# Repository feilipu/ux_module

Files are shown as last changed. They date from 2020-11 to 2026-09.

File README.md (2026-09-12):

# User Experience Module

User Experience Module is designed to use with the RC2014.

It provides a VGA output, and PS/2 keyboard input. It also provides a FTDI Basic serial connector, which normally operates in parallel to the VGA/keyboard.

It is designed to operate as an MC68B50 ACIA device (the standard RC2014 Serial Module), so that it can be used without modifying the standard ROMs in circulation.



## Pictures

<div>
<table style="border: 2px solid #cccccc;">
<tbody>
<tr>
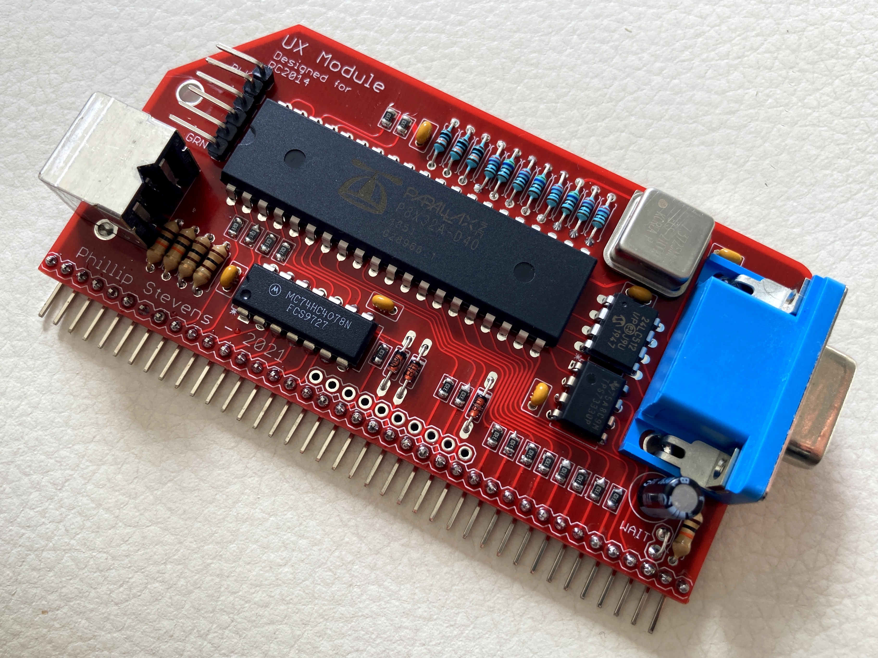
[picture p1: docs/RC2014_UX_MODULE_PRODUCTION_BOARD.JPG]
<td style="border: 1px solid #cccccc; padding: 6px;"></td>
</tr>
<tr>
<th style="border: 1px solid #cccccc; padding: 6px;"><centre>User Experience Module for RC2014 - Production</center></th>
</tr>
</tbody>
<tbody>
<tbody>
<tr>
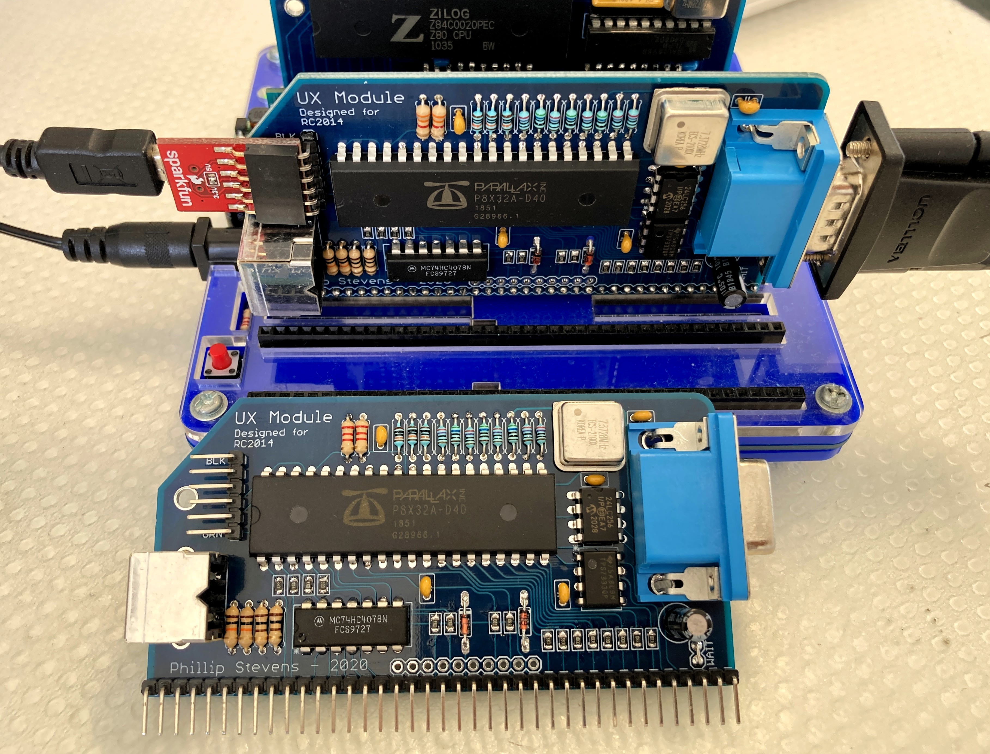
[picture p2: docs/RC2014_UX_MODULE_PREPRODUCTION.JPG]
<td style="border: 1px solid #cccccc; padding: 6px;"></td>
</tr>
<tr>
<th style="border: 1px solid #cccccc; padding: 6px;"><centre>User Experience Module for RC2014 - Pre-Production</center></th>
</tr>
</tbody>
<tbody>
<tr>
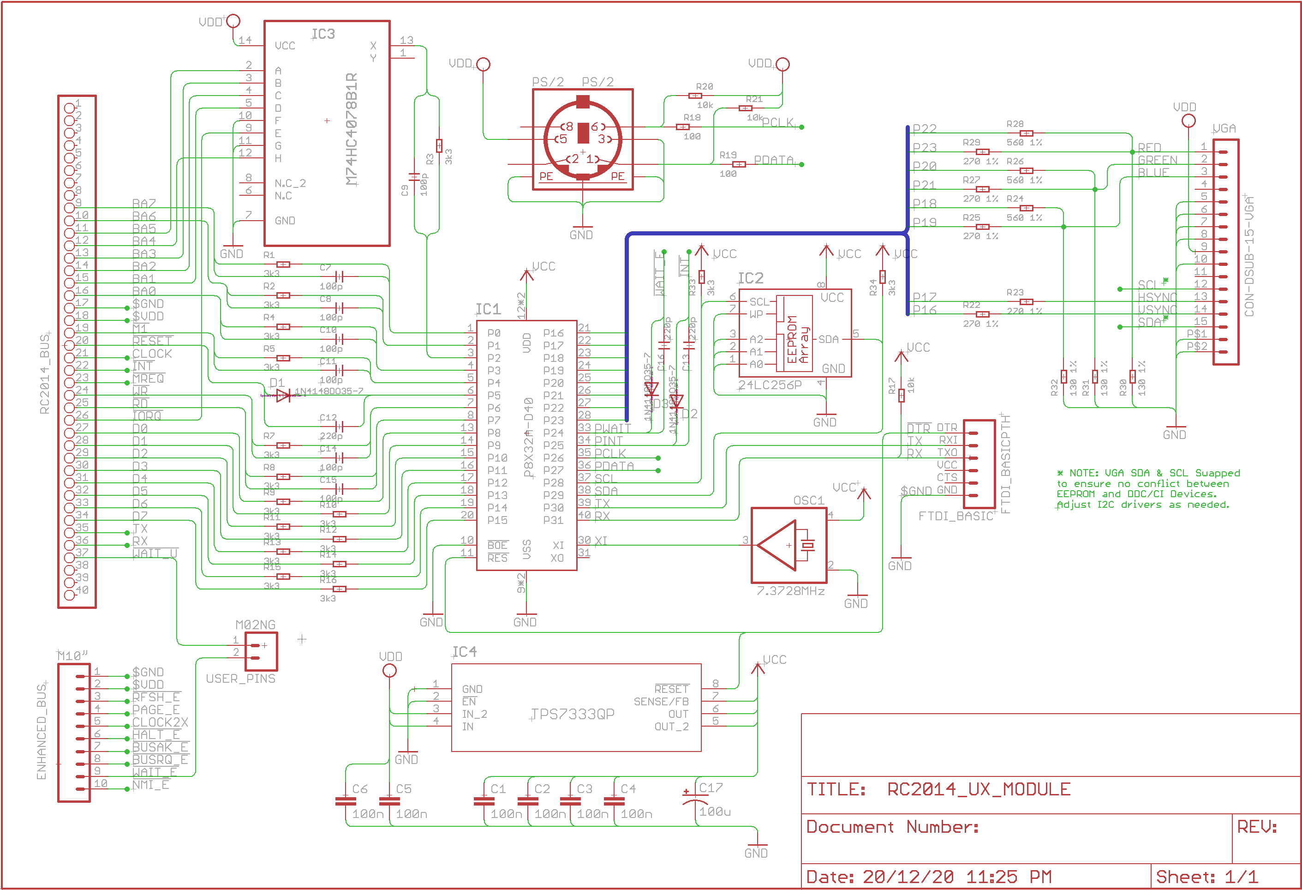
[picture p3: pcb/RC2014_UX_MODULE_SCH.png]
<td style="border: 1px solid #cccccc; padding: 6px;"></td>
</tr>
<tr>
<th style="border: 1px solid #cccccc; padding: 6px;"><centre>User Experience Module for RC2014 - Production Schematic</center></th>
</tr>
</tbody>
</tbody>
<tbody>
<tr>
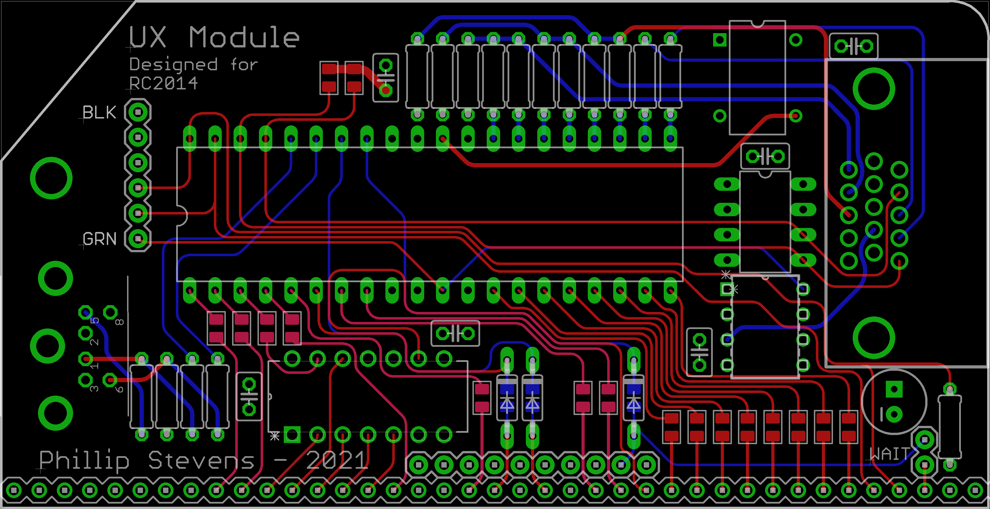
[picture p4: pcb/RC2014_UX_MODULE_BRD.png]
<td style="border: 1px solid #cccccc; padding: 6px;"></td>
</tr>
<tr>
<th style="border: 1px solid #cccccc; padding: 6px;"><centre>User Experience Module for RC2014 - Production Board Layout</center></th>
</tr>
</tbody>
</table>
</div>

## Supported System ROMs

### RC2014 Standard

The UX Module emulates an ACIA interface on base port `0x80`, as per the standard RC2014 usage. Ports `0x80` and `0x81` are required for the implementation.

This supports the use of [standard RC2014 ROMs](https://github.com/RC2014Z80/RC2014/blob/master/ROMs/Factory/README.md) for MS Basic and CP/M as distributed. These ROMs include:

 - R - Microsoft BASIC, for 32k RAM, 68B50 ACIA, with origin 0x0000
 - K - Microsoft BASIC, for 56k RAM, 68B50 ACIA, with origin 0x0000
 - 1 - CP/M Monitor, for pageable ROM, 64k RAM, 68B50 ACIA, CF Module at 0x10, with origin at 0x0000
 - 88 - Small Computer Monitor for pageable ROM, 64k RAM, SIO/2 or 68B50 ACIA, with Microsoft BASIC and CP/M boot options
 - 9 - Small Computer Monitor for any ROM, any RAM, any UART

### CP/M-IDE

The [CP/M-IDE for ACIA](https://github.com/RC2014Z80/RC2014/tree/master/ROMs/CPM-IDE) can be used where an [IDE Interface Module](https://www.tindie.com/products/semachthemonkey/rc2014-ide-hard-drive-module/) is available.

### RomWBW

[RomWBW](https://github.com/wwarthen/RomWBW) is supported, and the UX Module appears as an ACIA port. The UX Module was not compatible with the ACIA device detection mechanism in the 3.0.1 Release, due to the UX Module's tight addressing. However, the device detection mechanism has been improved in the 3.1.1 development branch and it works with the UX Module.

An optimal configuration of RomWBW is to have the UX Module mapped to `0x40`, and a SIO Module providing `TTY` ports. The minimal boot message for this looks like this...

```sh

RomWBW HBIOS v3.1.1-pre.43, 2021-02-11

RC2014 Z80 @ 7.372MHz
0 MEM W/S, 1 I/O W/S, INT MODE 1, Z2 MMU
512KB ROM, 512KB RAM

ACIA0: IO=0x40 ACIA MODE=115200,8,N,1
SIO0: IO=0x80 SIO MODE=115200,8,N,1
SIO1: IO=0x82 SIO MODE=115200,8,N,1
MD: UNITS=2 ROMDISK=384KB RAMDISK=256KB
PPIDE: IO=0x20 PPI NOT PRESENT

Unit        Device      Type              Capacity/Mode
----------  ----------  ----------------  --------------------
Char 0      ACIA0:      RS-232            115200,8,N,1
Char 1      SIO0:       RS-232            115200,8,N,1
Char 2      SIO1:       RS-232            115200,8,N,1
Disk 0      MD1:        RAM Disk          256KB,LBA
Disk 1      MD0:        ROM Disk          384KB,LBA

RC2014 Boot Loader

Boot [H=Help]:
```

To ensure that the UX Module appears as the console port, the console port must be manually set to prefer the UX Module (ACIA) using the `BOOTCON` configuration. The key elements of the configuration file are noted below.

```sh
UARTENABLE  .SET    FALSE       ; UART: DISABLE 8250/16550-LIKE SERIAL DRIVER (UART.ASM)
;
ACIAENABLE  .SET    TRUE        ; ACIA: ENABLE MOTOROLA 6850 ACIA DRIVER (ACIA.ASM)
ACIA0BASE   .SET    $40         ; ACIA 0: REGISTERS BASE ADDR TO AVOID SIO/2 BASE ADDRESS
;
SIOENABLE   .SET    TRUE        ; SIO: ENABLE ZILOG SIO SERIAL DRIVER (SIO.ASM)
SIOCNT      .SET    1           ; SIO: NUMBER OF CHIPS TO DETECT (1-2), 2 CHANNELS PER CHIP
;
TMSENABLE   .SET    FALSE       ; TMS: DISABLE TMS9918 VIDEO/KBD DRIVER (TMS.ASM)
;
BOOTCON     .SET    2           ; SET ACIA AS CONSOLE, ASSUMING 1 SIO/2 MODULE CONFIGURED WITH 2 CHANNELS
```

## Construction

Building the UX Module is fairly straightforward. Some notes are included below describing options and potential issues that may arise.

### BOM

The BOM for the UX Module can be found in the Production PCB section of this repository, both listing [by parts](https://github.com/feilipu/ux_module/blob/main/pcb/RC2014_UX_MODULE_ListByParts.csv), and listing [by values](https://github.com/feilipu/ux_module/blob/main/pcb/RC2014_UX_MODULE_ListByValues.csv).

Also, a complete ordering [Cart is available at Digikey AU](https://www.digikey.com.au/short/47vbdp).

Note that the 74HC4078 NOR device is not included in the Digikey BOM. This device is obsolete, but can be obtained from UT Source or other ebay sources (or as an option on Tindie).

Note that sockets are not included in the BOM, but can be used if desired. See the notes on Overclocking below.

### SMD

Soldering the SMD devices is fairly straightforward. The resistors go on the front of the board. They are not polarised, but if you are concerned with neatness they can all be aligned so they face the same way. The capacitors go on the back of the board. The 3x 220pF capacitors are mounted behind the diodes, and this can be noted because of the through-hole on either side of the mounting location.

There are many techniques for soldering SMD. For a simple tutorial using a standard fine tipped soldering iron and a pair of tweezers, [please refer to this video](https://youtu.be/t7WQLCaeAjM).

### EEPROM I2C

The Parallax Propeller MCU stores its firmware in an external I2C EEPROM. The minimum requirement is for 256kb size (32kB), but the bootloader also supports 512kb size (64kB) devices. Either device is suitable for the UX Module. If you are interested to do additional coding it might be sensible to equip the 512kb device.

There is no need to put the EEPROM in a socket, as it can be programmed in-situ about a million times (literally) and you're never going to need to exchange it.

The bootloader uses P28 as SCL and P29 as SDA. VGA DDC on this board is swapped (P29 SCL, P28 SDA). That match is VGA pin 15 and pin 12. A monitor EDID chip then does not ACK during boot. After boot, `i2c.startCog` in `ddc_i2c.spin` uses that swapped pair to read the display. Do not use that cog to talk to the 24LC256.

### Overclocking

The Parallax Propeller is specified to run at 80MHz. The typical mechanism to achieve this is to provide a 5MHz crystal or oscillator and use the Propeller internal 16x PLL capability to generate the 80MHz system clock.

Of course this specification can be stretched and the maximum system clock seems to be about 120MHz, noting that this is right on the edge of the capabilities.

The UX Module is expecting a 7.3728MHz oscillator, the same standard clock as the RC2014 Z80, which produces a 118MHz Propeller system clock.

It is possible to use a slower oscillator at 5MHz, or 6.25MHz, or other if desired, or in the unlikely event your selected Propeller device doesn't work at 118MHz. In this case the clock rate specification [`_xinfreq`](https://github.com/feilipu/ux_module/blob/main/src/ux_module.spin#L12) will have to be adjusted in the firmware to suit, and the VGA video timing will need to be adjusted to suit. If you are concerned about this it would be sensible to mount the oscillator in a socket to enable it to be simply swapped as needed.

## Firmware Development

The UX Module firmware is developed in Propeller SPIN, and in Propeller Assembly (PASM). The individual functions are mainly built in PASM, with connecting higher level logic running in SPIN.

### Development Environment (humans)

There are a number of alternative programming environments for the Parallax Propeller. The PropellerIDE was defined as the default option, and was developed to be cross-platform capable. However, other solutions supporting SPIN, PASM, and C or C++ are also available.

The UX Module is developed using the PropellerIDE, and therefore support will only provided for issues with that platform.

The [PropellerIDE](https://developer.parallax.com/propelleride/) is available for Windows, OS X, Linux, and packaged for debian.

### Command-line build (humans, agents, and scripts)

Use the CLI toolchain. PropellerIDE remains valid for interactive work. Both paths target **Propeller 1 (P8X32A)** only. Do not use Propeller 2 loaders (`loadp2`) or PASM2.

| Tool | Role | Source |
|---|---|---|
| [OpenSpin](https://github.com/parallaxinc/OpenSpin) (`openspin`) | Compile Spin and PASM to a `.binary` or `.eeprom` image | Build from source (for example `~/Projects/OpenSpin`) |
| [PropLoader](https://github.com/parallaxinc/PropLoader) (`proploader`) | Load the image over FTDI FT232 (DTR reset) | Build from source (for example `~/Projects/PropLoader`) |
| `tools/ux-load.sh` | EEPROM load + run on `/dev/cu.usbserial-*` | This repository |
| `tools/ux-screen.sh` | 115200 FTDI console. Holds DTR off | This repository |
| `rc-screen` (`tools/rc-screen.sh`) | 115200 ACIA console on USB CDC. Direct GNU `screen` | `$HOME/bin` |

Copy this block. Quit GNU `screen` first (`C-a k`). The serial port must be free.

```sh
mkdir -p build
openspin -L src -b -o build/ux_module.binary src/ux_module.spin
tools/ux-load.sh
tools/ux-screen.sh
```

Top object is `src/ux_module.spin`. Product search path is `-L src` only. Add `-L src/lib_vjet` only for a VECTORJET demo top.

`tools/ux-load.sh` writes EEPROM then runs. It uses DTR reset (SparkFun FTDI Basic pin 6). It refuses USB CDC (`/dev/cu.usbmodem*`). CDC is console only.

Same load without the helper. Adjust the device from `proploader -P`. Prefer `/dev/cu.*` over `/dev/tty.*` on macOS.

```sh
proploader -p /dev/cu.usbserial-XXXX -e -r build/ux_module.binary
```

Full helper notes, VECTORJET compile, and screen keys: [`tools/README.md`](tools/README.md). Agent rules: `AGENTS.md`, `.agents/skills/tool-propeller/`, and `.agents/skills/tool-rc-screen/`.

### Programming Interface

The UX Module provides a standard FTDI Serial interface for programming. This can optimally be at 3V3, but also works at 5V. References to "Prop Plug" in the PropellerIDE should be taken to mean the FTDI Serial device that you're using. The same FTDI FT232 path is what `proploader` uses from the command line.

When programming the UX Module firmware with PropellerIDE, it is important that the [upper level code](https://github.com/feilipu/ux_module/blob/main/src/ux_module.spin) be the active window when clicking "compile and upload". The PropellerIDE will compile and upload a sub-module file if it thinks this is what you wanted (because you left it in the foreground). Of course this will lead to things not working as expected. You'll just need to do it again with the upper most code in the foreground.

### Source Code Hierarchy

Propeller SPIN works with modules which help to mask details from driver code from upper level code.

To implement the functions required for the UX Module several SPIN/PASM modules previously written for Propeller by Parallax have been used. This means that the pretested modules from the Parallax "Object Exchange" are used, and that we can focus on how these modules are integrated.

The only (at this stage) special PASM functions written for the UX Module are in the implementation of the ACIA MC6850 Serial Interface. These are in the [ACIA module](https://github.com/feilipu/ux_module/blob/main/src/acia_rc2014.spin).

`ddc_i2c.spin` also runs a Spin cog after boot. It talks to the monitor on the VGA DDC pins (swapped vs the boot EEPROM). It reads EDID at `0x50` and, if the display answers, DDC/CI at `0x37`. It does not change VGA timing.

VECTORJET (`src/lib_vjet`) is not linked from the product top. Boot is text VGA only. Compile VECTORJET demos with their own tops.

```
ux_module
|
|---> terminal_ftdi 
|---> keyboard_ps2
|---> acia_rc2014
|---> ddc_i2c
|---> wmf_terminal_vga
      |
      |---> hires_text_vga
```

## Usage Notes

When the UX Module has been programmed successfully, it should boot with `UX Module Initialised` appearing on both VGA interface (screen) and on the FTDI Serial interface.

To reboot the UX Module the `DTR` on the FTDI interface needs to be toggled. This can be done with the PropellerIDE, or with any serial terminal that can trigger `DTR` toggle. This functionality is used by the Arduino family, so the function is quite common within serial terminals.

To reboot the UX module if operating stand-alone, the DTR (`GRN`) pin can be touched to the ground (`BLK`) pin on the serial interface, or alternatively touched to the grounded case of the PS/2 keyboard connector.

Once the UX Module is running the ACIA emulation is enabled, so the RC2014 Z80 can now be rebooted. This can be done by pressing the RESET button on the RC2014 or, if a PS/2 keyboard is attached, by pressing `CTRL+ALT+DEL`. This will now initiate a normal RC2014 boot sequence.

This video below shows the expected output of a session.

UX Module for RC2014 Operation (https://www.youtube.com/watch?v=dZT0yxjd9zs)
<BR>
CLICK IMAGE TO VIEW!

### Ports

The UX Module emulates an ACIA interface on base port `0x80`, as per the standard RC2014 usage. Ports `0x80` and `0x81` are required for the implementation.

The UX Module can be alternately located on ports `0x40`, `0x41` or on `0xC0`, `0xC1`.

It will (enhancement plan) be possible to implement a graphics interface (VJET library). It is likely that the graphics interface will use the `0xC0` and `0xC1` ports, and may be configured by settings on other ports.

`PORT_VJET` in `ux_module.spin` is that reserved `0xC0` base. There is no Z80 command protocol in the tree yet. Boot remains the ACIA text console.

### Video VGA

If you do not have a VGA monitor, it is possible to attach a VGA->HDMI adaptor. The VGA connector on the UX Module supplies 5V to the adaptor so no additional power connection (via USB) is required. The recommended VGA->HDMI adaptor is from [Vention and is available here](https://www.aliexpress.com/item/32844619223.html).

The VGA timings (front porch and back porch) have been developed using the Vention HDMI adaptor. If an alternative HDMI adaptor or actual VGA monitor is used, the timings may need to be adjusted to ensure that all characters are visible.

The active text table in `hires_text_vga.spin` is 640×480 at about 70 Hz (80×40 characters). Other Chip Gracey tables (1024×768, 800×600, 640×480 at 85 Hz) are in the same file, commented out. Timing is compile-time. EDID reports the preferred mode. DDC/CI cannot set resolution or aspect. Many HDMI adaptors answer EDID and do not answer DDC/CI (`0x37`).

### Keyboard PS/2

The keyboard is presumed to be a [USA standard](https://github.com/feilipu/ux_module/blob/main/src/keyboard_ps2.spin) keyboard. Alternate key maps are possible, and can be added to your own build of the firmware.

### RC2014 Bus Tx/Rx Line Conflict

When multiple serial Modules are used on one RC2014 Backplane, there is a potential for conflict on the Tx/Rx lines, Pin 35 and 36. Conflict on the the Bus Tx/Rx lines will prevent the RC2014 from booting correctly.

The UX Module is connected to the RC2014 Bus serial Tx and Rx lines. When using the UX Module with other serial Modules (such as the SIO/2 Module), it is necessary to disconnect one or other of the serial Modules. In practice the easiest way to do this is to straighten either the UX Module or SIO/2 Module Tx and Rx pins sufficiently so that they do not insert into the Bus connector.

## Errata Propeller /RESET Pin

The Propeller MCU `/RESET` pin is driven by the serial interface `DTR` pin, which is normally held high when the port is ready. However sometimes both Linux (MacOS) and Windows toggle `DTR` when opening a new serial interface. This impacts our ability to use the serial interface to upload code to the RC2014.

There are several options proposed on the internet to avoid this issue (mainly driven by Arduino users wanting to have "long running" code). The solutions are written into [`tools/serial_tool.py`](tools/serial_tool.py), which is included to simplify uploading BASIC programs to the RC2014.

For some machines, none of the software options work so the final solution is to bend the `DTR` pin out from the FTDI connector. Then an optional connection can be provided to enable Propeller reprogramming. Photos demonstrating one method to do this are provided in the [`docs`](https://github.com/feilipu/ux_module/tree/main/docs) directory.

## Code of conduct

See the [Code of Conduct](https://github.com/feilipu/ux_module/blob/main/CODE_OF_CONDUCT.md).

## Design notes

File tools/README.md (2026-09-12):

# Compile, load, and console

Copy these commands from a clone of this repository. Product firmware is Propeller 1 only (`P8X32A`).

Put `openspin` and `proploader` on `PATH`. Build notes: `.agents/skills/tool-propeller/SKILL.md`.

Quit GNU `screen` before a load (`C-a k`). `tools/ux-load.sh` then stops the FTDI relay so the port is free.

Two consoles: `ux-screen` is SparkFun FTDI (DTR is `/RES`, relay). `rc-screen` is RC2014 ACIA on USB CDC (direct attach). Both live in `$HOME/bin`.

## Product firmware

Top object: `src/ux_module.spin`. Search path: `-L src` only.

```sh
cd /path/to/ux_module
mkdir -p build
openspin -L src -b -o build/ux_module.binary src/ux_module.spin
tools/ux-load.sh
tools/ux-screen.sh
```

`tools/ux-load.sh` writes EEPROM and then runs. It uses DTR reset on `/dev/cu.usbserial-*` (SparkFun FTDI Basic pin 6). It refuses `/dev/cu.usbmodem*` (USB CDC). That path is console only.

```sh
tools/ux-load.sh /dev/cu.usbserial-XXXX
tools/ux-load.sh -m                       # hand pulse /RES
tools/ux-screen.sh /dev/cu.usbserial-XXXX
tools/serial_probe.py $'ABC123\r'         # headless TX/RX log, DTR held off
```

Same load without the helper:

```sh
proploader -P
proploader -p /dev/cu.usbserial-XXXX -e -r build/ux_module.binary
```

## VECTORJET demo (not the product top)

```sh
openspin -L src -L src/lib_vjet -b -o build/vjet_test.binary src/lib_vjet/vjet_test.spin
```

## Console keys (`tools/ux-screen.sh`)

| Key | Action |
|-----|---|
| `C-a k` | Quit screen (do this before `ux-load.sh`) |
| `C-a d` | Detach |
| `C-a s` | XMODEM send (`lsx -b -q -X`). Type the file path. |
| `C-a r` | XMODEM receive (`lrx -b -q -X`) |

If `lsx`/`lrx` exits and the window no longer takes keys, quit (`C-a k`) and run `tools/ux-screen.sh` again. Apple `/usr/bin/screen` used to wrap `exec` in `login`. `tools/screenrc-ux` now sets `deflogin off`.

Do not pass baud flags to GNU `screen` on the PTY. Apple `screen` then treats that node as a modem and can raise DTR or send a break. `tools/ux-screen.sh` runs `stty -ixon` on the PTY. An XOFF byte from the 8085 then does not block host keys.

`tools/ux-ftdi-relay.py` holds DTR off. macOS asserts DTR on open of `cu.usbserial-*`. That pin is Propeller `/RES`. The relay stays up after you quit `screen`. A later `ux-screen` does not reopen the FTDI. The GNU `screen` session name is `uxmod`. A second `ux-screen` reattaches that session. The first start after a USB plug or `ux-screen.sh --stop` still pulses `/RES`. `tools/ux-load.sh` stops the relay, then uses DTR for the download.

Older pyserial helpers (Linux `/dev/ttyUSB0` in the source): `tools/serial_dtr.py` pulses DTR. `tools/serial_tool.py` writes stdin to the port and comments HUPCL options. Prefer `tools/ux-load.sh` and `tools/ux-screen.sh` on macOS.

## RC2014 ACIA console (`rc-screen`)

GNU `screen` opens the USB CDC node (`/dev/cu.usbmodem*`) directly. There is no FTDI relay and no `serial_probe`. The session name is `rc2014`.

General command: `$HOME/bin/rc-screen`. Config: `$HOME/.screenrc-rc`. In-tree copies: `tools/rc-screen.sh` and `tools/screenrc-rc`.

This is the CP/M console on the 8086 Consultancy USB-C stick. Do not use this script on `/dev/cu.usbserial-*`. That FTDI pin 6 is Propeller `/RES`. Use `ux-screen` for the SparkFun port.

```sh
rc-screen
rc-screen /dev/cu.usbmodem01031
rc-screen --list
rc-screen --quit
```

Sockets are in `$HOME/.screen-rc2014`. A bare `screen -S rc2014` looks in `$TMPDIR/.screen` and misses the session. Use `rc-screen --quit` to stop it.

A terminal attaches. With no TTY the script starts a detached session. One session only.

Same keys as `ux-screen`: `C-a s` send, `C-a r` receive. The screenrc sets `deflogin off` and unbinds XON.

Host send after CP/M `xmodem NAME /r /q`:

```sh
rc-screen --send /path/to/file.com
rc-screen --send --1k /path/to/file.com
```

`--send` waits one second so CP/M is in receive first. The script starts `screen` with `115200,cs8,-ixon,-ixoff`. A missing baud flag makes Apple `screen` reset the node to 9600.

If `ux-ftdi-relay` holds the same CDC node, quit session `uxmod` and run `ux-screen --stop` first. Do not run both scripts on one node.

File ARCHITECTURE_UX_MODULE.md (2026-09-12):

# Architecture — UX Module firmware

This note describes the production firmware under `src/` (not `src/lib_vjet`).  
MCU: **Parallax Propeller 1 (P8X32A) only** — not Propeller 2.  
Agent edit rules: `.agents/skills/module-ux`, `hw-ux-pcb`, `lang-spin`, `lang-pasm`, `tool-propeller`.  
Prose style: `.agents/skills/style-ste-writing`.

## Purpose

The UX Module is an RC2014 board that presents:

- VGA text console
- PS/2 keyboard
- FTDI serial (programming + parallel console)
- An MC6850-compatible ACIA on the Z80 I/O bus

Host software can use stock RC2014 ROMs that expect a 68B50 ACIA. The Propeller P8X32A runs the firmware. Primary product documentation is `README.md`. Board files are under `pcb/`. Chip and language manuals are under `docs/`.

## Clock

The board uses a 7.3728 MHz oscillator. Firmware sets `XTAL1 + PLL16X`, so the system clock is about 118 MHz. VGA pixel-rate constants in `hires_text_vga.spin` assume that clock. A different oscillator needs a new `_xinfreq` and new video timing.

## Object hierarchy

```
ux_module.spin
├── terminal_ftdi.spin      Full-duplex UART on P31/P30 (Prop Plug pins)
├── keyboard_ps2.spin       PS/2 decode on P27 data / P26 clock
├── acia_rc2014.spin        6850 register and bus timing emulator
├── ddc_i2c.spin            DDC EDID / DDC/CI Spin cog (P29 SCL / P28 SDA, swapped)
└── wmf_terminal_vga.spin   Screen buffer, colours, terminal print helpers
    └── hires_text_vga.spin Dual-cog VGA text engine (Parallax / Chip Gracey)
```

Compile and upload with `ux_module.spin` as the top object. Use `-L src` only. VECTORJET lives under `src/lib_vjet` with its own demo tops. The product top does not link it.

## Pin roles (summary)

| Function | Pins |
|---|---|
| ACIA address and control | P0–P7 (A7, A6, NOR decode, A0, /M1, /RESET, /WR, /RD) |
| ACIA data | P8–P15 |
| VGA | P16–P23 |
| /WAIT, /INT | P24, P25 (open-collector via diodes) |
| PS/2 | P26 clock, P27 data |
| I2C EEPROM (bootloader) | P28 SDA, P29 SCL |
| VGA DDC (after boot) | P29 SCL, P28 SDA (`ddc_i2c.spin`). Swapped so EDID does not ACK the bootloader. |
| FTDI | P30 TX, P31 RX |

The 74HC4078 NOR combines `/IORQ` with A5–A1 so one Propeller pin can detect the ACIA I/O page. Detail: skill `hw-ux-pcb` and comments in `acia_rc2014.spin`.

## Cog map

Typical production start order in `ux_module.main`:

1. FTDI terminal cog (`terminal_ftdi.start`)
2. ACIA cog (`acia.start`)
3. Two VGA text cogs (`wmf.init` → `hires_text_vga.start`)
4. DDC I2C cog (`i2c.startCog` in `ddc_i2c.spin`) after VGA so the monitor is alive
5. PS/2 cog (`kbd.start`)
6. 1 ms Z80 `/RESET` pulse. Discard FTDI RX and restart the ACIA cog while held. A backplane `/RESET` button is sampled on P5 (1 ms debounce) and uses the same wipe. It does not reset the Propeller.
7. Cog 0 remains in the main Spin loop (`kbdToZ80`, `termToZ80`, `readZ80`)

Text mode uses seven of eight cogs. I2C is a Spin cog, not PASM. It reads EDID and DDC/CI. It does not change VGA timing. The spare cog is unused. Only the main cog calls `acia.tx`. Main skips `kbdToZ80` during a Z80→host XMODEM session (`z80XmSess`, including the ACK gap) and a host→Z80 packet session (`hostXm <> OFF`). Trailer bytes are counted, not sniffed. DDC still runs while the 8085 is live. Do not hold `/RESET` across DDC.

## Data paths

```
Keyboard  →  kbdToZ80  ─┐
                        ├─ acia.tx → ACIA transmit FIFO → Z80 IN data
FTDI RX   →  termToZ80 ─┘
Z80 OUT data  →  ACIA receive FIFO  →  readZ80  →  VGA + FTDI TX
```

`readZ80` is a non-blocking parser. It pumps bytes already in the FIFO. LF still drains when FTDI TX is full. Other bytes wait for FTDI room. If the next byte will not fit, `readZ80` holds ACIA `TDRE`. There is no XON/XOFF on FTDI. The FTDI RX cog drops inbound bytes when its FIFO is full. The 6-pin header does not wire CTS or RTS to the Propeller, so the host cannot be paused in hardware.

Naming trap: from the Z80, “receive data register” is filled by the Propeller **transmit** FIFO (`tx_*`). “Transmit data register” writes enter the Propeller **receive** FIFO (`rx_*`).

## ACIA emulation

`acia_rc2014.spin` runs a PASM cog that:

1. Waits for the decoded address match (including `/M1` high for I/O)
2. Pulls `/WAIT` so the Z80 stretches the cycle
3. Services status/control at base+0 or data at base+1
4. Releases `/WAIT` and returns to wait

A real MC68B50 places data in 150 ns or less. This cog is slower, so P24 stretches the Z80 I/O cycle. Address detect uses `WAITPNE` then `waitpeq outa, port_active_mask wr`. The `wr` effect adds the mask into `OUTA`. Bit 24 was already 1, so the add drives `/WAIT` low in that instruction.

Carry hits bit 25 (`/INT`). The next instruction clears that bit. Do not drop `wr`. Loop rules live in `.agents/skills/lang-pasm/references/acia-wait.md`.

Status and control bits follow the Motorola 6850 model (`docs/MC6850.pdf`) at a practical level. FIFOs stand in for the UART. Clock divide, word select, and Break are not driven. PE, FE, CTS, and DCD stay 0. Default base is `0x80`. RomWBW setups may use `0x40` when an SIO owns `0x80`.

FIFOs are 512 bytes each. Z80 receive is the Propeller `tx_*` FIFO (`RDRF`). Z80 transmit is the Propeller `rx_*` FIFO (`TDRE`). Spin `tx` and `rx` move bytes. `sync_irq` writes `acia_status` on a status read.

PASM holds `/INT` low while RIE or TIE match the flags. Spin also pulses `DIRA[25]` when RIE or TIE, so a key is seen while PASM is in `waitpeq`. `/RTS` is the CR5/CR6 field. Master reset `$03` sets `req_parse_idle` then zeros both FIFOs. It does not clear `tdre_hold`. Boot pulse and CTRL+ALT+DEL hold P5 for 1 ms, discard host RX, and restart the ACIA cog so FIFOs and `last_rdr` are zero. Then `tdreHold` until FTDI has room. Do not wait on `req_master`. An empty or `/RTS`-high RDR read presents the last byte and does not move `tx_tail`. A full TDR write is dropped and does not set `OVRN`. Spin `tdreHold` writes Hub `tdre_hold` so PASM keeps `TDRE` clear. Detail and revert notes: `.agents/skills/module-ux`. RomWBW and CPM-IDE ACIA clients: `.agents/skills/module-ux/references/acia-host-drivers.md`.

## FTDI UART cog

`terminal_ftdi.spin` keeps receive and transmit in **one** PASM cog with `JMPRET` coroutines (Parallax AN014 pattern on OBEX). Bit timing uses `CNT` deadlines. That saves a cog versus two separate UART cogs.

## VGA text path

`wmf_terminal_vga` owns the character buffer, per-row colours, and cursor bytes. `hires_text_vga` reads those Hub structures and generates VGA with two cogs. Resolution and character grid depend on which timing `CON` block is active in `hires_text_vga.spin` (for example 640×480 with 80×40 characters).

The active block is 640×480 at about 70 Hz (VGA 60 Hz 800×525 totals, `pr=28`). EDID preferred timing is reported at boot. It does not retune this table. DDC/CI does not set resolution.

Cursors are six bytes: text X/Y/mode and mouse X/Y/mode. The UX Module uses the text cursor and leaves the mouse cursor disabled. Overlay X/Y copies the WMF column and row after text ops. Idle backspace at column 0 is eaten. The firmware does not guess a shell prompt width.

## Relation to VECTORJET

`src/lib_vjet` is not linked from the product top. Compile VECTORJET demos with their own top objects and `-L src -L src/lib_vjet`. Pins P16–P23 have one owner. See `ARCHITECTURE_LIB_VJET.md`.

## External references

| Doc | Use |
|-----|-----|
| `tools/README.md` | Copy compile, `ux-load.sh`, `ux-screen.sh`, and `rc-screen.sh` |
| `docs/P8X32A-Web-PropellerManual-v1.2.pdf` | Spin and PASM language |
| `docs/Propeller Quick Reference v1.7.pdf` | Opcode and Spin cheat sheet |
| `pcb/P8X32A-Propeller-Datasheet-v1.4.0_0.pdf` | Hub, video, counters, electrical |
| `docs/MC6850.pdf` | ACIA register model |
| `pcb/RC2014_UX_MODULE.sch` | Board connectivity |

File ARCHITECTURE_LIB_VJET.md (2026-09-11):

# Architecture — VECTORJET (`lib_vjet`)

This note describes the 2D/3D scanline engine under `src/lib_vjet`.  
Agent edit rules: `.agents/skills/library-vjet`, `hw-propeller`, `lang-pasm`.  
Prose style: `.agents/skills/style-ste-writing`.

## Purpose

VECTORJET builds a display list in Spin, renders scanlines with one or more PASM cogs, and outputs VGA with a dedicated PASM cog. The UXM-prefixed files are a specialisation for the RC2014 UX Module pinout and clock. Upstream credit in the sources: IRQsome Software, with VGA lineage from Kwabena W. Agyeman / Parallax-style video generators.

The product top `ux_module.spin` does not link this library. Demos use their own top objects (`vjet_test.spin`, `graphtest.spin`). Compile those with `-L src -L src/lib_vjet`.

## Files

| File | Layer |
|---|---|
| `VJET_v01_displaylist.spin` | Spin API: clip, shapes, text, list packing |
| `VJET_vUXM_rendering.spin` | PASM renderer cog program |
| `VJET_vUXM_vga.spin` | PASM VGA output cog |
| `hexfont.spin` | Font blob for text shapes |
| `vjet_test.spin` | Demo: spinning triangles + centred text |
| `graphtest.spin` | Demo: graph-style drawing |

## Runtime pipeline

```
Application (Spin top object)
    │
    │  build display list into back buffer
    │  publish pointer in dlist_ptr
    │
    ├───────────────► Render cog 0 ──┐
    ├───────────────► Render cog 1 ──┼──► shared scanline buffer (Hub)
    └───────────────► Render cog N ──┘              │
                                                    ▼
                                            VGA cog (WAITVID)
                                                    │
                                                    ▼
                                            pins P16–P23 (group 2)
```

`vjet_test.spin` starts three render cogs and one VGA cog. It waits for vertical blank through `vga_status`, publishes the completed list, waits for vsync so the render cogs copy the pointer, then rebuilds the other list.

## Scanline handshake (tear / flicker)

The Hub scan buffer holds **eight** logical lines (`LINE_BUFFERS`). The VGA cog displays line `N` from slot `N & 7` and writes `N` into `vga_status`. During blanking it writes line **240** plus phase bits.

Render cogs:

1. Wait until the status line is `>= 240` (blanking).
2. Fill slots 0..7 while they treat the raster as line 0.
3. Then wait until they are fewer than eight lines ahead of the live VGA line.

Do not publish line 0 during vsync or back porch. The old status longs used a low word of 0. Render cogs treated that as scanline 0, ran 16 lines, and overwrote the first eight slots before active video. A faster system clock (118 MHz vs 80 MHz) made that overrun worse.

Spin must publish `dlist_ptr` at front porch, then wait for vsync bit 17 (`$02_00_00`) before it rebuilds the other list. If Spin rebuilds a list that a render cog still reads, the frame tears.

## Video PLL

`VJET_vUXM_vga` sets CTRA PLL internal, VCO/2. The NCO target is 5 MHz. VCO is 80 MHz (spec 64–128 MHz). PLLA is 40 MHz. VSCL uses 4 clocks per pixel, so the pixel rate is 10 MHz (256-wide VGA).

The old 10 MHz NCO with VCO/4 made VCO 160 MHz. That is out of spec and the PLL can unlock (jitter, tear, roll).

`hires_text_vga` uses a different PLL setup (`pr` in MHz, VCO/2) for 640×480 text. Do not copy VECTORJET FRQA into the text driver or the reverse.

## Resolution and buffers

Rendering constants in `VJET_vUXM_rendering.spin`:

- Width: 256 pixels
- Height: 240 scanlines

The VGA cog repeats each logical line (tile counter) so the analogue timing fills a taller raster. The Hub scan buffer is `linebuffers[(WIDTH*LINE_BUFFERS)/4]` longs (eight line slots).

Display lists are ordinary Hub longs (for example `dlist1[900]`, `dlist2[900]`). Size is a demo choice, not a hardware limit.

## Display list model

Each shape starts with an 8-byte header:

1. Link word to the next shape (0 = end)
2. Sync byte for renderer coordination
3. Shape type byte
4. Start scanline word
5. End scanline word

Types:

| ID | Name | Role |
|----|---|---|
| 1 | Trapezoid stack | Filled poly/triangle decomposition with per-trap slopes |
| 2 | Box | Axis-aligned span with colours |
| 3 | Text | Scaled glyphs from a font pointer + string pointer |

The Spin builder exposes helpers such as `triangle`, `polygon`, `box`, `line`, `point`, and `text_centered`. Many coordinates use 16.16 fixed point. `set_clip` limits geometry. `done` seals the list and breaks the link if the builder ran out of space (`ABORT`).

## Renderer cog behaviour

On `start(cognum, totalcogs, scanbuffer, dlistPtrAdr, videoSync, readyptr)` the object copies parameters into DAT longs and `cognew`s the PASM entry.

Each cog:

1. Waits until `vga_status` low word is `>= 240` (blanking)
2. Reads the current display-list pointer
3. Optionally fixes trapezoids that start above Y0 (top clip)
4. Renders every Nth scanline (`cognum`, `cognum+totalcogs`, …)
5. Writes pixels into the shared scanline buffer for the VGA cog
6. Waits if the next line would wrap onto a slot the VGA cog still displays

Call `render.stop` before you start text VGA on the same pins.

Init instructions are overlaid by live variables after boot. Do not treat early DAT labels as free code space without reading the reuse comments.

## VGA cog behaviour

`VJET_vUXM_vga.start(pinGroup, lineBuffers, statusLong)`:

- Programs `VCFG` for VGA on the selected pin group
- Starts CTRA in PLL video mode
- Loops active lines with `WAITVID`, then front porch, vertical sync, and back porch
- Publishes phase flags in `statusLong` so Spin can wait for blanking
- Writes line 240 during front porch, vsync, and back porch (never line 0)

For the UX Module, demos pass `pinGroup = 16/8` (group 2 → P16–P23), which matches the board VGA connector.

## Integration with UX firmware (exclusive video mode)

Pins P16–P23 have one owner. `hires_text_vga` (two cogs, 640×480 cells) and `VJET_vUXM_vga` (one cog, 256×240 scanlines) must not run at the same time.

| Mode | Video cogs | Other cogs that stay | Free |
|---|---|---|---|
| Text | 2 (`hires_text_vga`) + 1 I2C DDC | Spin, FTDI, ACIA, PS/2 (4) | 1 |
| Graphics | 1 (`VJET_vUXM_vga`) + 2 render | Spin, FTDI, ACIA, PS/2 (4) | 1 (Spin draw) |

The product firmware does not call `enterGraphics`. When graphics work resumes, stop the text pair and `i2c.stopCog` before VECTORJET VGA. Stop VECTORJET, then `wmf.init` and `i2c.startCog`. After `cogstop`, those cogs leave the pins. Then start the other driver.

Do **not** build the display list on Cog 0 if the ACIA pump must stay live. Cog 0 is the only `acia.tx` writer. `vjet_test` blocks Cog 0 in `Vblank` + `draw`. That starves keyboard, FTDI, and Z80 I/O.

Recommended product split:

1. **Text mode** — current `ux_module` path. Z80 console on VGA text.
2. **Graphics mode** — stop text VGA. Start VECTORJET VGA + two render cogs. Start a **second Spin cog** that waits for blanking and builds lists. Cog 0 only pumps ACIA / keyboard / FTDI and writes a small mailbox (camera, mode, flip). That uses all eight cogs: 4 I/O + 1 draw + 1 VGA + 2 render.
3. **Standalone demo** — `vjet_test` / `graphtest` as now (no ACIA). Three render cogs on Cog 0 as the draw loop.

The product top has no graphics hooks. `PORT_VJET` remains a reserved ACIA base. Serial tests use the text boot path.

Hub cost: eight line slots are 2 KB. Two lists of 900 longs are about 7 KB. The text screen is 80×40 bytes plus colours. 32 KB Hub cannot keep a large text buffer and two fat lists at once. Reuse the text screen region for lists when you leave text mode.

`PORT_VJET = acia#PORT_C0` is reserved for a later Z80 command port. There is no I/O protocol in-tree yet. A first protocol can be: command byte, then words that Spin copies into the back list, then a flip at vblank.

## Extension points

Useful work while keeping the architecture intact:

1. When graphics work resumes, start a Spin draw cog (not Cog 0). Wait `vjetStatus` bit 16 (`$01_00_00`), publish the list pointer, wait bit 17 (`$02_00_00`), then `gl.start` on the idle list. See `vjet_test.spin`.
2. Grow Hub lists to two buffers of about 900 longs. Reuse the text screen region if needed.
3. Drive the back list from Z80 I/O at `PORT_VJET` (needs a command protocol)
4. Tune render cog count against available cogs and fill rate
5. Keep display-list field layouts documented in one place (builder comments ↔ renderer reads)
6. Link `hexfont.spin` only when text shapes are required. Do not start VECTORJET from product `main` until that draw cog exists.

## External references

| Doc | Use |
|-----|-----|
| `pcb/P8X32A-Propeller-Datasheet-v1.4.0_0.pdf` §4.10 | Video generator, WAITVID |
| `docs/Propeller Quick Reference v1.7.pdf` | PASM opcodes |
| `ARCHITECTURE_UX_MODULE.md` | Board cog and pin budget |
| Demo sources | `vjet_test.spin`, `graphtest.spin` |

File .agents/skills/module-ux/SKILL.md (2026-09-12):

---
name: module-ux
description: >
  UX Module firmware architecture: ux_module.spin object tree, cog budget,
  ACIA 6850 emulation path, VGA text terminal, PS/2 keyboard, FTDI bridge,
  and Z80 console flow. Use when changing src/ outside lib_vjet, or when
  integrating VECTORJET with the product firmware. See ARCHITECTURE_UX_MODULE.md.
---

# Module — UX firmware

Human architecture note: `ARCHITECTURE_UX_MODULE.md` (repo root). This skill is the agent checklist.

## Object tree

```
ux_module.spin                 ' top object — compile/upload this
├── terminal_ftdi.spin         ' FullDuplex serial on P31/P30
├── keyboard_ps2.spin          ' PS/2 on P27/P26
├── acia_rc2014.spin           ' MC6850 bus emulator (PASM cog)
├── ddc_i2c.spin               ' DDC EDID / DDC/CI Spin cog (P29 SCL, P28 SDA)
└── wmf_terminal_vga.spin      ' terminal services + screen buffer
    └── hires_text_vga.spin    ' dual-cog VGA text (Chip Gracey)
```

Boot is text VGA only. There is no DIAG_ switch. VECTORJET stays under `src/lib_vjet` with its own demo tops. Do not link it from `ux_module.spin` until graphics work resumes (`library-vjet`).

Archive demos under `archive/` are not part of the production tree.

## Cog budget (production path)

| Cog role | Source |
|---|---|
| Spin main (Cog 0) | `ux_module` event loop: `kbdToZ80` / `termToZ80` / `readZ80` |
| FTDI UART | `terminal_ftdi` PASM |
| ACIA bus | `acia_rc2014` PASM |
| PS/2 | `keyboard_ps2` PASM |
| VGA text ×2 | `hires_text_vga` (two cogs) |
| I2C DDC | `ddc_i2c` Spin cog (EDID + DDC/CI). Not the boot EEPROM. |

Text mode uses seven of eight cogs. I2C is a Spin cog, not PASM. The spare cog is unused. Only the main cog calls `acia.tx`. Main skips `kbdToZ80` during a Z80→host session (`z80XmSess`) and a host→Z80 packet session (`hostXm <> OFF`).

## Main loop data paths

```
PS/2 keyboard ──kbdToZ80──┐
                          ├── acia.tx ──► ACIA tx FIFO ──► Z80
FTDI rx ──termToZ80───────┘
Z80 writes data ──► ACIA rx FIFO ──readZ80──► VGA + FTDI
```

Cog 0 is the only `acia.tx` writer. Do not add a pump cog. Each of `kbdToZ80`, `termToZ80`, and `readZ80` moves at most `PUMP_LIMIT` bytes per pass.

`readZ80` is a non-blocking parser (`PARSE_IDLE` / `PARSE_ESC` / `PARSE_CSI` / `PARSE_CSI_M` / `PARSE_XMODEM_*`). Each call uses bytes that are already in the FIFO. Pump `ftdiNeed==0` bytes even when FTDI TX is full. Allow `TDRE` only when the next byte fits.

`inXmodem` is `z80XmSess`: Z80 TDR `SOH`/`STX` until idle `EOT`/`ETB`/`CAN` (includes the ACK gap). Trailer count is 1 (checksum) or 2 (CRC-16 / `STX`). Do not sniff CRC-lo as a new frame. Host `'C'` / `NAK` while not in a host session set CRC vs checksum for the next Z80→host send. `hostXmodem` is `hostXm <> OFF`: packet machine. `EOT`/`ETB`/`CAN` end the session only in the gap, not in payload. Skip `kbdToZ80` if either is true. Ctrl-A (`$01`) still starts a host session. Panic or `$03` clears both.

Arrow, Home, Left, and Right need three FIFO slots (`acia.txSpace >= 3`) before `kbd.getKey`. Other keys need one slot (`acia.txCheck`).

If FTDI TX cannot take the next byte, `readZ80` calls `acia.tdreHold`. `term.rxCount` is a count only. There is no XON/XOFF. FTDI RX PASM drops inbound bytes when that FIFO is full. The header does not wire CTS or RTS.

CTRL+ALT+DEL and boot `pulseZ80Reset`: hold P5 1 ms, discard FTDI RX and PS/2, `acia.start` (new cog: FIFOs and `last_rdr` zero), `tdreHold`, `PARSE_IDLE`, clear `z80XmSess` and `hostXm`, then release P5. Panic also VGA `CS` and FTDI clear if `txSpace => 4`. Backplane `/RESET` does not reset the Propeller. Sample P5 when not driving (D1 pulls P5 high while idle). After 1 ms low, wipe once and skip pumps until P5 is high. Do not drive P5 in reply. Do not wait on `req_master` while P5 is held. Z80 `CR_RESET` sets `req_parse_idle` **then** zeros FIFOs. Keep `tdre_hold`. Spin `tx`/`rx` abort while that flag is set. Do not hold `/RESET` across DDC.

ASCII and XMODEM `CON` names are lookup tables. Do not delete unused names.

Boot banner `"UX Module Initialised"` goes to FTDI and VGA.

## ACIA emulation (agent-critical)

**Tree now:** ACIA PASM is `569cd07` wait (`waitpne` then `waitpeq wr`). Mailbox is 11 longs. Rise wait is `wait_pin_high`. `sync_irq` composes `acia_status` on a status read (after `/WAIT`). `last_rdr` is cog RAM (empty or `/RTS` high rewinds `tx_tail`). Spin pulses `DIRA[25]` when RIE/TIE; it does not RMW `acia_status`. Dropping that pulse drops host keys. Punch list: [references/remaining-errors.md](references/remaining-errors.md).

- One PASM cog watches the decoded I/O address with `WAITPNE` / `WAITPEQ`.
- Match uses `waitpeq … wr` so `/WAIT` asserts via **destination += mask**. Do not drop `wr`. Loop contract: `lang-pasm/references/acia-wait.md`.
- Handler releases `/WAIT` with `or outa, bus_wait` after it places data or captures a write. `/RD` `/WR` rise uses `wait_pin_high` (poll pin and `req_master`). Do not put Hub ops on the match path to `waitpeq … wr`.
- Hub block at `PAR` (11 longs): `rx_head`, `rx_tail`, `tx_head`, `tx_tail`, `acia_base`, `acia_config`, `acia_status`, `buffer_ptr`, `tdre_hold`, `req_master`, `req_parse_idle`, then rx/tx byte FIFOs.
- Perspective: Z80 “receive” is Propeller `tx_*` (host→Z80); Z80 “transmit” is Propeller `rx_*`.
- PASM `sync_irq` is the live writer of `acia_status` (status read, after `/WAIT`). `sync_irq` derives `RDRF` from the TX FIFO and `/RTS`, and `TDRE` from RX room and `tdre_hold`.
- Spin `tx` / `rx` move FIFO indexes only. They abort on `req_parse_idle` / `req_master`. `rxCount` / `rxCheck` / `txCheck` / `txSpace` / `rxPeek` are counts or peeks only. Spin does not RMW `acia_status`.
- `tdreHold` / `tdreAllow` write Hub `tdre_hold` (0/1). They do not write `acia_status`.
- `/RTS` high (`CR_TID_RTS1`): hide `RDRF`, keep FIFO bytes, present `last_rdr`. `/RTS` low: set `RDRF` if the TX FIFO holds data.
- Empty or `/RTS`-high RDR: present `last_rdr`, do not move `tx_tail`. Full TDR: drop the write, do not set `OVRN` (that bit is a receiver error).
- CR5/CR6 is a two-bit field. TIE is the exact value `CR_TIE_RTS0`, not bit 5 alone. Master reset `$03` zeros both FIFOs and sets `req_parse_idle`. It does not clear `tdre_hold`.
- `/INT` level from `sync_irq` on a status read. Spin still pulses `DIRA[25]` when RIE/TIE so the 8085 sees a key while PASM is in `waitpeq`. Do not drop that pulse.

Edit with `lang-pasm` + `hw-ux-pcb`. Datasheet: `docs/MC6850.pdf`. OBEX idioms: `lang-pasm/references/obex-pasm.md`. Host drivers (RomWBW, CPM-IDE 8085) vs this tree: [references/acia-host-drivers.md](references/acia-host-drivers.md).

## Flow and reset decisions (revert notes)

These replace earlier WIP (`ea4502e` XON/XOFF, `569cd07` flow). Change the named rule, then the listed files. Do not restore Spin writes to `acia_status` without a new single-writer design.

| Decision | Current rule | Why | Revert |
|---|---|-----|---|
| Status owner | PASM `sync_irq` is the only writer of `acia_status`. | Spin and PASM RMW lost `RDRF` / `tdreHold` (starve then burst). | Do not give Spin `acia_status` again unless PASM stops writing it. |
| `TDRE` hold | Hub `tdre_hold`. `tdreHold` / `tdreAllow` write that long only. | PASM `receive_data` and Spin `rx` used to set `TDRE` and undo the hold. | Restore only if PASM and `acia.rx` both honour a sticky hold. |
| `OVRN` | Receiver bit only. Full TDR write is dropped. Do not set `OVRN`. | Datasheet `OVRN` is unread RDR, not a TDR overwrite. ROMs that saw `OVRN` read RDR or issued `$03`. | Setting `OVRN` on TDR full is the old leak. Do not restore it. |
| Pump cap | `PUMP_LIMIT` (16) bytes per role per main-loop pass. | Unbounded `termToZ80` delayed `tdreHold`. | Raise or remove the cap if a path needs more than 16 bytes per pass at 115200. |
| FTDI emit | `readZ80` peeks, uses `ftdiNeed`, then `acia.rx`. Idle BS/DEL need 3 TX slots if column > 0, else 0. | `term.tx` blocks. One free slot plus backspace stalled Cog 0. | Blocking `term.tx` from the parser is the old stall. |
| Empty / `/RTS` RDR | Present `last_rdr`. Do not move `tx_tail`. | Datasheet keeps the last byte. `/RTS` high must not consume queued keys. | Presenting `0` and advancing the tail was the empty-FIFO junk path. |
| CTRL+ALT+DEL / boot pulse | Hold P5 1 ms, discard host RX, `acia.start` (FIFOs and `last_rdr` zero), `tdreHold`, parser idle. Panic also VGA `CS` and gated FTDI clear. Then release P5. | Leftover RDR and FTDI RX hang 8085 boot. Do not wait on `req_master`. | 1 ms pulse with no FIFO wipe. |
| Z80 `CR_RESET` | Set `req_parse_idle` first. Zero FIFOs and `last_rdr`. **Keep `tdre_hold`.** | Parser is not a 6850 object. `$03` must not mean “FTDI has room.” Flag-first stops Spin tearing indexes. | Clearing `tdre_hold` on `$03`, or zeroing indexes before the flag. |
| `req_master` sample | Idle poll, `sync_irq`, and `wait_pin_high`. | `waitpeq /RD /WR` ignored `req_master` and deadlocked Cog 0. | Sample only in `sync_irq`. |
| XON/XOFF | Removed. No `term.rxFlow`. FTDI RX drops when full. | Binary XMODEM can contain `0x11`/`0x13`. Host cannot be paused on this header. | Restore `rxFlow` from `ea4502e` only for interactive paste. Wrap-over of FTDI RX. |
| Keyboard vs XMODEM | Skip `kbdToZ80` when `z80XmSess` or `hostXm <> OFF`. | Host payload `EOT` used to unmute the keyboard. Packet gap used to inject keys. | Latch on any UART `EOT`. Gate only `PARSE_XMODEM_*`. |
| Host CR | Z80 CR → `term.newLine` (CR+LF). `ftdiNeed` 2. | PST and typical hosts need CR. | `term.lineFeed` only. |
| Board reset button | Sample P5 when not driving. D1 pulls P5 high while `/RESET` is idle. 1 ms low = backplane pulse. Wipe ACIA once. Do not drive P5. Skip pumps while held. | Button does not reset the Propeller. Leftover RDR hangs 8085 boot. | Idle poll with no debounce, or drive P5 in reply. |

Hub writers and open IDs: [references/remaining-errors.md](references/remaining-errors.md). P0-3: backplane `/RESET` is sampled on P5 with a 1 ms debounce. P0-2 Spin must not wait on `req_master` while P5 is held. P2-2: keep the Spin INT pulse (`not (config & mask)` on the trailing `tx` pulse). Do not idle `sync_irq`. Review checklist: [references/ship-review.md](references/ship-review.md). Host ACIA clients: [references/acia-host-drivers.md](references/acia-host-drivers.md).

## VGA text path

- `wmf.init(VGA_BASE_PIN, @gTextCursX)` allocates screen/colour/cursor buffers and starts `hires_text_vga`. Overlay `gTextCursX/Y` copies WMF after text ops (`syncCurs`). Idle BS-space-BS runs only if column > 0. Do not guess a prompt width.
- Default timing block in `hires_text_vga.spin` is selected by which CON section is uncommented; pixel rate `pr` is tuned for ~118 MHz.
- Active table: 640×480 at about 70 Hz (80×40). EDID is reported only. DDC/CI does not set resolution.
- Screen bytes: bit7 = inverse; bits6..0 = glyph. Row colours are words `%%RRGGBB` style.
- `textOut` always writes WMF. Product build does not switch to VECTORJET.

## Build / upload

Copy from [`tools/README.md`](../../../tools/README.md).

```sh
openspin -L src -b -o build/ux_module.binary src/ux_module.spin
tools/ux-load.sh
tools/ux-screen.sh
```

1. PropellerIDE (or compatible) with **`ux_module.spin` in the foreground**. Product objects live under `src/`. Add `src/lib_vjet` only when you compile a VECTORJET demo.
2. Program with an **FT232** Prop Plug (`tools/ux-load.sh` or `proploader` on `/dev/cu.usbserial-*`, DTR reset). SparkFun FTDI Basic: DTR is pin 6 from GND (GRN). See `tool-propeller`. USB CDC (`/dev/cu.usbmodem*`, 8086net 5 V stick) is console only. Download on CDC was tried and failed (ROM handshake).
3. Toggle DTR on the FT232 to reboot stand-alone. CDC pin 1 is RTS, not DTR. CP/M on the USB-C CDC stick uses `rc-screen` (`tool-rc-screen`), not the FTDI relay.

## Agent rules

1. Do not start lib_vjet VGA from `ux_module.spin`. `hires_text_vga` owns P16–P23 for the product build. When graphics work resumes, stop text VGA and the I2C DDC cog before `VJET_vUXM_vga.start` (`library-vjet`).
2. Keep ACIA base selection in one place (`PORT_DEFAULT` / `PORT_ROMWBW` in `ux_module.spin`).
3. Preserve non-blocking main loop behaviour; long work belongs in other cogs.
4. New shared Hub structures need a stated single writer. Only Cog 0 calls `acia.tx`. `req_master` is Spin→PASM. `req_parse_idle` is PASM→Spin.
5. Do not add XON/XOFF on the FTDI path.
6. Prose: `style-ste-writing`.

## Related

- Pins: `hw-ux-pcb`
- Spin/PASM: `lang-spin`, `lang-pasm`
- 3D library: `library-vjet`

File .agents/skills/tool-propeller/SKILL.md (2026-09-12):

---
name: tool-propeller
description: >
  Propeller 1 toolchains for this repo: build and use OpenSpin (compile) and
  PropLoader/proploader (FTDI FT232 upload) for P8X32A Spin+PASM. Use when
  installing tools, compiling, flashing, or choosing a loader. Propeller 2
  tools are out of scope. Slash: /tool-propeller
---

# Tool — Propeller 1 compile / upload

CLI path for agents and scripts. Humans may still use PropellerIDE (see `README.md`).

## Installed layout (this machine)

| Binary | Source tree | Build output | Symlink |
|---|---|---|---|
| `openspin` | `~/Projects/OpenSpin` | `~/Projects/OpenSpin/build/openspin` | `~/bin/openspin` |
| `proploader` | `~/Projects/PropLoader` | `~/Projects/proploader-macosx-build/bin/proploader` | `~/bin/proploader` |

`PATH` must include `$HOME/bin` (set in `~/.zshrc`).

## Build OpenSpin from source

Needs `git`, `make`, and a C++ compiler (`g++` / Apple clang).

```bash
git clone --recursive https://github.com/parallaxinc/OpenSpin.git ~/Projects/OpenSpin
cd ~/Projects/OpenSpin
make
mkdir -p ~/bin
ln -sfn ~/Projects/OpenSpin/build/openspin ~/bin/openspin
openspin -h
```

Rebuild after pulls:

```bash
cd ~/Projects/OpenSpin && make
```

`openspin` with no args prints usage. Version banner looks like `OpenSpin` / `1.00.81`.

## Build PropLoader (`proploader`) from source

PropLoader calls `openspin` during its own build (Spin helpers). Put `openspin` on `PATH` first.

```bash
export PATH="$HOME/bin:$PATH"
git clone --recursive https://github.com/parallaxinc/PropLoader.git ~/Projects/PropLoader
cd ~/Projects/PropLoader
OS=macosx make
ln -sfn ~/Projects/proploader-macosx-build/bin/proploader ~/bin/proploader
proploader -?
```

| Host | `make` |
|---|---|
| macOS | `OS=macosx make` |
| Linux | `OS=linux make` |
| Raspberry Pi | `OS=raspberrypi make` |
| Windows (MinGW cross from Linux) | `make CROSS=win32` |

Output directory is `~/Projects/proploader-<os>-build/bin/proploader` (sibling of the `PropLoader` repo). The Makefile `install` target copies into `~/bin`.

Rebuild:

```bash
export PATH="$HOME/bin:$PATH"
cd ~/Projects/PropLoader && OS=macosx make
```

## Why `proploader` (not `propeller-load` / Propeller Tool)

The UX Module programmes over an **FTDI FT232** USB-UART on P30/P31 with **DTR** reset — the same serial Propeller protocol as a Prop Plug. No FTDI D2XX API is required. macOS exposes `/dev/cu.usbserial-*` via Apple’s built-in FTDI driver.

| Tool | Verdict for FT232 |
|---|---|
| **`proploader`** ([parallaxinc/PropLoader](https://github.com/parallaxinc/PropLoader)) | **Use this.** Serial + DTR/RTS reset; `-P` lists ports; RAM/EEPROM; optional terminal. |
| `propeller-load` (PropGCC) | Also serial/FTDI-capable, but heavier PropGCC/board-cfg dependency. |
| Propeller Tool / Propellent | Windows GUI / Windows CLI — not the macOS agent path. |

## Compile this repo

Copy from [`tools/README.md`](../../../tools/README.md). Top object must be the file on the `openspin` command line (same rule as PropellerIDE foreground).

```bash
mkdir -p build
openspin -L src -b -o build/ux_module.binary src/ux_module.spin
```

Product search path is `-L src` only. EEPROM-sized image file (still load with `proploader -e` or `tools/ux-load.sh`):

```bash
openspin -L src -e -o build/ux_module.eeprom src/ux_module.spin
```

Useful flags: `-L`/`-I` object search path, `-b` binary, `-e` eeprom file, `-v` verbose, `-u` unused-method elimination.

lib_vjet demos use their own top objects, for example:

```bash
openspin -L src -L src/lib_vjet -b -o build/vjet_test.binary src/lib_vjet/vjet_test.spin
```

## Load (FT232 Prop Plug only)

The ROM bootloader clocks bits with `0xF9`. That needs a low-latency USB-UART (**FTDI FT232 / FT231**, SparkFun FTDI Basic, Parallax Prop Plug). Default reset is **DTR**.

SparkFun FTDI Basic uses the FTDI TTL-232R 6-pin SIL, with **pin 6 swapped from RTS# to DTR#** so Arduino-style `/RES` works ([hookup guide](https://learn.sparkfun.com/tutorials/sparkfun-usb-to-serial-uart-boards-hookup-guide)). Align GRN (pin 6) to GRN, BLK (pin 1) to BLK.

| Pin | SparkFun Basic | Colour | UX Module |
|-----|---|---|---|
| 1 | GND | BLACK | GND (BLK) |
| 2 | CTS# | BROWN | NC |
| 3 | VCC | RED | VCC |
| 4 | TXO | ORANGE | P31 RX |
| 5 | RXI | YELLOW | P30 TX |
| 6 | **DTR#** (active low) | GREEN | `!DTR` → `/RES` (GRN) |

A genuine FTDI TTL-232R cable still has **RTS# on pin 6**; that needs `-D reset=rts`, not DTR.

```bash
tools/ux-load.sh                       # EEPROM + run, DTR, cu.usbserial-*
tools/ux-load.sh /dev/cu.usbserial-XXXX
proploader -P                          # list serial ports
# FT232 is cu.usbserial-*, not cu.usbmodem-*
proploader -p /dev/cu.usbserial-XXXX -r build/ux_module.binary
proploader -p /dev/cu.usbserial-XXXX -e -r build/ux_module.binary   # EEPROM + run
proploader -p /dev/cu.usbserial-XXXX -R                            # reset only
proploader -p /dev/cu.usbserial-XXXX -r -t build/ux_module.binary  # run + terminal
```

If auto-detect finds the wrong port, pass `-p`. Prefer `/dev/cu.*` over `/dev/tty.*` on macOS. Ignore `/dev/cu.debug-console`.

Board clock comes from the **Spin source** (`_xinfreq = 7_372_800`). Loader `-b` / `-D clkfreq=…` only affect loader-side helpers.

Quit GNU `screen` before a load (`C-a k`, or `screen -X -S <name> quit`). The port must be free.

## Do not load over USB CDC

macOS **CDC ACM** sticks show as `/dev/cu.usbmodem*`. PropLoader **lists** them. They are **not** a Prop Plug.

Tried and failed on this board (2026-09-10), 8086 Consultancy USB-C to UART Adaptor (5 V), nodes `cu.usbmodem03291` and `cu.usbmodem01031`:

| Attempt | Result |
|---|---|
| Default DTR reset | `Propeller not found` |
| `-D reset=rts` | `Propeller not found` |
| `-D reset=rts-inv` (local PropLoader) | `Propeller not found` |
| Manual GRN–BLK (`-D reset=none`) | `Propeller not found` |

Cause: header pin 1 on that stick is **RTS**, not DTR. Software RTS did not reach `/RES` until a jumper exists. Even with a hand pulse, CDC ACM latency breaks the ROM `0xF9` handshake. Console at 115200 can still work. Do not use CDC to download.

This machine’s PropLoader (`~/Projects/PropLoader`) default is **DTR** (SparkFun FTDI Basic pin 6 DTR#). Extra methods: `-D reset=rts` (stock FTDI cable pin 6), `-D reset=rts-inv`, `-D reset=none` (prints `Release /RES now`).

## Console helpers (this repository)

Scripts live in `tools/`. Humans and agents copy from [`tools/README.md`](../../../tools/README.md).

| Command | Role |
|---|---|
| `tools/ux-screen.sh` | GNU `screen` 115200 8N1 on SparkFun FTDI. `tools/ux-ftdi-relay.py` holds DTR off (that pin is `/RES`). Session `uxmod`. Config: `tools/screenrc-ux`. |
| `rc-screen` | GNU `screen` 115200 8N1 on USB CDC (`/dev/cu.usbmodem*`). Direct attach. No relay. Session `rc2014`. `$HOME/bin/rc-screen`. See `tool-rc-screen`. |
| `tools/serial_probe.py` | Headless TX/RX log on FTDI. Holds DTR off. Prints `BOOT`/`TX`/`RX` as `repr` plus `<CR>`/`<LF>`. Quit screen first. Not the CDC path. |
| `tools/ux-load.sh` | EEPROM load on SparkFun FTDI Basic. Default `reset=dtr` on `/dev/cu.usbserial-*`. `-m` is manual `/RES`. Refuses `/dev/cu.usbmodem*`. |
| `tools/screenrc-ux` | FTDI session: `flow off`; `C-a s` / `C-a r` prefill `lsx` / `lrx`. |

```bash
tools/ux-screen.sh                         # FT232 console (relay, DTR off)
tools/ux-screen.sh /dev/cu.usbserial-XXXX
rc-screen                                  # RC2014 ACIA on USB CDC (direct)
tools/serial_probe.py                      # FTDI banner only (quit screen first)
tools/serial_probe.py $'ABC123\r'
```

## Optional / out of scope

| Tool | Notes |
|---|---|
| PropellerIDE | Default for human interactive work (`README.md`) |
| flexspin | Optional; use `-1` or `-1bc` only — never P2 default |
| `loadp2`, PNut P2 | Propeller 2 — wrong chip |

## Agent rules

1. If `openspin` or `proploader` is missing, build them with the steps above before inventing another toolchain.
2. Compile the **top** object named by the user (`ux_module.spin` or a `lib_vjet` demo).
3. Prefer `openspin` + `proploader` for this repo.
4. EEPROM on the board is 32 KB or 64 KB; bootloader loads **32 KB** into Hub RAM.
5. Do not install vendor FTDI VCP kexts on modern macOS — use Apple’s built-in FTDI driver.
6. Propeller 1 only. Do not install or default to P2 loaders.
7. Do not use `/dev/cu.usbmodem*` (CDC) to download. Load only on FT232 `/dev/cu.usbserial-*` with DTR reset. CDC is console-only.

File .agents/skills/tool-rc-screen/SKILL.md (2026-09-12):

---
name: tool-rc-screen
description: >
  RC2014 ACIA console on USB CDC via GNU screen. Direct attach, no FTDI
  relay, no serial_probe. XMODEM send/receive with lsx/lrx. Use when
  talking to CP/M on the 8085, stuffing keys, hardcopy, or loading a
  .COM over the 8086net USB-C stick. Slash: /tool-rc-screen
---

# Tool — RC2014 CDC console

Session name **`rc2014`**. Device is **`/dev/cu.usbmodem*`** (USB CDC ACM). Screen opens that node. There is no PTY and no `ux-ftdi-relay`.

SparkFun FTDI **`/dev/cu.usbserial-*`** is Propeller `/RES` on DTR. That path is `ux-screen` (`tool-propeller`). Do not point `rc-screen` at it.

General command: `$HOME/bin/rc-screen` (on `PATH`). Config: `$HOME/.screenrc-rc`. In-tree copies: `tools/rc-screen.sh`, `tools/screenrc-rc`.

## Start / attach

```sh
rc-screen                              # CDC if one node; reattach if live
rc-screen /dev/cu.usbmodem01031
rc-screen --list
rc-screen --quit
```

Sockets live in `$HOME/.screen-rc2014` (`SCREENDIR`). Do not call `screen -S rc2014` from a random shell. Apple `screen` then looks in `$TMPDIR/.screen` and reports no session. Use `rc-screen --quit`, `rc-screen --stuff`, and `rc-screen --hardcopy`.

A TTY attaches. No TTY starts the session detached (`screen -d -m`). One session only. Do not start a second `screen` on the same CDC node.

If `ux-ftdi-relay` holds that node, run `ux-screen --quit` then `ux-screen --stop` first.

Env: `RC_SCREEN_DEV`, `RC_SCREEN_BAUD` (default 115200). `RC_SCREEN_RC` overrides the screenrc path. `RC_SCREEN_DIR` overrides `SCREENDIR`.

Binary: Apple `/usr/bin/screen`.

## Keys (human)

| Key | Action |
|-----|---|
| `C-a d` | Detach (session stays on the port) |
| `C-a k` | Quit |
| `C-a s` | XMODEM send (`lsx -b -q -X`). Type the host path. |
| `C-a r` | XMODEM receive (`lrx -b -q -X`) |

Start `screen` with `115200,cs8,-ixon,-ixoff`. Apple `screen` with no baud flag resets the node to 9600. CDC DTR is not Propeller `/RES`.

## Agent I/O

The session stays up. Drive it with `rc-screen --stuff` and `rc-screen --hardcopy`. Do not wrap it in a Grok monitor. Do not call `screen -S` unless `SCREENDIR=$HOME/.screen-rc2014`.

```sh
rc-screen --stuff $'dir\r'
rc-screen --hardcopy /tmp/rc2014.hardcopy
```

## XMODEM (host → CP/M A:)

Same flags as `ux-screen`: `lsx -b -q -X`. Quiet is required. Progress on the serial line aborts CP/M after block 1.

On CP/M (8.3 name):

```
xmodem NAME.COM /r /q
```

Then on the host:

```sh
rc-screen --send /abs/path/to/file.com
rc-screen --send --1k /abs/path/to/file.com
```

`--send` waits one second (`--delay-startup 1`) so CP/M is in receive first. Overwrite prompt on CP/M is `Y`.

Host → 8085 receive:

```
xmodem NAME.COM /s /q
```

then `rc-screen --recv /abs/path/to/out`.

`lrzsz` (`lsx`/`lrx`) must be on `PATH` (Homebrew).

## Do not

1. Do not start `ux-screen` on the same CDC node while `rc2014` is live.
2. Do not use `tools/serial_probe.py` or `tools/ux-ftdi-relay.py` on this path.
3. Do not open `/dev/cu.usbmodem*` with `proploader` / `ux-load`. CDC is console only.
4. Do not start a second GNU `screen` named `rc2014`.
5. Do not watch the session with a byte-growth monitor. Use `hardcopy` or `--list`.

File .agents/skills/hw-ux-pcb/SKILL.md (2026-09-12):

---
name: hw-ux-pcb
description: >
  RC2014 UX Module board pin map and bus glue: Propeller P0–P31 assignments
  for ACIA address/data, /WAIT, /INT, VGA, PS/2, FTDI, I2C EEPROM, and the
  74HC4078 decode. Use when changing pin constants, ACIA masks, or relating
  firmware to pcb/ schematics. Sources: src/acia_rc2014.spin, README, pcb/.
---

# Hardware — UX Module PCB

Board: RC2014 User Experience Module (Propeller P8X32A). Schematics and gerbers: `pcb/`. Product overview: `README.md`.

## Clock and power

| Item | Value |
|---|---|
| Oscillator | 7.3728 MHz (RC2014 bus clock family) |
| Propeller clock | ×16 PLL ≈ 118 MHz |
| Logic | 3.3 V Propeller; RC2014 bus via board level shifting / open-collector where noted |
| Firmware store | I2C EEPROM 24LC256 or 24LC512 |

## Pin map (production firmware)

| Pins | Function |
|---|---|
| P0 | A7 |
| P1 | A6 |
| P2 (pin 2 — not “Propeller 2”) | `!(/IORQ \| A5 \| A4 \| A3 \| A2 \| A1)` from 74HC4078 NOR (active high when I/O hit in the decoded page) |
| P3 | A0 |
| P4 | /M1 |
| P5 | `PRESET`: drive RC2014 `!RESET` via D1. C12 200 pF to `!RESET`. Not Propeller `/RES`. |
| P6 | /WR |
| P7 | /RD |
| P8–P15 | D0–D7 data bus |
| P16–P23 | VGA (VGroup 2): VSync, HSync, B1 B0, G1 G0, R1 R0 |
| P24 | /WAIT (open-collector via diode) |
| P25 | /INT (open-collector via diode) |
| P26 | PS/2 clock |
| P27 | PS/2 data |
| P28 | I2C **SDA** for Spin DDC (`ddc_i2c.spin`). Bootloader SCL. VGA pin 12 (VESA SDA). |
| P29 | I2C **SCL** for Spin DDC. Bootloader SDA. VGA pin 15 (VESA SCL). |
| P30 | FTDI TX (Propeller → host). SparkFun FTDI Basic pin 5 RXI (YELLOW) |
| P31 | FTDI RX (host → Propeller). SparkFun FTDI Basic pin 4 TXO (ORANGE) |

Constants: `src/ux_module.spin`, `src/acia_rc2014.spin`, `src/ddc_i2c.spin`.

## ACIA I/O decode

The 74HC4078 compresses `/IORQ` and A5…A1 into one Propeller pin. Firmware treats a match on that pin plus A7/A6/A0 (and /M1 high for I/O) as chip select for the emulated MC6850.

Selectable bases in `acia_rc2014.spin`:

| Name | Typical use |
|---|---|
| `PORT_80` | Default RC2014 ACIA |
| `PORT_40` | RomWBW when SIO owns 0x80 |
| `PORT_C0` | Reserved / VJET experiments (`PORT_VJET` in top object) |

Register map (6850-compatible):

| Offset | /RD | /WR |
|---|-----|-----|
| base+0 | Status | Control |
| base+1 | Receive data | Transmit data |

Status/control bit names mirror `docs/MC6850.pdf` (`SR_RDRF`, `SR_TDRE`, `CR_RIE`, …).

## Bus timing notes

- Propeller asserts `/WAIT` on address match so the Z80 stretches the I/O cycle until PASM finishes. Match uses `waitpeq … wr` (dest+mask). Rules: `lang-pasm/references/acia-wait.md`.
- `/INT` is open-collector on P25 (`OUTA` bit 25 stays 0). PASM `sync_irq` holds `DIRA` P25 on a status read. Spin also pulses `DIRA[25]` when RIE or TIE, so a key is seen while PASM is in `waitpeq`. Each cog has its own `DIRA`. The pin is the OR of driven lows.
- CTRL+ALT+DEL and boot pulse: `outa[5]~`, `dira[5]~~`, hold 1 ms, wipe ACIA (restart cog), then `dira[5]~`. Net `PRESET` is P5, D1 cathode, and C12 (200 pF). `!RESET` is the RC2014 bus (D1 anode, C12 other end). C12 does not stretch the pulse. When `/RESET` is idle, D1 pulls P5 high. A backplane button pulse makes P5 low. Sample P5 only when Spin is not driving it. Debounce 1 ms. Wipe FIFOs once. Do not drive P5 in reply.
- Data bus bytes in Hub are often stored **pre-shifted** by `DATA_BASE` (8) so they OR straight onto `OUTA`.

## VGA analogue network

Eight pins through resistor DAC (270 Ω / 560 Ω / 130 Ω) as documented in `hires_text_vga.spin` / `VJET_vUXM_vga.spin` headers. Do not reassign VGA away from an 8-pin group boundary (0/8/16/24).

## Agent rules

1. Change pin numbers in **one** owning module, then import via `object#CONST`.
2. Any ACIA mask change must update `port_active_mask`, `DATA_BASE`, and schematic comments together.
3. Do not put extra I2C devices on P28/P29 that answer during Propeller boot. VGA DDC SDA/SCL are swapped so a monitor EDID chip does not ACK the bootloader. After boot, `i2c.startCog` in `ddc_i2c.spin` uses the swapped pair to read EDID at 0x50 and DDC/CI at 0x37. Do not talk to the 24LC256 with that pin pair.
4. DTR on the FTDI connector resets the Propeller (same idea as Arduino). Tools: `tools/serial_dtr.py`, `tools/serial_tool.py`. Load the chip with an **FT232** Prop Plug (`tool-propeller`). USB CDC is not a loader.
5. SparkFun FTDI Basic 6-pin matches the FTDI TTL-232R SIL except **pin 6 is DTR#**, not RTS# ([hookup guide](https://learn.sparkfun.com/tutorials/sparkfun-usb-to-serial-uart-boards-hookup-guide)). Align GRN to GRN, BLK to BLK. CTS is NC. RTS is not on this header. Load with `proploader` DTR (`tools/ux-load.sh`). No RTS/CTS or DTR flow to the Propeller. Software flow: `module-ux` revert notes.

| Pin | SparkFun / Arduino | FTDI TTL-232R cable | Colour | UX Module |
|-----|---|---|---|---|
| 1 | GND | GND | BLACK | GND (BLK) |
| 2 | CTS# | CTS# | BROWN | NC |
| 3 | VCC | VCC | RED | VCC |
| 4 | TXO | TXD | ORANGE | P31 RX |
| 5 | RXI | RXD | YELLOW | P30 TX |
| 6 | **DTR#** | RTS# | GREEN | `!DTR` → `/RES` (GRN) |
6. 8086 Consultancy USB-C CDC adaptor (5 V, [Tindie](https://www.tindie.com/products/8086net/uusbusb-c-cdc-serial-adaptor-5v/)) is RTS, RX, TX, 5V, CTS, GND. Pin 1 is RTS, not DTR. macOS node `/dev/cu.usbmodem*`. Fine for 115200 console (`ux-screen`). Do not use it as a Prop Plug. An FT232 enumerates as `/dev/cu.usbserial-*`.

## Related

- Chip behaviour: `hw-propeller`
- Firmware topology: `module-ux`
- 6850 register behaviour in PASM: `module-ux` + `src/acia_rc2014.spin`
- `/WAIT` loop: `lang-pasm/references/acia-wait.md`

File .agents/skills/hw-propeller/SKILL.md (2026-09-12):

---
name: hw-propeller
description: >
  Parallax Propeller 1 (P8X32A) hardware only: eight cogs, Hub, I/O Port A,
  locks, counters, Video Generator (VCFG/VSCL/WAITVID), clock, EEPROM boot.
  Use for Spin/PASM timing, pins, video, multi-cog design. Never Propeller 2.
  Sources: docs/, pcb/ datasheet, OBEX Propeller 1 tips.
---

# Hardware — Propeller 1 (P8X32A)

**This repository targets Propeller 1 only.** Propeller 2 (P2X8C4M64P and related) is a different chip: smart pins, hub RAM map, Streamer, CORDIC, PASM2, Spin2. Do not apply P2 facts here.

Naming trap: **`P2` in board docs often means I/O pin 2**, not Propeller 2. Prefer “pin P2” vs “Propeller 2” in prose.

Authority order when facts disagree:

1. Tree sources under `src/` (what this board runs)
2. `pcb/P8X32A-Propeller-Datasheet-v1.4.0_0.pdf`
3. `docs/P8X32A-Web-PropellerManual-v1.2.pdf`
4. `docs/Propeller Quick Reference v1.7.pdf`
5. OBEX **Propeller 1** tips — https://obex.parallax.com/code-language/pasm (skip P2-tagged objects)
6. Doc index: `.agents/skills/lang-pasm/references/p1-sources.md`

## Chip model (must keep straight)

| Item | Fact |
|---|---|
| Cogs | 8 identical 32-bit processors, IDs 0–7 |
| Cog RAM | 512 longs; last 16 are special-purpose registers |
| Main RAM | 32 KB shared Hub RAM + 32 KB Hub ROM |
| Hub access | Round-robin; one cog every 16 system clocks |
| Hub instruction cost | 8–23 clocks (sync to access window + 8) |
| I/O | 32 pins; after boot all general-purpose |
| Boot pins | P28 SCL, P29 SDA (EEPROM); P30 TX, P31 RX (host) |
| Spec clock | 80 MHz typical; UX Module runs ~118 MHz (see `module-ux`) |
| Languages | Spin (interpreted) + Propeller Assembly (PASM) |

No interrupts on the Propeller. Event work uses dedicated cogs plus `WAITCNT` / `WAITPEQ` / `WAITPNE` / `WAITVID`.

## Shared resources

**Common (any cog, any time):** I/O pin sense, System Counter (`CNT`).

**Mutually exclusive (Hub):** Hub RAM/ROM, locks, cog start/stop, clock set.

I/O pin final state:

- Direction = OR of all cog direction registers
- Output high if any active cog that drives the pin sets it high
- A stopped cog clears its influence

## Counters and video

Each cog has CTRA/CTRB (FRQ/PHS) and one Video Generator.

Video path (VGA mode used by this board):

1. Start CTRA in a PLL mode (video needs PLLA)
2. Set `VSCL` (PixelClocks / FrameClocks)
3. Set `VCFG` (VMode=VGA, CMode, VGroup, VPins)
4. Feed pixels with `WAITVID Colors, Pixels`

If PLLA is not running, `WAITVID` hangs the cog forever.

VGroup selects pin octets: 0→P0–7, 1→P8–15, 2→P16–23, 3→P24–31. UX VGA uses group 2 (base pin 16). See `hw-ux-pcb`.

## Clock

UX Module top object sets:

```
_clkmode = XTAL1 + PLL16X
_xinfreq = 7_372_800
```

System clock ≈ 7.3728 MHz × 16 ≈ 117.9648 MHz. Timing constants in drivers assume this. Changing the oscillator requires `_xinfreq` and VGA pixel-rate retune.

## Boot

1. Reset → Cog 0 runs bootloader
2. Host on P30/P31 may download to RAM / EEPROM
3. Else load 32 KB image from I2C EEPROM on P28/P29
4. Cog 0 runs Spin interpreter on the loaded image

UX EEPROM pins are **swapped vs the usual Propeller diagram** so only the EEPROM is visible at boot. See `hw-ux-pcb` and `src/ddc_i2c.spin`.

## Propeller 2 features that do not exist here

No smart pins, no `HUBSET` clock API as on P2, no hub exec / LUT exec, no Streamer, no CORDIC coprocessor, no Port B (`OUTB`/`DIRB`/`INB` as P2), no 64-bit system counter builtins from Spin2.

P1 video = per-cog Video Generator + `WAITVID` + CTRA PLL. That is the path UX and VECTORJET use.

## Agent rules

1. Count cogs before starting another (`cognew` returns −1 when none free).
2. Cross-cog data larger than one long needs locks or a single-writer protocol.
3. Interleave non-hub PASM with hub ops when Hub bandwidth matters.
4. After self-modifying PASM (`MOVI`/`MOVS`/`MOVD`), execute at least one other instruction before the patched line runs.
5. Conditional jumps are predicted taken; not-taken costs an extra 4 clocks.
6. If a source mentions Propeller 2, treat it as foreign unless the task is explicitly about excluding it.

## Related

- Spin: `lang-spin`
- PASM: `lang-pasm` (+ `references/p1-opcodes.md`)
- Tools: `tool-propeller`
- Board pin map: `hw-ux-pcb`
- Firmware topology: `module-ux`
- VECTORJET: `library-vjet`

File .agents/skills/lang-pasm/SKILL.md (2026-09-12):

---
name: lang-pasm
description: >
  Propeller 1 (P8X32A) Assembly (PASM) only: 9-bit immediates, WC/WZ/WR/NR,
  conditions, hub timing, MOVS/MOVD/MOVI, WAIT*, pin masks, JMPRET, FIT/ORG/RES.
  Use when writing or reviewing DAT assembly in src/*.spin. Never PASM2.
  Sources: docs/ quick ref + Manual; OBEX P1 tips; references/ under this skill.
---

# Language — Propeller 1 Assembly (PASM)

**Chip: P8X32A (Propeller 1) only.** Propeller 2 / PASM2 is a different ISA. Do not mix.

PASM runs from Cog RAM. Entry is usually `DAT` / `org` / label, started with `cognew(@Entry, parValue)`.

| Reference | Path |
|---|---|
| Opcode / condition / clocks card | [references/p1-opcodes.md](references/p1-opcodes.md) |
| Spin ↔ PASM mailbox | [references/spin-pasm-bridge.md](references/spin-pasm-bridge.md) |
| Doc index (in-tree + OBEX P1) | [references/p1-sources.md](references/p1-sources.md) |
| OBEX idioms | [references/obex-pasm.md](references/obex-pasm.md) |
| ACIA `/WAIT` loop | [references/acia-wait.md](references/acia-wait.md) |
| In-tree cheat sheet | `docs/Propeller Quick Reference v1.7.pdf` |

## Non-obvious rules (encode these)

1. **S-field immediates are 9-bit** (`#0`…`#511`). Bigger values → `long` in cog RAM, then `mov`.
2. Line shape: `Label  Condition  INST  D,S  Effects` (`IF_Z`, `WC`, `WZ`, `WR`, `NR`).
3. Almost all ops are **4 clocks**; hub and wait ops are longer (see opcode card).
4. **`RES` comes after initialized `long`s** in the cog image; then `FIT`.
5. **Local labels** start with `:`. `CALL`/`JMPRET`/`RET` use the 9-bit S field as the return slot (`label_ret`).
6. Spin and PASM **never nest-call**; they share Hub longs via `PAR` ([spin-pasm-bridge.md](references/spin-pasm-bridge.md)).
7. **P1 ≠ P2.** Reject `WAITX`, `DRVL`, `##imm`, `HUBSET`, smart pins, etc. ([p1-opcodes.md](references/p1-opcodes.md) forbidden list).

## Instruction shape

```
〈label〉  〈condition〉  instruction  dest, 〈#〉src  〈effects〉
```

| Effect | Meaning |
|---|---|
| `WC` | Write C |
| `WZ` | Write Z |
| `WR` | Write destination |
| `NR` | Do not write destination |

Default for most ALU ops is write destination without changing flags unless `WC`/`WZ` requested.

## Hub vs cog

| Class | Examples | Clocks |
|---|---|---|
| Cog ALU / branch | `MOV`, `ADD`, `DJNZ`, `JMP` | usually 4 (branch not-taken 8) |
| Hub memory | `RDBYTE` `RDWORD` `RDLONG` `WRBYTE` `WRWORD` `WRLONG` | 8–23 |
| Hub system | `COGINIT` `COGSTOP` `LOCK*` `CLKSET` | 8–23 |
| Wait | `WAITCNT` `WAITPEQ` `WAITPNE` `WAITVID` | 6+ until event |

Put two 4-clock cog instructions between hub ops when Hub bandwidth matters.

## Self-modifying code

`MOVS` / `MOVD` / `MOVI` patch source, dest, or opcode fields. The instruction **immediately after** a patch still fetches the old encoding — insert at least one other instruction before the patched line runs.

Placeholders: `0-0` (zero; often means “patched later”) or Spin-filled `long 0-0` before `cognew`.

## Special registers

| Reg | Use |
|-----|-----|
| `PAR` | Boot parameter (Hub address from `cognew`) |
| `CNT` | System counter |
| `INA` / `OUTA` / `DIRA` | Pin in / out / direction (**Port A only** on P1) |
| `CTRA`/`CTRB`, `FRQA`/`FRQB`, `PHSA`/`PHSB` | Counters / PLL |
| `VCFG`, `VSCL` | Video config / scale |

`PHSA`/`PHSB` are source-only for reads. RMW uses the last written value, not the live accumulator.

## Pin-mask idioms

| Goal | Pattern |
|---|---|
| Output + high | `or dira, mask` / `or outa, mask` |
| Output + low | `or dira, mask` / `andn outa, mask` |
| Toggle | `xor outa, mask` |
| Float (input) | `andn dira, mask` |
| Sample | `test mask, ina wc` or `wz` |
| Flag-conditioned bits | `muxc` / `muxnc` / `muxz` / `muxnz` |

## WAITCNT / WAITPEQ / WAITPNE

```
mov     timer, TICKS
add     timer, cnt
loop    waitcnt timer, TICKS
        djnz    count, #loop
```

```
waitpeq state, mask     ' until (INA & mask) == state
waitpne state, mask     ' until (INA & mask) != state
```

1. `state` bits outside `mask` → `WAITPEQ` hangs forever.
2. **`waitpeq dest, mask wr` writes `dest + mask`**, not `INA`. ACIA uses this to assert `/WAIT` (P24 1+1 → 0, carry into `/INT`).
3. ACIA loop contract: [references/acia-wait.md](references/acia-wait.md). Do not drop `wr`. Do not Hub-read on the match path.

## CALL / JMPRET

- `call #label` … `label_ret ret`
- `jmpret retReg, #other` — coroutine (`terminal_ftdi.spin`)

## Event loops in this tree

**ACIA:** `rdlong` match value into `OUTA`, `WAITPNE`, then `WAITPEQ … wr` match and `/WAIT`. No Hub between those waits. Then service RD/WR, `or outa, bus_wait`, `wait_pin_high` (samples `req_master`). `sync_irq` runs on a status read after `/WAIT`. See [acia-wait.md](references/acia-wait.md).  
**VGA:** `WAITVID` scanline loop.  
**FTDI:** `JMPRET` + bit timing.  
**DDC I2C (Spin):** `WAITPEQ(|<scl,|<scl,0)` in `ddc_i2c.spin`.

## Agent rules

1. Emit **P1 PASM only**. No PASM2.
2. Keep `FIT` headroom (496 longs before specials).
3. Document PAR Hub layout at `entry`.
4. Update pin masks and `waitpeq` masks together.
5. Never remove ACIA `waitpeq … wr` without another `/WAIT` design. Follow [acia-wait.md](references/acia-wait.md).
6. Prose: `style-ste-writing`.

## Related

- `hw-propeller` — chip model (P1)
- `lang-spin` — Spin side of the bridge
- `tool-propeller` — build/use OpenSpin + PropLoader
- `hw-ux-pcb` / `module-ux` — board + ACIA
- `library-vjet` — render/VGA PASM

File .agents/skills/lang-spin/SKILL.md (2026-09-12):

---
name: lang-spin
description: >
  Propeller 1 Spin only (P8X32A): CON/VAR/OBJ/PUB/PRI/DAT blocks, cognew of
  Spin vs PASM, Hub mailbox via PAR, VAR vs DAT, house style in src/*.spin.
  Use when writing or reviewing Spin. Not Spin2. Sources: docs/ Manual and
  Quick Reference; lang-pasm/references/spin-pasm-bridge.md.
---

# Language — Propeller 1 Spin

**Chip: P8X32A (Propeller 1) only.** Do not use Spin2 syntax (`HUBSET`, smart-pin builtins, `^@`, P2 debug, etc.).

Spin is bytecode interpreted in a cog. Hot paths are usually PASM in `DAT`; Spin wires objects and Hub memory.

Quick reference: `docs/Propeller Quick Reference v1.7.pdf`. Full language: `docs/P8X32A-Web-PropellerManual-v1.2.pdf`. Bridge to PASM: `.agents/skills/lang-pasm/references/spin-pasm-bridge.md`.

## File blocks (order agents must respect)

| Block | Role |
|---|---|
| `CON` | Compile-time constants and enumerations |
| `VAR` | Hub RAM variables (byte/word/long) |
| `OBJ` | Nested objects (`name : "file"`) |
| `PUB` | Public methods (API) |
| `PRI` | Private methods |
| `DAT` | Data tables and/or PASM |

A file may repeat `CON`/`VAR` sections. The **top object** of a PropellerIDE build is the foreground file at compile/upload time. For this product that is `src/ux_module.spin` (or a lib_vjet test top).

## Clock constants (top object only)

```
CON
  _clkmode = XTAL1 + PLL16X
  _xinfreq = 7_372_800
```

Only the top object’s `_clkmode` / `_xinfreq` (or `_clkfreq`) set the chip clock. Child objects must not redefine them unless they are themselves a top object (tests).

## Objects and hierarchy

```
parent
  child : "module_name"     ' loads module_name.spin
  child.method(args)
  child#CONSTANT            ' CON from child
```

UX Module hierarchy lives in `module-ux`. Do not flatten Parallax objects into the top file without a reason.

## Starting work on another cog

```
cognew(spinMethod(@args...), @stack)   ' Spin method + Hub stack
cognew(@pasmEntry, parameter)          ' PASM; PAR gets Hub mailbox address
cogstop(id)
```

`cognew` returns cog ID 0–7, or −1 on failure. House style often stores `cog := cognew(...) + 1` so 0 means “not running”.

Every Spin cog needs its own Hub stack long array sized for locals and call depth.

**Spin does not call PASM as a subroutine, and PASM does not call Spin `PUB`s.** Share Hub longs only (see `lang-pasm` bridge reference).

## Memory

| Form | Meaning |
|---|---|
| `byte[addr]`, `word[addr]`, `long[addr]` | Typed Hub access |
| `@symbol` | Hub address of symbol |
| `string("...")` | Address of zero-terminated string in Hub |
| `BYTEFILL` / `WORDMOVE` / … | Block fill/copy |

Spin and PASM share Hub RAM. Document who writes each shared long.

## VAR vs DAT (OBEX tip)

| | `VAR` | `DAT` (data) | `DAT` (PASM) |
|--|---|---|---|
| Where | Hub RAM | Hub RAM | Loaded into Cog RAM on `cognew(@entry,…)` (first 496 longs) |
| Per object instance | **Separate** copy | **One** shared copy | One image; each started cog gets its own Cog RAM copy |
| Init | Cleared to 0 | Can set `long`/`word`/`byte` values | Code + `long` constants; `res n` for cog scratch |
| Typical use | FIFOs, cog IDs, per-instance state | Shared tables, font blobs, single-driver constants | Driver entry points |

Rules of thumb (OBEX + this tree):

1. Prefer `VAR` for per-instance driver state (`rx_head`, `cog`, buffers).
2. Use shared `DAT` longs when every instance must see the same cell, or for PASM immediates filled from Spin (`long 0-0` then assign before `cognew`).
3. Passing `@var` in `PAR` is how PASM reaches Hub `VAR` blocks (ACIA, UART, VGA).
4. Object scope ≠ cog scope. Two Spin cogs from the same object share that object’s `VAR`s automatically.

## Control flow notes

- `REPEAT` / `REPEAT WHILE` / `REPEAT UNTIL` / counted `REPEAT`
- `CASE` with ranges (`10..15`) and `OTHER`
- `ABORT` unwinds to the nearest catcher; display-list builders in lib_vjet use this on overflow
- Booleans: non-zero is true; logical ops promote non-zero to −1
- `not` is boolean unary (result 0 or −1) and binds tighter than `&`. `if not x & mask` means `(not x) & mask`. For a bit field write `(x & mask) <> field`. `!` is bitwise invert (`acia_status &= !flag`).

## House style in this repo

1. Keep Spin for orchestration; leave scanline / bus bit-bang in PASM.
2. Match neighbouring comment density; do not narrate obvious assignments.
3. Import pin and port constants from the owning object (`acia#PORT_80`, `i2c#SDA_PIN` in `ddc_i2c.spin`) instead of duplicating magic numbers.
4. Prefer existing buffer/mask patterns (`BUFFER_LENGTH` power of two, `BUFFER_MASK`) when adding FIFOs.
5. Count and check methods (`rxCount`, `rxPeek`, `txCheck`, `txSpace`) must not change status bits. ACIA status bits are PASM-only. `tdreHold` writes `tdre_hold`, not `acia_status`. `tx` / `rx` abort on `req_parse_idle` / `req_master`. Do not add `txFlush`/`rxFlush` that write both FIFO ends. Do not add XON/XOFF (`module-ux`).
6. Prose in new comments and docs follows `style-ste-writing` (STE-flavored).

## Propeller 2 / Spin2 — reject

If a snippet uses Spin2-only forms (`HUBSET`, `PINWRITE`, `COGATN`, `debug(`, P2 registry builtins), it is the wrong chip. Translate to P1 Spin+PASM or discard.

## Related

- Hardware model: `hw-propeller`
- Assembly: `lang-pasm` (+ `references/spin-pasm-bridge.md`)
- Tools: `tool-propeller`
- Product wiring: `module-ux`

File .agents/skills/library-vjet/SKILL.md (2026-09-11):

---
name: library-vjet
description: >
  VECTORJET (lib_vjet) scanline 3D/2D engine for the UX Module: display-list
  Spin API, multi-cog PASM renderer, VGA output cog, double-buffered lists,
  shape types (trap stack, box, text). Use when editing src/lib_vjet or
  integrating graphics with the UX firmware. See ARCHITECTURE_LIB_VJET.md.
---

# Library — VECTORJET (`src/lib_vjet`)

Human architecture note: `ARCHITECTURE_LIB_VJET.md`. Author mark in sources: IRQsome Software (UXM specialisation).

## Files

| File | Role |
|---|---|
| `VJET_v01_displaylist.spin` | Spin display-list builder (API) |
| `VJET_vUXM_rendering.spin` | PASM render cog(s); fills scanline buffer |
| `VJET_vUXM_vga.spin` | PASM VGA output cog; consumes scanlines |
| `hexfont.spin` | Bitmap font for `text*` shapes |
| `vjet_test.spin` / `graphtest.spin` | Top-object demos |

## Pipeline

```
Spin app
  ├─ Vblank (status bit 16) then dlist_ptr := listA
  ├─ WaitListTaken (status bit 17) then gl.start(listB) / draw / gl.done
  ├─ render.start(i, N, scanbuf, @dlist_ptr, @vga_status, @ready)  × N
  └─ vga.start(pinGroup, scanbuf, @vga_status)
         │
         ▼
  render cogs traverse display list → write scanline tiles into scanbuf
         │
         ▼
  VGA cog WAITVID from scanbuf, signals phase in vga_status
```

Resolution in UXM rendering: **WIDTH=256**, **NUM_LINES=240**, **LINE_BUFFERS=8**. VGA driver doubles lines (tileCounter) for display.

`vjet_test.spin` starts **3** render cogs + **1** VGA cog. That alone needs four cogs plus Spin. It cannot run beside the full UX text stack without stopping other drivers (`module-ux` cog budget).

`ux_module.spin` does not link this library. Demos are their own tops. When graphics work resumes, product graphics uses **2** render cogs plus 1 VGA cog. The spare cog is for a Spin draw loop. Do not start VECTORJET from product `main`.

Handshake: VGA writes line **240** in every blanking phase (not 0). Render cogs wait for `>= 240`, fill slots 0..7, then stay fewer than eight lines ahead of the live line. Spin publishes `dlist_ptr` at front porch and waits for vsync bit 17 before it rebuilds the other list.

Video PLL: NCO 5 MHz, VCO/2, VCO 80 MHz (spec 64–128). Do not restore 10 MHz NCO + VCO/4 (VCO 160 MHz).

## Display list format

Shape header (8 bytes), then type-specific body:

```
WORD  pointer to next shape or 0
BYTE  renderer sync line
BYTE  shape type
WORD  start scanline
WORD  end scanline
```

| Type | Name | Body (after header) |
|---|---|---|
| 1 | `SHP_TRAPSTACK` | 16-byte trap header + N×12-byte trapezoids |
| 2 | `SHP_BOX` | left, right, colours, unused (words) |
| 3 | `SHP_TEXT` | scale, font ptr, string ptr, colours, x |

Coordinates in the Spin API often use **16.16** fixed point (shift `<<16`). Colours are packed words consumed by the renderer/VGA path (two paint colours common in demos, e.g. `$ECEC`).

Builder calls:

- `start(ptr,size)` / `done` — begin/end list; `done` aborts link on overflow
- `set_clip(t,b,l,r)`
- `triangle` / `polygon` / `box` / `line` / `point` / `text*`

Overflow uses Spin `ABORT`. Callers in demos use `\draw` to trap it.

## Double buffering

Demos flip `dlist_ptr` each frame and rebuild the inactive buffer. Render cogs read `dlist_ptr` through `dlistPtrAdr` at frame start. Wait for vertical blank via `vga_status` bit 16 (`Vblank`), publish the pointer, then wait for vsync bit 17 (`WaitListTaken`) before `gl.start` on the other list.

## VGA cog (`VJET_vUXM_vga.spin`)

- `start(pinGroup, lineBuffers, statusLong)` — `pinGroup` 0..3; UX uses `16/8` → group 2
- Sets `VCFG` VGA mode, CTRA PLL video mode, drives eight pins
- Writes phase codes into `statusLong` (front porch / vsync / back porch / active). Low word is 240 in all three blanking phases.

## Agent rules

1. Keep display-list field sizes and offsets matched between `VJET_v01_displaylist.spin` comments and renderer PASM readers.
2. Do not change `WIDTH` / `NUM_LINES` / `LINE_BUFFERS` in one file only; scan buffer size in the top object must match `(WIDTH*LINE_BUFFERS)/4` longs. VGA wrap is `tilesCounter & (LINE_BUFFERS-1)`.
3. Preserve top-edge trap fixup and per-cog scanline striping (`currentscanline += total_cogs`).
4. Treat UXM files as board-specialised; do not assume stock VECTORJET v1.0 timing.
5. Do not write line 0 during vsync or back porch. Do not let a render cog write more than `LINE_BUFFERS` lines ahead of VGA.
6. Stop text VGA (`wmf.stop`) **and** the I2C DDC cog (`i2c.stopCog`) before `VJET_vUXM_vga.start`. Stop VECTORJET VGA and `render.stop` before `wmf.init` and `i2c.startCog`. Never two VGA engines on P16–P23. The product top has no `enterGraphics` yet.
7. Do not put the display-list builder on Cog 0 if ACIA must keep pumping (`module-ux`).
8. Prose: `style-ste-writing`.

## Related

- Hardware video: `hw-propeller`
- Board pins: `hw-ux-pcb`
- Product cog budget: `module-ux`
- PASM detail: `lang-pasm`

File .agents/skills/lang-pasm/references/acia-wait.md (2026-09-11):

# ACIA `/WAIT` loop (P8X32A)

Canonical rules for the bus wait in `src/acia_rc2014.spin`. A 68B50 places data in ≤150 ns (`docs/MC6850.pdf` page 4, MC68B50 `tDDR`). This cog cannot do that, so it stretches the Z80 I/O cycle on P24.

Do not treat this as a 6850 pin. The chip has Enable (E), not `/WAIT`.

## Match value

At entry the cog ORs `/M1` and `WAIT_PIN` into the Hub `acia_base` long. Each pass through `wait` loads that long into `OUTA`.

`port_active_mask` is `WAIT_PIN | M1_PIN | PORT_MASK`. Every 1-bit in the match value that `WAITPEQ` compares must also be 1 in this mask, or the wait never ends.

`OUTA` bit 24 (`/WAIT`) is 1 (released, open-collector via a diode) before the match.

## Required sequence

```
waitpne outa, port_active_mask      ' this cycle has ended (idle: returns at once)
waitpeq outa, port_active_mask wr   ' match + assert /WAIT
andn    outa, bus_int               ' undo carry into P25
```

Do not put Hub work (`RDLONG` / `WRLONG` / `CALL #sync_irq`) or an idle poll between `waitpne` and `waitpeq`. `1ea0c6b` did that and missed the 8085 I/O cycle. `sync_irq` runs in `transmit_status` after `/WAIT` is asserted.

Then decode A0 / `/RD` / `/WR`. Handlers release `/WAIT` with `or outa, bus_wait` before they return to `wait`. After release, wait for `/RD` or `/WR` high with `wait_pin_high` (poll `req_master`). Do not use `waitpeq bus_rd` / `bus_wr` for that wait.

## `wr` effect (do not remove)

`WAITPEQ dest, mask wr` does **not** write `INA`. After the pin pattern matches, it does `dest := dest + mask` (same reload idea as `WAITCNT`).

`OUTA` already has P24 high. The mask also has P24. Add: bit 24 becomes 0, so `/WAIT` goes low **in that instruction**. Carry sets `OUTA` bit 25 (`/INT`). The next `andn outa, bus_int` clears that bit.

`add outa, port_active_mask` is the same ALU. Prefer the `waitpeq … wr` form so match detect and `/WAIT` assert stay one instruction.

## Do not

1. Drop `wr` and assert `/WAIT` later with `andn outa, bus_wait`. That leaves the Z80 in T2 with no stretch.
2. Put Hub ops (`RDLONG` / `WRLONG` / `CALL` to `sync_irq`) on the path from “pins match” to `waitpeq … wr`.
3. Take `/WAIT` out of the match value or out of `port_active_mask`.
4. Replace `andn outa, bus_int` after `wr`. If `DIRA[25]` is on and `OUTA[25]` stays 1, `/INT` glitches high on every ACIA cycle.
5. Drive P24 or P25 `DIRA` from a Spin cog. This PASM cog owns both.

## `/INT` (P25)

Hold the pin low while `(RIE and (RDRF or OVRN)) or (exact CR5/CR6 TIE and TDRE)`. Float it when that is false. `OUTA` bit 25 stays 0 so a driven pin is low. `SR_IRQ` follows the pin (`docs/MC6850.pdf` pages 6 and 9).

Tree: `sync_irq` composes `acia_status` on a status read after `/WAIT`. Spin does not RMW that long. Spin still pulses `DIRA[25]` when RIE/TIE. `wait_pin_high` samples `req_master` and may `jmp #do_master_reset`. Spin `tx` / `rx` abort on reset flags. Spin `tdreHold` / `tdreAllow` write Hub `tdre_hold`. Product flow: `module-ux`. Open IDs: `module-ux/references/remaining-errors.md`.

## Related

- Code: `src/acia_rc2014.spin` labels `wait`, `sync_irq`
- Flags and FIFOs: `module-ux`
- Pins: `hw-ux-pcb`
- OBEX `WAITPEQ` tip: [obex-pasm.md](obex-pasm.md)

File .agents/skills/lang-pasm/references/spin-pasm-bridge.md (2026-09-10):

# Spin ↔ PASM bridge (Propeller 1)

Spin and PASM **do not call each other**. They share **Hub RAM**. The mailbox is usually a Hub struct whose address is passed in `PAR`.

## Launch

```
VAR
  long  hubstruct[…]          ' or named fields
  long  stack[64]             ' only for Spin cogs

DAT
entry   org 0
        mov     ptr, par
        rdlong  …
        …

PUB start
  cog := cognew(@entry, @hubstruct) + 1     ' PASM cog; PAR = @hubstruct
  cog := cognew(spinMethod, @stack) + 1     ' Spin cog; needs Hub stack
```

| Launch | Second arg | Meaning |
|---|---|---|
| `cognew(@pasmLabel, hubPtr)` | Hub address | Loaded into that cog’s `PAR` |
| `cognew(spinMethod, @stack)` | Stack pointer | Spin interpreter in the new cog |
| `coginit(id, …)` | same | Restart a specific cog ID |

`cognew` returns 0…7 or −1. House style stores `id+1` so 0 means “not running”.

## Typical PASM prologue

```
entry                   mov     t1, par
                        add     t1, #offset
                        rdlong  field, t1
```

Walk a contiguous Hub block (ACIA and UART drivers do this). Document field offsets at the Spin `VAR` declaration.

## What each side owns

| | Spin | PASM |
|--|---|---|
| Runs in | Interpreter cog (bytecode in Hub) | Native cog (image copied from DAT) |
| Locals | Hub stack / VAR | Cog RAM (`RES` / reused init) |
| Cross talk | `byte`/`word`/`long[addr]`, locks | `RD*`/`WR*`, locks |
| Pins | Same `DIRA`/`OUTA`/`INA` model | Same; per-cog registers OR’d in hardware |

## Patterns in this tree

| Module | Bridge |
|---|---|
| `acia_rc2014.spin` | `cognew(@entry, @rx_head)` — 11 longs: FIFOs, config/status, `tdre_hold`, `req_master`, `req_parse_idle` |
| `terminal_ftdi.spin` | `cognew(@entry, @rx_head)` — same shape; `JMPRET` inside cog |
| `keyboard_ps2.spin` | `cognew(@entry, @par_tail)` |
| `hires_text_vga.spin` | two `cognew(@d0, SyncPtr)` |
| `VJET_vUXM_*.spin` | `cognew` + DAT params filled with `longmove` before start |
| `ux_module.spin` | Cog 0 Spin loop: `kbdToZ80` / `termToZ80` / `readZ80`. No extra pump cog. |

## Pitfalls

1. Forgetting the Hub stack for a **Spin** `cognew` → crash.
2. Passing a Spin method address where a PASM `@label` is required (or the reverse).
3. Assuming PASM can `CALL` a Spin `PUB` — it cannot; use Hub mailboxes.
4. Starting PASM before Spin has written the Hub struct / `long 0-0` placeholders.
5. Two writers on the same Hub long without a protocol or lock.
6. Confusing **pin P2** (board net) with **Propeller 2** (chip generation).

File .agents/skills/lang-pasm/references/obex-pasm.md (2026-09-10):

# OBEX PASM references (Propeller 1 only)

External **Propeller 1** snippets used to cross-check this repo’s PASM skills.
Index: https://obex.parallax.com/code-language/pasm — **skip Propeller 2 objects** on that tag.  
Tips hub: https://obex.parallax.com/docs/chips-tips/propeller-1/

Full doc list: [p1-sources.md](p1-sources.md). Prefer tree + datasheet when behaviour disagrees. Use OBEX for idioms and worked examples.

| Topic | Link | Tree match |
|---|---|---|
| Pause / `WAITCNT` reload | [How to pause in PASM](https://obex.parallax.com/docs/chips-tips/propeller-1/how-to-pause-in-pasm/) | UART bit timing; Spin `waitcnt(clkfreq/… + cnt)` |
| Pin masks `OR`/`ANDN`/`XOR`/`MUX*`/`TEST` | [IO pin manipulation using PASM](https://obex.parallax.com/docs/chips-tips/propeller-1/io-pin-manipulation-using-pasm/) | ACIA `/WAIT` `/INT` data bus; FTDI masks |
| Per-cog `DIRA`/`OUTA`, shared `INA` | [Control IO pins from any cog](https://obex.parallax.com/docs/chips-tips/propeller-1/control-io-pins-from-any-cog/) | Open-collector **level** on `/INT` (ACIA cog only) |
| Spin pin ranges | [Simultaneous pin group control](https://obex.parallax.com/docs/chips-tips/propeller-1/simultaneous-pin-group-control/) | `dira[8..15]` style (Spin side) |
| `WAITPEQ` / `WAITPNE` | [WAITPEQ and WAITPNE with PASM](https://obex.parallax.com/docs/chips-tips/propeller-1/waitpeq-and-waitpne-with-pasm/) | ACIA address wait; I2C SCL wait |
| VAR vs DAT | [How to choose between VAR and DAT](https://obex.parallax.com/docs/chips-tips/propeller-1/how-to-choose-between-var-and-dat/) | Driver params in VAR; PASM image in DAT |
| Timing measurement | [Code Execution Time on the P8X32A](https://obex.parallax.com/obex/code-execution-time-on-the-p8x32a/) | Cycle budgets for bus/VGA |
| `JMPRET` coroutines | [Coroutines in PASM (AN014)](https://obex.parallax.com/obex/coroutines-in-pasm-an014/) | `terminal_ftdi.spin` rx/tx ping-pong |

## Idioms confirmed against `src/`

### `WAITCNT` pause (OBEX pause tip)

```
mov     timer, TICKS
add     timer, cnt
loop    waitcnt timer, TICKS
        djnz    count, #loop
```

`waitcnt dest, #delta` waits until `CNT == dest`, then writes `dest + delta` back into `dest`.

### Pin force high / low / toggle (OBEX IO tip)

| Goal | PASM |
|---|---|
| Output + high | `or dira, mask` then `or outa, mask` |
| Output + low | `or dira, mask` then `andn outa, mask` |
| Toggle | `xor outa, mask` |
| Release to input | `andn dira, mask` |
| Sample pin | `test mask, ina wc` / `wz` |

### `WAITPEQ` / `WAITPNE` (OBEX + datasheet)

```
waitpeq state, mask     ' until (INA & mask) == state
waitpne state, mask     ' until (INA & mask) != state
```

Rules:

1. Every 1-bit in `state` must also be 1 in `mask`, or `WAITPEQ` never completes.
2. Common edge wait: `waitpne mask, mask` then `waitpeq mask, mask` (wait for 1).
3. **`WR` effect is not “write INA”.** For `WAITPEQ dest, mask wr`, the destination becomes `dest + mask` (ALU add). UX ACIA uses this to assert `/WAIT` on address match (`acia_rc2014.spin`). Do not “simplify” that `wr` away. Full loop: [acia-wait.md](acia-wait.md).

### `JMPRET` coroutine (AN014; `terminal_ftdi.spin`)

```
receive   jmpret rxcode, txcode    ' swap to transmit fragment
          …
transmit  jmpret txcode, rxcode
```

One cog time-slices two tasks without Hub locks.

### DAT placeholders filled from Spin

```
MS_TICKS  long  0-0     ' Spin writes before cognew
msecs     res   1       ' cog-only scratch (not in Hub image meaningfully)
          FIT
```

`0-0` is a readable zero placeholder. `RES` reserves cog RAM after the loaded image.

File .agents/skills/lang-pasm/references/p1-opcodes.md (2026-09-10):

# Propeller 1 (P8X32A) — PASM instruction card

Authority: `docs/Propeller Quick Reference v1.7.pdf`. Full prose: Manual v1.2 Chapter on Propeller Assembly.  
**Not** Propeller 2 / PASM2.

## Instruction encoding (mental model)

```
Label   Condition   INST   Dest, 〈#〉Src   Effects
```

| Field | Width | Notes |
|---|---:|---|
| Dest (D) | 9-bit cog address | Register 0–511 (specials in the top of cog RAM) |
| Src (S) | 9-bit | Register **or** `#immediate` (0–511 only) |
| Condition | optional | Default = always |
| Effects | optional | `WC` `WZ` `WR` `NR` |

### Immediate size (pitfall)

`#n` fits in **9 bits** (0…511). Larger constants must live in cog RAM:

```
myconst         long    1_000_000
                mov     temp, myconst
```

Self-mod placeholders often written `0-0` (equals zero; patched later with `MOVS`/`MOVD`/`MOVI`).

## Timing (quick ref footnotes)

| Class | Clocks |
|---|---|
| Most ALU / `JMP` / `MOV` / … | **4** |
| Conditional jump **taken** (`DJNZ`/`TJZ`/…) | **4** |
| Conditional jump **not taken** | **8** |
| Hub ops (`RD*`/`WR*`/`LOCK*`/`COG*`/`CLKSET`) | **8…23** (sync to hub window + 8) |
| `WAITCNT` / `WAITPEQ` / `WAITPNE` | **6+** until event |
| `WAITVID` | **4+**; pixel handoff needs ~6–7 clocks between frames |

Interleave two 4-clock cog ops between hub ops when Hub bandwidth matters.

## Effects

| Effect | Meaning |
|---|---|
| `WC` | Write C from the op’s C result |
| `WZ` | Write Z from the op’s Z result |
| `WR` | Write destination (default for most ALU) |
| `NR` | Do **not** write destination (flags-only / compare style) |

## Conditions (subset agents use most)

| Condition | Meaning |
|---|---|
| `IF_Z` / `IF_E` | Z set |
| `IF_NZ` / `IF_NE` | Z clear |
| `IF_C` / `IF_B` | C set |
| `IF_NC` / `IF_AE` | C clear |
| `IF_A` | above (!C & !Z) |
| `IF_BE` | below or equal (C \| Z) |
| `IF_C_AND_Z` … | combined; see quick ref full grid |

Predicted **taken**. Not-taken costs the extra 4 clocks.

## Instruction groups

### Arithmetic / logic (typically 4 clocks, WR default)

`ABS` `ABSNEG` `ADD` `ADDABS` `ADDS` `ADDSX` `ADDX`  
`SUB` `SUBABS` `SUBS` `SUBSX` `SUBX`  
`SUMC` `SUMNC` `SUMZ` `SUMNZ`  
`NEG` `NEGC` `NEGNC` `NEGZ` `NEGNZ`  
`AND` `ANDN` `OR` `XOR`  
`MIN` `MAX` `MINS` `MAXS`  
`CMP` `CMPS` `CMPX` `CMPSX` `CMPSUB` (often `NR`)  
`TEST` `TESTN` (`NR`)

### Shifts / rotates

`SHL` `SHR` `SAR` `ROL` `ROR` `RCL` `RCR` `REV`

### Move / patch

`MOV` `MOVS` `MOVD` `MOVI` `MUXC` `MUXNC` `MUXZ` `MUXNZ`

### Flow

`JMP` `JMPRET` `CALL` `RET` `DJNZ` `TJZ` `TJNZ` `NOP`

`CALL #label` writes the return address into `label_ret`’s S field. Local labels start with `:`.

### Hub / system (8…23)

`RDBYTE` `RDWORD` `RDLONG` `WRBYTE` `WRWORD` `WRLONG`  
`LOCKNEW` `LOCKRET` `LOCKSET` `LOCKCLR`  
`COGID` `COGINIT` `COGSTOP` `CLKSET`

### Wait / video

`WAITCNT` `WAITPEQ` `WAITPNE` `WAITVID`

`WAITPEQ dest, mask WR` → destination becomes **`dest + mask`** (not a copy of `INA`). ACIA `/WAIT` loop: [acia-wait.md](acia-wait.md). Also `obex-pasm.md`.

## Directives

| Directive | Rule |
|---|---|
| `ORG 〈addr〉` | Set cog compile pointer (usually 0) |
| `FIT 〈addr〉` | Assert prior code/data fits below addr (often 496) |
| `long` / `word` / `byte` | Initialized data in the cog image |
| `RES n` | Reserve *n* longs **after** all initialized data |

**`RES` must follow initialized `long`s** in the cog image. Putting `RES` in the middle leaves holes the assembler may not treat as you expect; house style keeps `RES` at the end (before `FIT`).

## Special registers (top of cog RAM)

Agents touch often: `PAR` `CNT` `INA` `OUTA` `DIRA` `CTRA` `CTRB` `FRQA` `FRQB` `PHSA` `PHSB` `VCFG` `VSCL`.

`PHSx` reads are source-operand only; RMW uses the last written value, not the live accumulator.

## Forbidden on P1 (Propeller 2 / PASM2)

Do not emit or “upgrade” to:

`WAITX` `WAITCT1`… `DRVL` `DRVH` `DRVNOT` `FLOAT` `PINW` `WRPIN` `WXPIN` `WYPIN`  
`##immediate` (P2 long immediate) `AUGS` `AUGD` `HUBSET` `COGATN` `POLLATN`  
`DIRB`/`OUTB`/`INB` as P2 port B, LUT exec, smart-pin registers, `SKIP`/`EXECF`, etc.

If an OBEX or web snippet shows those mnemonics, it is **P2** — discard for this repo.

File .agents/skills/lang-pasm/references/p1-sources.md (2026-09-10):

# Propeller 1 — source documents

This project is **P8X32A (Propeller 1) only**. Do not load Propeller 2 manuals into agent context for edit work.

## In-tree (prefer these)

| Doc | Path | Use |
|-----|---|-----|
| Propeller Manual v1.2 | `docs/P8X32A-Web-PropellerManual-v1.2.pdf` | Spin blocks, language, PASM chapter |
| Propeller Quick Reference v1.7 | `docs/Propeller Quick Reference v1.7.pdf` | Spin + PASM cheat sheet (opcode / condition / effect / clocks) |
| P8X32A datasheet | `pcb/P8X32A-Propeller-Datasheet-v1.4.0_0.pdf` | Hub timing, video, counters, electrical |
| MC6850 | `docs/MC6850.pdf` | ACIA register model (board peripheral) |
| ACIA `/WAIT` loop | `.agents/skills/lang-pasm/references/acia-wait.md` | P24 dest+mask stretch. Do not drop `wr`. |

## External (idioms and community tables)

| Doc | URL | Use |
|-----|-----|-----|
| OBEX PASM tag | https://obex.parallax.com/code-language/pasm | Snippets; **filter to Propeller 1** |
| Propeller 1 tips | https://obex.parallax.com/docs/chips-tips/propeller-1/ | Pause, WAITPEQ, VAR/DAT, pin masks |
| Ed Parsons PASM quick ref thread | https://forums.parallax.com/discussion/90092/pasm-quick-reference | Historic 2-page PDF (same class as in-tree quick ref) |
| Cluso99 P1 instruction-set summary | https://forums.parallax.com/discussion/164612/p1-instruction-set-summary | Opcode / cond / flags community table |
| OpenSpin | https://github.com/parallaxinc/OpenSpin | Open-source P1 Spin+PASM compiler (`openspin`). Build steps: `tool-propeller` |
| PropLoader | https://github.com/parallaxinc/PropLoader | P1 serial/WiFi loader (`proploader`) for FTDI FT232. Build steps: `tool-propeller` |
| FlexProp / flexspin | https://github.com/totalspectrum/flexprop | Optional; can target P1 — still emit **P1** mnemonics only |

## Out of scope (Propeller 2)

Do **not** use these for this repository:

| Doc | Why excluded |
|-----|---|
| https://www.parallax.com/propeller-2/documentation/ | P2 hub / smart pins / Spin2 |
| PASM2 manuals, Gracey P2 spreadsheets | Different ISA |
| PNut / Propeller Tool P2 mode | Wrong chip |
| Mnemonics `WAITX`, `DRVL`, `DRVH`, `##imm`, `HUBSET`, smart-pin regs | PASM2 only |

Authority when facts conflict: **tree `src/` → in-tree datasheet/manual → OBEX P1 tips**. Forum PDFs are secondary mirrors of the same P1 ISA.

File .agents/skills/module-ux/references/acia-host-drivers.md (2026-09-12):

# ACIA host drivers vs this emulation

Checked 2026-09-12 for a **text-mode release candidate**. Not a live XMODEM check.

Sources:

- [RomWBW `Source/HBIOS/acia.asm`](https://github.com/wwarthen/RomWBW/blob/master/Source/HBIOS/acia.asm)
- [CPM-IDE `8085-cf-acia/cpm22bios.asm`](https://github.com/feilipu/CPM-IDE/blob/master/8085-cf-acia/cpm22bios.asm) from `_acia_interrupt`
- Tree: `src/acia_rc2014.spin`, `src/ux_module.spin` `PORT_DEFAULT` (`0x80`)

Punch list: [remaining-errors.md](remaining-errors.md). Wait loop: `lang-pasm/references/acia-wait.md`.

## Verdict

Neither driver needs a 6850 feature this tree does not already emulate for **text console**. Do not treat this as a clean bill of DDC, HDMI lock, or XMODEM transfer.

Default decode is `acia.start(PORT_DEFAULT)` (`0x80`). `PORT_ROMWBW` (`0x40`) is in source, commented.

## What they issue

| Operation | RomWBW | CPM-IDE 8085 | This tree |
|---|---|---|---|
| Probe | `OUT $03`, status must be **0**. Then `OUT $02`. Status `& %00001110 == %00000010` (TDRE, CTS=0, DCD=0). | Chip is live from ROM CRT. BIOS `_acia_reset` zeros **software** rings only. | Status **0** while config is `$03`. After `$02`, `sync_irq` sets TDRE. CTS/DCD stay 0. |
| Init | `$03` then `$16` (8N1, /64, RTS low). IM1 ORs **RIE** (`$96`). No TIE. | CRT sets RIE/TIE/RTS. Warm boot does not rewrite the chip. | Stores the control byte. Clock divide and word select are not driven. Data path is 8-bit FIFO. |
| RX ready | Status bit 0 `RDRF`, or IM1 ring (32 bytes). | Software `aciaRxCount` after INT 65. | `RDRF` from TX FIFO unless `/RTS` high. |
| TX ready | Poll status bit 1 `TDRE`, then `OUT` data. | Immediate `OUT` if TDRE and Tx ring empty. Else ring + **TIE** (`TEI_RTS0`). | `TDRE` if RX FIFO has room and `tdre_hold` is 0. |
| `/RTS` | IM1: RTS high at 16/32, low at 8/32. `OR %01000000` / `AND %10111111`. | ISR: RTS high (`TDI_RTS1`) when RX fullish. `getc` sets RTS low (`TDI_RTS0`) when emptyish. | Exact `CR_TID_RTS1`: hide `RDRF`, keep FIFO, present `last_rdr`. Spin does not pulse `/INT` while RTS1. |
| IRQ | IM1: **RIE only**. ISR tests `RDRF`, not `SR_IRQ`. | 8085 RST 6.5. ISR tests `RDRF` then `TDRE`. Enables **TIE** when the Tx ring is not empty. | `sync_irq` on a **status read**. Spin pulses `DIRA[25]` on RIE/TIE. |
| Errors | Unused. Full software ring drops the byte. | Unused. | `PE`/`FE`/`OVRN` stay 0. Full TDR write is dropped. |
| 8-bit | 8N1 | Parity strip is commented out (XMODEM). | 8-bit through. |

`_acia0_*` and `_acia1_*` in CPM-IDE are the **same** chip. IOBYTE `$81` (CRT) still hits one ACIA.

## Gaps that do not block text RC

1. **Word select and clock divide.** Both drivers write them. This tree ignores them. They do not read the control register back.
2. **Break (`TC=11`).** RomWBW documents it. Neither console path uses it.
3. **`PE` / `FE` / `OVRN` / `SR_IRQ` as a poll bit.** Unused.
4. **1-byte TDR vs 512-byte FIFO.** Real 6850 `TDRE` clears for one character time after `OUT`. This tree keeps `TDRE` set until the FIFO is full or `tdre_hold`. CPM-IDE then drains its Tx ring faster. Safe for text.
5. **No `sync_irq` on a control write.** TIE on/off does not move `/INT` until the next status read. CPM-IDE ISR always starts with `IN` status. One extra INT 65 is possible. It is not a hang.
6. **Second ACIA.** RomWBW can have `ACIACNT >= 2`. This tree decodes one base. A second probe fails detect.

## Gaps to know. Do not “fix” for this RC

1. **RomWBW + SIO on `0x80`.** HBIOS ACIA then sits at `0x40`. Use the commented `PORT_ROMWBW` line. Wrong base: detect fails.
2. **CP/M warm boot does not `$03` the chip.** `_acia_reset` only clears 8085 rings. Propeller boot and panic now restart the ACIA cog while P5 is held. Warm boot without a P5 pulse still leaves FIFOs. Do not add `txFlush`/`rxFlush`. Do not poll P5.
3. **`tdre_hold`.** If FTDI TX is full, this tree hides `TDRE`. RomWBW `ACIA_OUT` and CPM-IDE `putc` wait. Console pauses. That is FTDI back-pressure, not a 6850 miss.
4. **Live XMODEM.** Both sides pass 8-bit data. Host/Z80 session gates have no live transfer check yet. Text console does not need that.

## Do not change from this report

- Wait pair (`waitpne` then `waitpeq wr`).
- Status 0 while config is `$03` (RomWBW probe).
- Exact `CR_TID_RTS1` and exact `CR_TIE_RTS0`.
- Spin `DIRA[25]` pulse on RIE/TIE.
- Drop full TDR. Do not set `OVRN`.

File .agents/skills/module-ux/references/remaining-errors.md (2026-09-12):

# ACIA/flow punch list (open)

Policy (what to keep or undo) is the revert-notes table in `module-ux`. This file is the tree vs that policy. It is **not** a clean bill of health.

XMODEM, VGA cursor, and boot-reset findings: [ship-review.md](ship-review.md). RomWBW and CPM-IDE ACIA clients vs this tree: [acia-host-drivers.md](acia-host-drivers.md). Text RC: those drivers do not need a 6850 feature this tree lacks. Live XMODEM is still open.

Bus cog: **`569cd07` wait loop** (`rdlong` base, `waitpne`, `waitpeq wr`). No Hub between those waits. Rise wait is `wait_pin_high` (poll pin and `req_master`). Mailbox is **11 longs**. `last_rdr` is cog RAM.

Probe after each slice: ROM banner plus `ABC\r` → `ABC\r\n\r\n> `.

## Status vs tree

| ID | Policy fix | In this tree | Notes |
|----|---|---|---|
| **P0-1** | Hold P5 1 ms, discard host RX, restart ACIA cog (`last_rdr` and FIFOs zero), `tdreHold`. Panic: VGA `CS`, FTDI `clear` only if 4 TX slots | **Landed (Spin).** Boot `pulseZ80Reset` uses the same wipe. | Do not wait on `req_master`. Keep gated `clear`. |
| **P0-2** | Sample `req_master` in idle/`wait_pin_high`; no `waitpeq` on `/RD` `/WR` rise | **Partial.** `wait_pin_high` samples `req_master`. Spin does **not** wait on the flag. Idle Hub between `waitpne` and `waitpeq wr` is forbidden. | Rise abort only. |
| **P0-3** | Sample P5 when not driving. 1 ms debounce. Wipe ACIA once per backplane `/RESET`. Keep `tdre_hold` | **Landed.** D1 pulls P5 high while `/RESET` is idle. Do not drive P5 in reply. | Idle poll with no debounce was the false-trigger. |
| **P0-4** | FTDI RX drop when full; no XON/XOFF | **In tree.** | Do not restore wrap-over or XON. |
| **P0-5** | Skip `kbdToZ80` on host `SOH`/`STX` | **Landed (packet machine).** | `hostXm` ends on `EOT`/`ETB`/`CAN` in GAP only. `z80XmSess` covers the ACK gap. |
| **P1-1** | `req_parse_idle` before PASM zeros indexes; Spin `tx`/`rx` abort | **Landed.** | Keep the take in the loop. |
| **P1-2** | Pump LF when FTDI TX is full | **In tree.** | Done. |
| **P1-3** | `tdreAllow` only when the next byte fits | **Landed.** `sync_irq` honours `tdre_hold`. | After `/WAIT` only. |
| **P1-4** | XMODEM-1K parser | **Landed.** Opaque trailers (1 checksum, 2 CRC / `STX`). | Do not sniff CRC-lo as `SOH`. No live transfer check yet. |
| **P2-1** | Panic sets `acia_config` `$03` | **Landed.** | `do_master_reset` does not clear `tdre_hold`. |
| **P2-2** | PASM only writer of `acia_status` | **Partial.** Live compose is `sync_irq` on a status read. Spin does not RMW `acia_status`. Spin still **pulses** `DIRA[25]` when RIE/TIE. Trailing `tx` pulse uses `not (config & mask)`. Removing that pulse dropped host keys (RX empty). `start` writes initial status before `cognew`. | Do not idle `sync_irq`. Keep the Spin INT pulse. |
| **P2-3** | Full TDR: drop write, no `OVRN` | **Landed.** | Done. |
| **P2-4** | Delete `txFlush` / `rxFlush` | **Landed.** | Done. |
| **P2-5** | Hub map | **11 longs.** `last_rdr` is cog RAM. | See table. |
| **P2-6** | `tx`/`rx` abort on reset flags | **Landed** with P1-1. | Done. |
| **P3-1** … **P3-5** | CUP, TAB, CR, `PUMP_LIMIT`, `outa` before `dira` | **In tree.** | Done. |

## Empty / `/RTS` RDR

**Landed.** Same drive timing as `569cd07` (rdbyte, then shl, then `or outa`). Empty or cached `CR_TID_RTS1` presents `last_rdr` and rewinds `tx_tail`. Earlier branch-before-drive `last_rdr` failed (`ACC`, high-bit bytes) and must not be restored.

## Hub writer map (this image)

| Cell | Writer now | Policy writer |
|---|---|---|
| `tx_head` | Spin `tx` (abort on flags) | Spin (abort on flags) |
| `tx_tail` | PASM; Spin `masterReset` (panic wipe while `waitpeq` has no match) | PASM only |
| `rx_head` | PASM; Spin `masterReset` | PASM only |
| `rx_tail` | Spin `rx` (abort on flags) | Spin (abort on flags) |
| `acia_status` | PASM `sync_irq` (live). `start` before `cognew`. `$03` / `do_master_reset` write the reset value. | PASM `sync_irq` only |
| `acia_config` | PASM `receive_command` / `do_master_reset`; Spin `start` / `masterReset` | PASM + `start` |
| `tdre_hold` | Spin `tdreHold` / `tdreAllow` / `masterReset` | Spin |
| `req_master` | Spin `masterReset` sets 1; PASM `do_master_reset` sets 0 | Spin 1, PASM 0 |
| `req_parse_idle` | PASM `$03` / `do_master_reset` sets 1; Spin `takeParseIdle` / `start` sets 0 | PASM 1, Spin 0 |
| `DIRA[25]` | Spin `tx`/`rxCount` pulse when RIE/TIE. PASM `sync_irq` level on a status read. | PASM level only |

## Failed slices (do not retry the same way)

1. `last_rdr` with extra Hub/branch **before** the RDR drive (echoed `ACC` / high-bit bytes).
2. `sync_irq` as the only status writer **and** no Spin INT pulse (RX empty).
3. Idle `sync_irq` between `waitpne` and `waitpeq wr` (silent 8085).
4. Spin `masterReset` wait on `req_master` while P5 is held (deadlock).

Do not: idle `sync_irq`, Hub between `waitpne` and `waitpeq wr`, poll P5 with no debounce, drive P5 in reply to a backplane pulse, restore XON/XOFF, drop the Spin INT pulse.

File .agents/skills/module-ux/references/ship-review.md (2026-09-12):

# Ship review — UX Module text firmware

Combative review of `src/ux_module.spin` and child objects. Date: 2026-09-11. Product is text VGA only. VECTORJET is not linked.

Line numbers refer to the tree **before** the ship fixes. This file is the checklist. It is not a clean bill.

Related: `remaining-errors.md` (ACIA punch list), `acia-host-drivers.md` (RomWBW / CPM-IDE vs this tree), `module-ux` revert notes.

## Verdict

Ship it as a **text console**. Do **not** trust it as an XMODEM pipe, especially not CRC-16 / 1K CRC. Screen motion is CP/M CR+LF plus a few CSI codes, not VT100. Characters are protected on the happy path and dropped on several real edges.

## Priority (ship blockers)

| # | Issue | Fix |
|---|---|-----|
| 1 | CRC-16 trailer sniffed as a new frame | Count 1 or 2 trailers. Do not sniff delimiters in the CRC byte. |
| 2 | Host latch clears on payload `EOT`/`CAN` | Packet state machine. End only in the gap. Honour `ETB`. |
| 3 | Keyboard gated only inside `PARSE_XMODEM_*` | Gate for the whole Z80→host session, including the ACK gap. |
| 4 | DDC wait while Z80 is live. `pulseZ80Reset` does not flush | Hold `/RESET` across DDC. Flush ACIA while held. |
| 5 | Trailing `acia.tx` INT pulse never runs | Parentheses: `not (acia_config & mask)`. |
| 6 | Dual VGA cursor. BS at column 0 wipes the first cell | WMF is master. Sync overlay after WMF ops. Skip BS-space-BS at column 0. |

Until 1–3 have a live transfer check, treat XMODEM as a console filter, not a proven pipe. Next after text RC commit: live XMODEM send/receive.

## Current tree (staged, 2026-09-12)

Baseline `ee84231`. Cuts re-applied one at a time on a working console. Wait pair unchanged.

| # | Now |
|---|-----|
| 1 | Opaque `z80XmTrail`. In tree. Console checked. No live XMODEM check. |
| 2 | `hostXm` packet machine. In tree. Console checked. |
| 3 | `z80XmSess` gates the ACK gap. In tree. Console checked. |
| 4 | **Not in tree.** 1 ms `pulseZ80Reset` only. DDC still while the 8085 is live. |
| 5 | Trailing `acia.tx` pulse uses `not (config & mask)`. In tree. Console checked. |
| 6 | `syncCurs`. Idle BS-space-BS only if column > 0. No prompt-width guess. In tree. Console checked. |

Also in tree: text-only product top (no DIAG, no VECTORJET link). Compile `openspin -L src`.

## Bundle attempt (2026-09-11), then reverted, then bisected

These edits went into the index and onto EEPROM. They broke the CP/M console (`A>` then `AA` then a BS-space-BS storm). The working pre-review `ux_module.spin` was recovered from dangling blob `8188529d` and restored. Broken copy parked outside the tree as `ux_module_shipfix.spin` in the session directory. ACIA trailing INT parens were also reverted.

Do not re-apply this set as a bundle. Bisect one item at a time against the working console.

| # | What was in the broken bundle |
|---|---|
| 1 | Opaque `z80XmTrail` (1 or 2). No CRC-lo sniff. |
| 2 | `hostXm` OFF/GAP/BLK/NBLK/DATA/TRAIL. |
| 3 | `z80XmSess` gated the keyboard across the ACK gap. |
| 4 | Tried 1 s `/RESET` hold and `masterReset` on release. Both failed. Left a 1 ms pulse. |
| 5 | Trailing `acia.tx` INT pulse with parentheses. |
| 6 | `syncCurs` after WMF. VGA BS-space-BS only if column > 0. |

Not done (out of ship scope): Unix LF-only, CSI `z80N` cap, `termToZ80` drop on `$03`, `term.start` 250 ms comment, unused APIs.
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

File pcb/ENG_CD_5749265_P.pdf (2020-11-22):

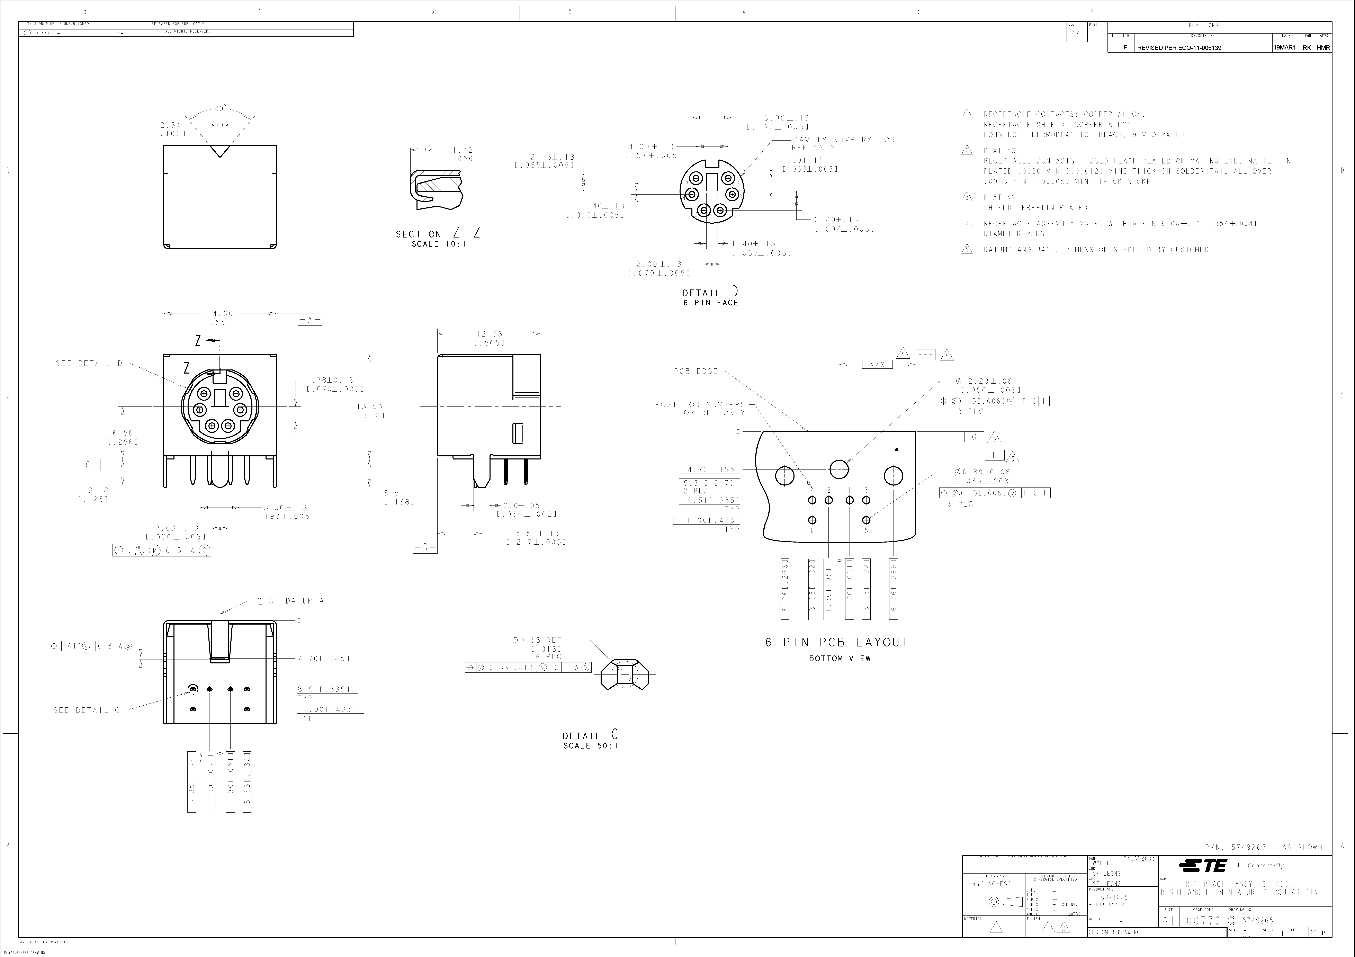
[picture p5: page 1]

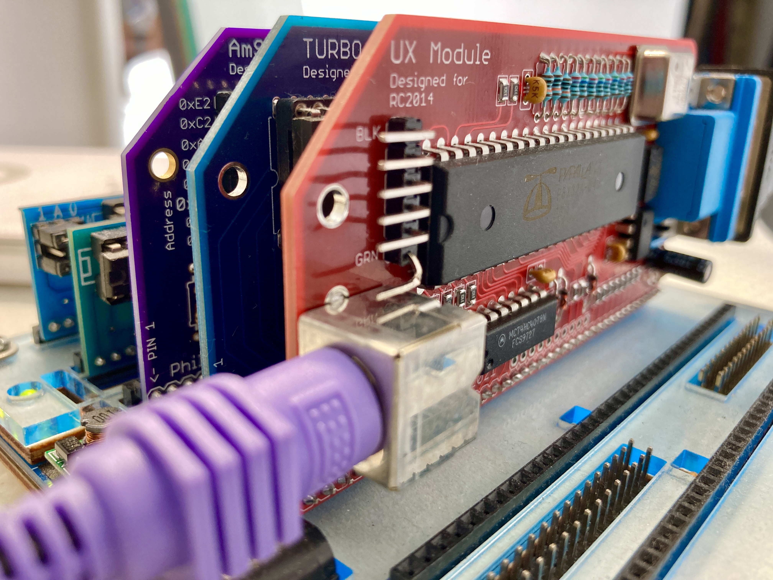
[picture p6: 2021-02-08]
docs/RC2014_UX_MODULE_DTR.JPG

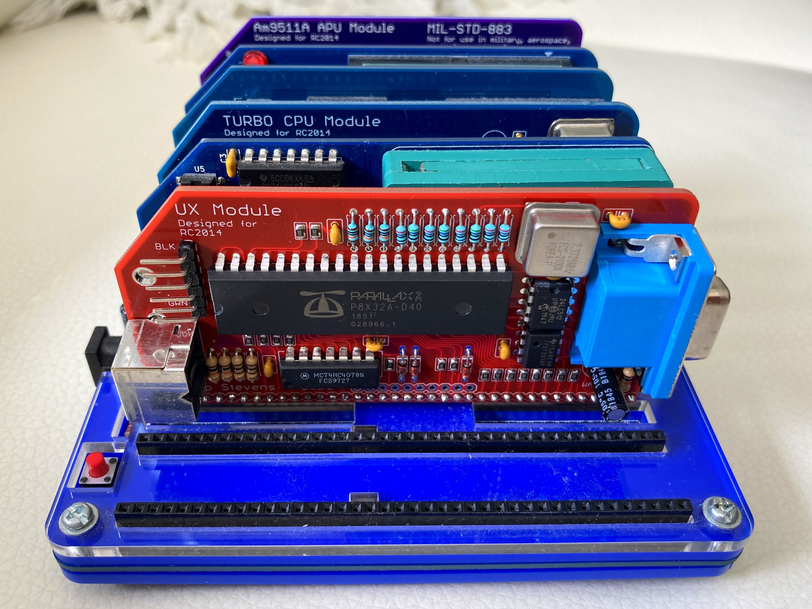
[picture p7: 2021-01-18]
docs/RC2014_UX_MODULE_PRODUCTION.JPG

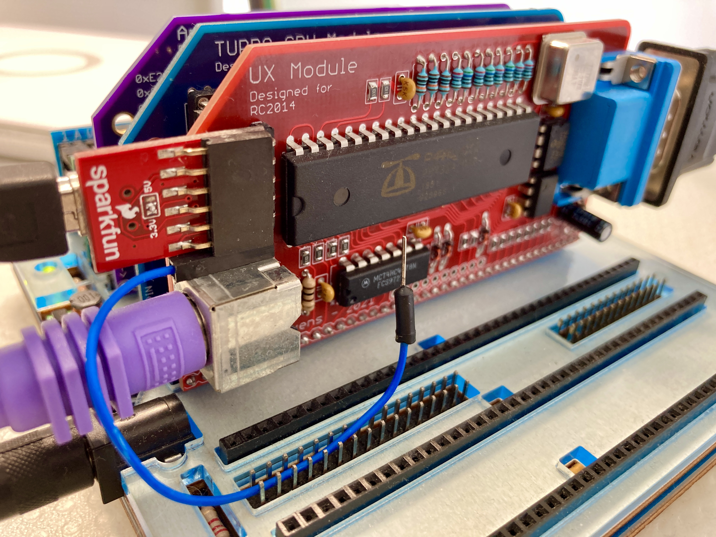
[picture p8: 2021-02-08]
docs/RC2014_UX_MODULE_RUN_STATE.JPG

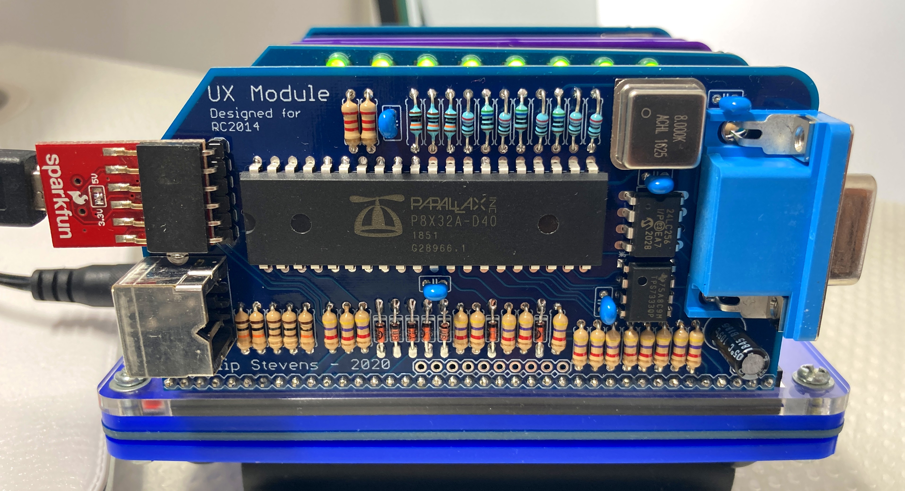
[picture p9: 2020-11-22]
docs/RC2014_UX_MODULE_PROTOTYPE.JPG

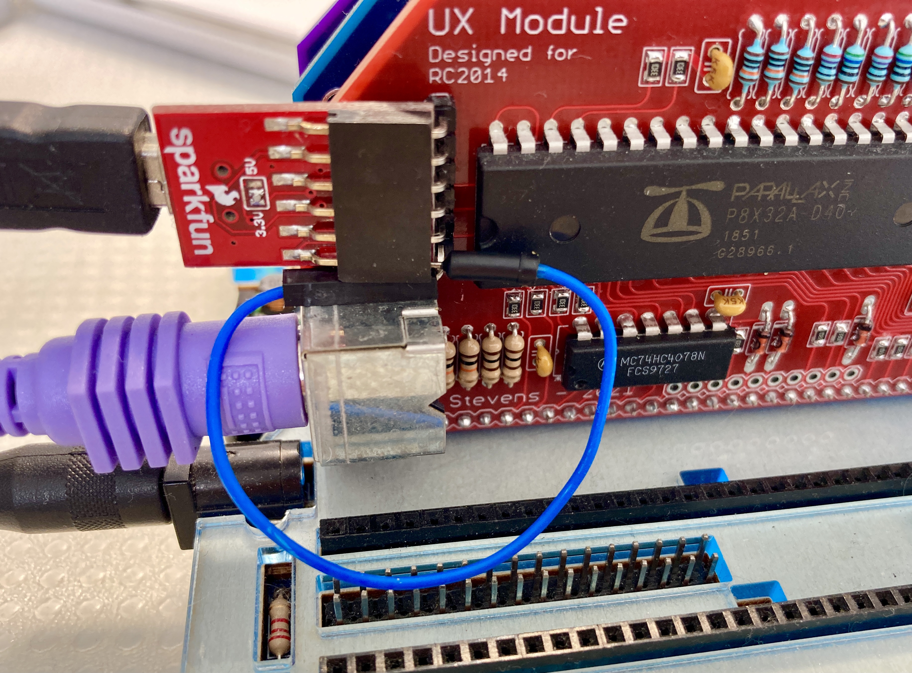
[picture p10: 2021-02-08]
docs/RC2014_UX_MODULE_PROGAM_STATE.JPG

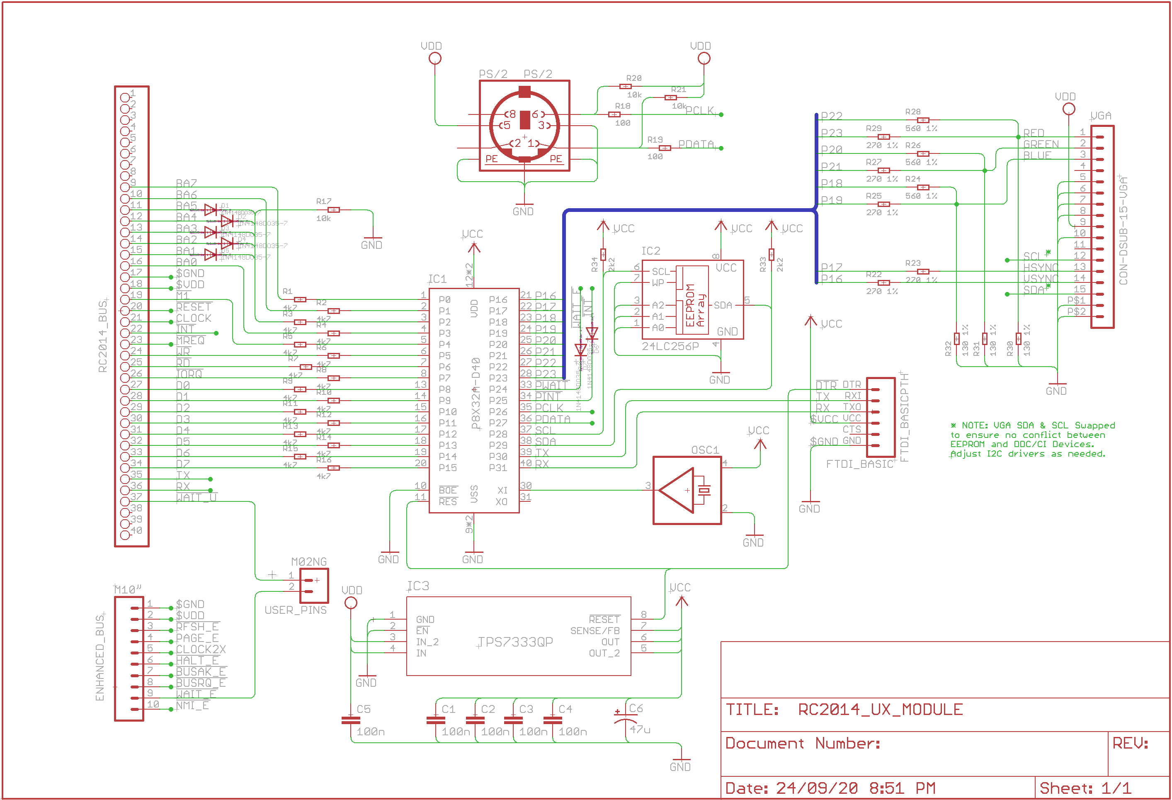
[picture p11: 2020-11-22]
pcb/prototype/RC2014 UX MODULE SCH.png

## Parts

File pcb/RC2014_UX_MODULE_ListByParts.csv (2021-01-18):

Part | Value | Package | Description | Part Num
C1 | 100n | C025-025X050 | CAPACITOR, European symbol | *
C2 | 100n | C025-025X050 | CAPACITOR, European symbol | *
C3 | 100n | C025-025X050 | CAPACITOR, European symbol | *
C4 | 100n | C025-025X050 | CAPACITOR, European symbol | *
C5 | 100n | C025-025X050 | CAPACITOR, European symbol | *
C6 | 100n | C025-025X050 | CAPACITOR, European symbol | *
C7 | 100p | C0805 | CAPACITOR, European symbol | *
C8 | 100p | C0805 | CAPACITOR, European symbol | *
C9 | 100p | C0805 | CAPACITOR, European symbol | *
C10 | 100p | C0805 | CAPACITOR, European symbol | *
C11 | 100p | C0805 | CAPACITOR, European symbol | *
C12 | 200p | C0805 | CAPACITOR, European symbol | *
C13 | 200p | C0805 | CAPACITOR, European symbol | *
C14 | 100p | C0805 | CAPACITOR, European symbol | *
C15 | 100p | C0805 | CAPACITOR, European symbol | *
C16 | 200p | C0805 | CAPACITOR, European symbol | *
C17 | 100u | CPOL-RADIAL-100UF-25V | Capacitor Polarized | *
D1 | 1N4148DO35-7 | DO35-7 | DIODE | *
D2 | 1N4148DO35-7 | DO35-7 | DIODE | *
D3 | 1N4148DO35-7 | DO35-7 | DIODE | *
FTDI_BASIC | FTDI_BASICPTH | FTDI_BASIC | FTDI Basic: 3.3V and 5V | *
IC1 | P8X32A-D40 | DIL40 | 8-Cog Multiprocessor Microcontroller | P8X32A-D40
IC2 | 24LC256P | DIL8 | Serial EEPROM | 24LC256-E/P
IC3 | M74HC4078B1R | DIP254P762X510-14 | 8-INPUT NOR/OR GATE | M74HC4078B1R
IC4 | TPS7333QP | P8_TEX |  | *
OSC1 | 7.3728MHz | DIL08-4 | CRYSTAL RESONATOR | *
PS/2 | PS/2 | M_DIN6 |  | *
R1 | 3k3 | R0805 |  | *
R2 | 3k3 | R0805 |  | *
R3 | 3k3 | R0805 |  | *
R4 | 3k3 | R0805 |  | *
R5 | 3k3 | R0805 |  | *
R7 | 3k3 | R0805 |  | *
R8 | 3k3 | R0805 |  | *
R9 | 3k3 | R0805 |  | *
R10 | 3k3 | R0805 |  | *
R11 | 3k3 | R0805 |  | *
R12 | 3k3 | R0805 |  | *
R13 | 3k3 | R0805 |  | *
R14 | 3k3 | R0805 |  | *
R15 | 3k3 | R0805 |  | *
R16 | 3k3 | R0805 |  | *
R17 | 10k | R0207_7 |  | *
R18 | 100 | R0207_7 |  | *
R19 | 100 | R0207_7 |  | *
R20 | 10k | R0207_7 |  | *
R21 | 10k | R0207_7 |  | *
R22 | 270 1% | R0207_7 |  | *
R23 | 270 1% | R0207_7 |  | *
R24 | 560 1% | R0207_7 |  | *
R25 | 270 1% | R0207_7 |  | *
R26 | 560 1% | R0207_7 |  | *
R27 | 270 1% | R0207_7 |  | *
R28 | 560 1% | R0207_7 |  | *
R29 | 270 1% | R0207_7 |  | *
R30 | 130 1% | R0207_7 |  | *
R31 | 130 1% | R0207_7 |  | *
R32 | 130 1% | R0207_7 |  | *
R33 | 3k3 | R0805 |  | *
R34 | 3k3 | R0805 |  | *
VGA | CON-DSUB-15-VGA | 181-015-212-171 | NORCOMP's High Density 90° PC Mount D-Sub Connector | *

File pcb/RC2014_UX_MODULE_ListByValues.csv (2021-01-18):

Qty | Value | Part Num | Package | Parts
3 | 1N4148DO35-7 | * | DO35-7 | D1, D2, D3
17 | 3k3 | * | R0805 | R1, R2, R3, R4, R5, R7, R8, R9, R10, R11, R12, R13, R14, R15, R16, R33, R34
1 | 7.3728MHz (5MHz) | * | DIL08-4 | OSC1
7 | 100p | * | C0805 | C7, C8, C9, C10, C11, C14, C15
3 | 200p | * | C0805 | C12, C13, C16
3 | 10k | * | R0207_7 | R17, R20, R21
1 | 24LC256P | 24LC256-E/P | DIL8 | IC2
2 | 100 | * | R0207_7 | R18, R19
6 | 100n | * | C025-025X050 | C1, C2, C3, C4, C5, C6
1 | 100u | * | CPOL-RADIAL-100UF-25V | C17
3 | 130 1% | * | R0207_7 | R30, R31, R32
5 | 270 1% | * | R0207_7 | R22, R23, R25, R27, R29
3 | 560 1% | * | R0207_7 | R24, R26, R28
1 | CON-DSUB-15-VGA | * | 181-015-212-171 | VGA
1 | FTDI_BASICPTH | * | FTDI_BASIC | FTDI_BASIC
1 | M74HC4078B1R | M74HC4078B1R | DIP254P762X510-14 | IC3
1 | P8X32A-D40 | P8X32A-D40 | DIL40 | IC1
1 | PS/2 | * | M_DIN6 | PS/2
1 | TPS7333QP | * | P8_TEX | IC4

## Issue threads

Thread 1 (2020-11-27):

Graphics Support via VJET

feilipu, 2020-11-27:
Opening a thread on VJET graphics support for @Wuerfel21.

feilipu, 2020-11-27:
> You mean the VJET polygon drawing stuff? Yes, it is quite similar in concept to the FTDI EVE hardware, just significantly less powerful - with the 4 rasterizer cogs @80MHz I usually use, that is. 117 MHz is a good bit faster and you may be able to use 5 or 6 cogs. Also, the display list doesn't contain triangles/lines/polygons per se, it contains "trapezoid stacks", essentially a representation of a y-monotonous polygon as set of trapezoids defined by height and left/right slope. If you've ever written a triangle/poly fill algorithm, you probably understand what I mean. There's some computation involved in generating these from a polygon (triangles as a special case are quite simple though).

Thanks I've kept 3 base addresses free in the UX Module design. 0x80 is for the ACIA emulation so it will work with the standard RC2014 software. Another is to separate the serial Tx/Rx onto another "TTY" port.

The final base address is to build a graphics device. It might be TMS9918 like, or better I'd prefer it to be based on VJET like solution. Ideally it would work to the same VGA memory as the HiRes VGA driver. A bit like a graphic overlay.

> Running both hires text and any sort of graphics at the same time is just not going to happen. However, if you're OK with switching between highres text and lowres text + graphics, it'll work out. One cog is needed to drive the VGA from line buffers, leaving 3 render cogs. 3 might be ok at 108 MHz, but 4 is really the sweet spot. If we can get rid of that pesky keyboard cog that spends of it's time doing absolutely nothing, that'd be 4 render cogs. Just need to find some other place to stuff the PS/2 bitbanging and then the scancode conversion and stuff can be just be done in Spin.

> Anyways, the terminal emulation can be incorporated into the graphics rendering by simply placing some text commands into the display list that point into the terminal buffer. Can be an overlay or an underlay depending on where the commands are inserted. However, the code handling the terminal buffer will need to be adjusted for smaller screen size. VJET as-is runs in 256x238 with non-square pixels. Could be bumped to 256x240 (The reason it's 238 is because I couldn't get my code to do 240 lines and it literally makes zero difference on TV due to overscan, so I didn't bother fixing it) If we assume most of that isn't overscanned, you can reasonably get 40x28 characters (each character being 6x8, TMS9918 style). (However, I think to actually render a screen full of text, it will need 4 render cogs.) Also, it'd really help if the terminal emulation would automagically zero-terminate each line of display memory instead of just having spaces till the end.

I'm actually more inclined to close the serial interface cog (at least when development is done) as a preference, as the keyboard needs to be "fast" (in its own cog?) to allow gaming control.

And, absolutely no problem to make the video modal (lowres text + graphics) and highres.

I'm going to focus on getting the highres text working, as that's just a matter of matching terminal emulation codes and keyboard scanning. This part is critical for CP/M and general usage. The graphics part is a "stretch"

I'd like to have a command processor, so that the nice GL language can exist. It might be useful without the Z80 bus interface for other people too, so I wouldn't want the Z80 to know too much.

The EVE hardware has 32bit GL commands which are executed out of an on chip buffer. The command buffer is rendered line by line for display. I'm not sure but, I'm imagining a cog rendering a slice of the screen, and then displaying it. With 4 cogs sharing the render / display it would be real dance. It looks like the VJET geometry processing code is quite similar in function.

> Yeah, it is like that a bit, the main difference is that the high-level commands have to be pre-chewed by the geometry code. The display list also has space for temp values in it used to stregnth-reduce some multiplications out of the rendering cogs.

> Adding some macro commands to draw common GUI elements is definitely very easy to do.

> Other thing is: What is filling the display list? Letting the Z80 write it directly would not only be quite slow, but would also require the Z80 code to know about hub RAM layout (and if it messed up, the render cogs will spill their temp values all over and cause a really bad time). So instead it probably should be a command interface. If the bus interface code can just dump whatever data arrives at its port to the Spin code, that could handle generating the display list from commands, similar to the spin interface existing VJET geometry processing code. Problem with that is that normal spin is kinda slow at doing that. Flexspin compiles to LMM assembler and is a lot faster, but it'll make your code size explode and as such requires careful optimization to fit everything. Also when you use it, you'll find and report a bug every 2 days, it's inevitable :)
I also do think that the geometry code (especially the polygon function) could be optimized more. Or if flexspin is used, anyways, custom inline ASM could also help.

> Yeah closing the serial interface also works (you could even make it an option to leave it running at the expense of reduced rendering cogs) and is very much the easier option. However, do know that moving the keyboard handling somewhere else would not make it measurably slower - the reason it generally is handled in it's own cog is because the keyboard controls the data transfer speed and thus the the pins have to be monitored constantly. Compare to something like a SNES controller, where the speed is controlled entirely by the host - that is generally read once per frame in a simple spin routine.

feilipu, 2020-11-27:
I have put up a video of a "first draft" for the HiRes Text mode.
Excuse the slow Basic programming. I had a Basic language WTF moment.

[User Experience Module for RC2014](https://youtu.be/PydiHBYSWbE)

The UX Module has a major port (0x40, 0x80, 0xC0), and a minor port at one higher. I'm thinking the Major port can be a Command/Status port (like the ACIA), and the Minor port can be for 4x 8bit data.

It would be easy to write Z80 assembly to upload 32-bit longs in LSB->MSB order from the Z80 to Parallax. If the Display Commands were assumed always 32bit, then parsing the command data would become simpler too.

And, If I can dig into the EVE DL Commands a bit more then it might even be possible to replicate them (to some extent).

More when the next PCB is available.

feilipu, 2020-12-09:
I'm still unhappy with the Z80 bus interface solution. Works with a small MS Basic (classic) configuration, but is unreliable with larger configurations.

I've ordered some 200pf capacitors, and digital (pre biased) transistors to experiment some more.

I'm suspicious of the data bus being too slow, because unreliable behaviour seems to be bit flipping (or not settling) on the bus.

I'm also working on VT100 codes. [Anna](https://git.imzadi.de/acn/vt100-games) has collected VT100 games that I'll be "forced" to play for testing.
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
Wuerfel21, 2021-03-05:
[vjet_test.zip](https://github.com/feilipu/ux_module/files/6091539/vjet_test.zip)
Managed to get it to glitch even more consistently.

Wuerfel21, 2021-03-05:
Adding 200 longs of VAR (position wrt other variables doesn't seem to matter) makes it go away, apparently it is not a timing issue, but some sort of memory corruption.
[vjet_test.zip](https://github.com/feilipu/ux_module/files/6091631/vjet_test.zip)

Wuerfel21, 2021-03-05:
Also, messing some more with spin hexagon, I had it freeze on me after a video glitch (with intact display, oddly enough), so definitely memory corruption (there is no feedback from the graphics code that could cause this)

Wuerfel21, 2021-03-05:
Here's an even more corrupted specimen - it just glitched for a couple seconds and then it stayed frozen on this
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

Yeah something's afoot.

feilipu, 2021-03-06:
Yeah ahh. I've played with the last three, and here's what I think is happening. There's a memory corruption issue related to overclocking the hardware. I've got several pieces of the UX Module hardware and they all behave very slightly differently with the same code.

Your last three tests with 4 render cogs have not produced a stable image for any of my Modules, although the third from last option (first version with 4 render cogs) was close. I don't have a 6.25MHz/5MHz crystal around, otherwise I could test the theory that it is hardware related.

For giggles, I've merged your new triangles with 3 render cogs, and it works fine albeit with the same slight glitch previously described (mauve and moving text).

Would it be possible to test that theory that there's a memory write fault (hardware related) by using a render "read" cog to verify by reading back the rendered? Or would it be a Schrodinger's situation where reading back would change the outcome?

Another wild thought is that one/some pieces of the VGA render code that were removed were needed to counter exactly this effect (possibly known issue) in the hardware? Perhaps there needs to be some separation between rendering and displaying?

feilipu, 2021-03-06:
Here's another wild guess. Updating `FPorchStatus`, `VSyncStatus`, and `VSyncStatus` hub memory in the tight video loop sometimes clashes with the render cogs all needing to write hub memory too, so the sync slips (glitch). Using 4 render cogs makes this situation worse (for me anyway), where the display cog may have to wait 23 x 4 cycles to continue, and worse case this could happen 3x per line.

Thoughts?

Wuerfel21, 2021-03-06:
Have you tried any of the precompiled binaries I posted? Just to rule that all out?

> Would it be possible to test that theory that there's a memory write fault (hardware related) by using a render "read" cog to verify by reading back the rendered? Or would it be a Schrodinger's situation where reading back would change the outcome?

I think you're thinking of Heisenberg's uncertainty principle, but I did suspect hardware corruption. This simple synthetic stress test I wrote didn't show any results for me though (if any of the bars change color, something went wrong...):
[stresstest.zip](https://github.com/feilipu/ux_module/files/6095113/stresstest.zip)

> Another wild thought is that one/some pieces of the VGA render code that were removed were needed to counter exactly this effect (possibly known issue) in the hub memory hardware? Perhaps there needs to be some separation between rendering and displaying?

No.

> Also this warning in the original code // For each included copy of this object only one spin interpreter should access it at a time. //. I guess that is for the PUB methods which may not be reentrant?

Idk why that was there, being an object that would have no issue being accessed in parallel. Irrelevant now because the only methods left are start and stop.

>Here's another wild guess. Updating FPorchStatus, VSyncStatus, and VSyncStatus hub memory in the tight video loop sometimes clashes with the render cogs all needing to write hub memory too, so the sync slips (glitch). Using 4 render cogs makes this situation worse (for me anyway), where the display cog may have to wait 23 x 4 cycles to continue, and worse case this could happen 3x per line.

Well, it's not in the hot loop, it happens between lines. If there was a timing issue there, the monitor would loose sync.

feilipu, 2021-03-06:
> Have you tried any of the precompiled binaries I posted? Just to rule that all out?

No, I've failed to upload any
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

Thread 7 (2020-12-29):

ACIA Prop->Z80 becomes borked (buffer issue) when keys are pressed while Z80 has not been reset

Wuerfel21, 2020-12-29:
Seems to buffer each character (such that it comes out when the second next character is put in). I've isolated it to the ACIA Tx stuff, IDK what's up with that.

Wuerfel21, 2020-12-29:
This effect isn't present in my "factory firmware", but does show up there, too, if I press ctrl+alt+del

strange...

If you remember, could you please tell me which comment my "factory firmware" was built from?

Wuerfel21, 2020-12-29:
No wait, I'm just stupid!

It happens to the same extent in both versions and is actually triggered by pressing any keys before resetting the Z80 (on my setup, the Z80 apparently has to be reset every time the UX module boots, even if it was already running, for anything to happen. Similiar story with the ACIA card though, so I guess that's normal)

Wuerfel21, 2020-12-29:
I think I figured the issue out: The receive interrupt is triggered when a byte is entered into the tx_buffer and the Z80 code only reads one byte per interrupt. So any bytes entered while the interrupt isn't being serviced just clog up the buffer.

Wuerfel21, 2020-12-29:
Altough with the way the ACIA emulation has to wait on the bus, I don't really know where else to trigger the interrupt

feilipu, 2020-12-30:
The ACIA emulation has to trigger a new interrupt, if there are [still bytes remaining in the Tx buffer](https://github.com/feilipu/ux_module/blob/main/acia_rc2014.spin#L385).

But, it isn't working totally correctly now, because if two bytes come into the buffer together, then only one interrupt is triggered (or perhaps serviced), and I guess that's because the state machine is very crappy. Need to work on this too.

feilipu, 2021-01-25:
I think this issue is partially fixed in my implementations, but I think it can't be fully fixed using the default ROM.

The issue is that the real ACIA device is double buffered, and the Z80 side needs to check that no new byte has been received during the interrupt processing, and if a new byte has been received it needs to go back to get it. The default MS Basic ROM doesn't do this, nor does it read the overrun flag (which would be another way to fix this).

On the Propeller side it may be possible to fudge an answer by delaying transmission of bytes for a fixed time, but that would slow things down substantially, and still not be a definitive fix.

I've revised [my MS Basic](https://github.com/feilipu/NASCOM_BASIC_4.7/commit/4ea30811e382696399ed06704ddbbe22f8134a9e) and [CP/M-IDE](https://github.com/RC2014Z80/RC2014/commit/6ff29009befe3cb31755104b886b5711c0d345e6) implementations to fix the overrun and it was already properly implemented in [RomWBW](https://github.com/wwarthen/RomWBW/blob/master/Source/HBIOS/acia.asm#L242).

Wuerfel21, 2021-01-26:
I guess a workaround would be to generate another interrupt if the last one hasn't been acknowledged for a while (250ms or so)

feilipu, 2021-02-03:
I've added a `txFlush` that should resolve this issue.

The separate issue of the Prop being too fast for the Z80 with characters has also been handled, but imperfectly for standard firmware.

Closed 2021-02-03.

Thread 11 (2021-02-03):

Attaching a new serial interface reboots the UX Module

feilipu, 2021-02-03:
Attaching a new terminal to `cat` code up to the Z80 causes the UX Module to reboot.

We need this function to upload code to the Z80 without needing to copy/pasta it into the initial open terminal.

Probably this is caused by some kind of Linux side DTR toggling when opening a `/dev/ttyUSB0` connection, but it might be something else.

Wuerfel21, 2021-02-03:
IDK about Linux, but on Windows there is a setting deep in the COM port config dialog for this

feilipu, 2021-02-04:
Will look into Windows, to see whether same issue occurs.

How does text upload work in Windows best? Then I can copy method to test.

Linux side there's many stty configuration options to try, but they are cryptic, not generally perfect, and till now I've not cracked the code.

Need to check into what exactly is happening first though.

feilipu, 2021-02-04:
This is a known problem in Linux (of all varieties), which the Arduino world has been struggling with for years.
https://raspberrypi.stackexchange.com/questions/9695/disable-dtr-on-ttyusb0
In summary the required `-cdtrdsr` option is not implemented, and the `-hupcl` option doesn't really work.
Not sure how this can be fixed at the moment.

feilipu, 2021-02-06:
Dug as deep as I can.
Wrote this based on references, and experimented with variations on the theme.
Nothing works.

```python
import os
import sys
import serial
# import termios

from time import sleep

path = '/dev/ttyUSB0'
baud = 115200

# Disable reset after hangup
# with open(path) as f:
#    attrs = termios.tcgetattr(f)
#    attrs[2] = attrs[2] & ~termios.HUPCL & termios.CLOCAL
#    termios.tcsetattr(f, termios.TCSAFLUSH, attrs)

os.system("stty -F /dev/ttyUSB0 clocal -hupcl")

ser = serial.Serial(path, baud, dsrdtr=False)

# print(ser)

for line in sys.stdin:

    for ch in line:
        ser.write( ch );

    ser.write('\r');
    ser.flush();
    sleep(0.1);

ser.close()
sys.exit()
```

feilipu, 2021-02-08:
Closed with [documentation](https://github.com/feilipu/ux_module/commit/3b8ac09a50e496cf18c369c16778935e791145ac).

Closed 2021-02-08.

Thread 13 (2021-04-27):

Thoughts on first use.

feilipu, 2021-04-27:
Hi there. Glad it has arrived safely.

> According to the schematic, the RX/TX lines of the RC2014 bus are not connected.

It is a bit misleading, as in Eagle there is no need to actually join the traces if the segments have the same name, but the RX/TX lines on the UX module are connected to the RC2014 backplane lines.

If you're using two serial devices (of any type, not just the UX Module) then you'll run into trouble if you don't disable all but one of them from using the backplane.

> I will try to use one SIO/2 module together with the UX module. Are there any problems?

None to my knowledge. I've been using this with my system for the past few months. When you build the UX Module firmware, just remember to set the [UX Module to be on port `0x40`](https://github.com/feilipu/ux_module/blob/main/src/ux_module.spin#L123) so that it doesn't conflict with the SIO Module on `0x80`, and straighten the RX/TX pins on either the UX Module or the SIO Module.

Also, note the [issue with DTR toggling](https://github.com/feilipu/ux_module/issues/11) when plugging into the serial port of the UX Module. This causes the Propeller MCU (and therefore the UX interface) to reboot.

When I'm using my RC2014 using the UX Module serial interface, I've found that it is nice to have a [little python script](https://github.com/feilipu/ux_module/blob/main/serial_dtr.py) to intentionally reboot the Propeller MCU by toggling DTR, without unplugging the FTDI interface.

> Where do I find the “BOOTCON configuration”?

[`BOOTCON` was introduced](https://github.com/wwarthen/RomWBW/commit/33ef02cfc00f6d13d5e8e9ac0608b01067e7d87e) to sort out the issue of which serial device is the boot console. Wayne did it recently to replace another configuration which was not so obvious.

When building your RomWBW, you can add this line to [your configuration file](https://github.com/wwarthen/RomWBW/blob/dev/Source/HBIOS/Config/RCZ80_std.asm).
```
BOOTCON	.SET	2		; Set the boot console to be the 3rd serial device found (for UX Module ACIA)
```
And of course you need to use the dev branch of RomWBW, as these changes haven't been moved out to the main branch yet.

Good luck with your build. Any issues / thoughts, just [raise an issue on Github](https://github.com/feilipu/ux_module/issues), so that others can read along if needed.

Closed 2024-12-01.

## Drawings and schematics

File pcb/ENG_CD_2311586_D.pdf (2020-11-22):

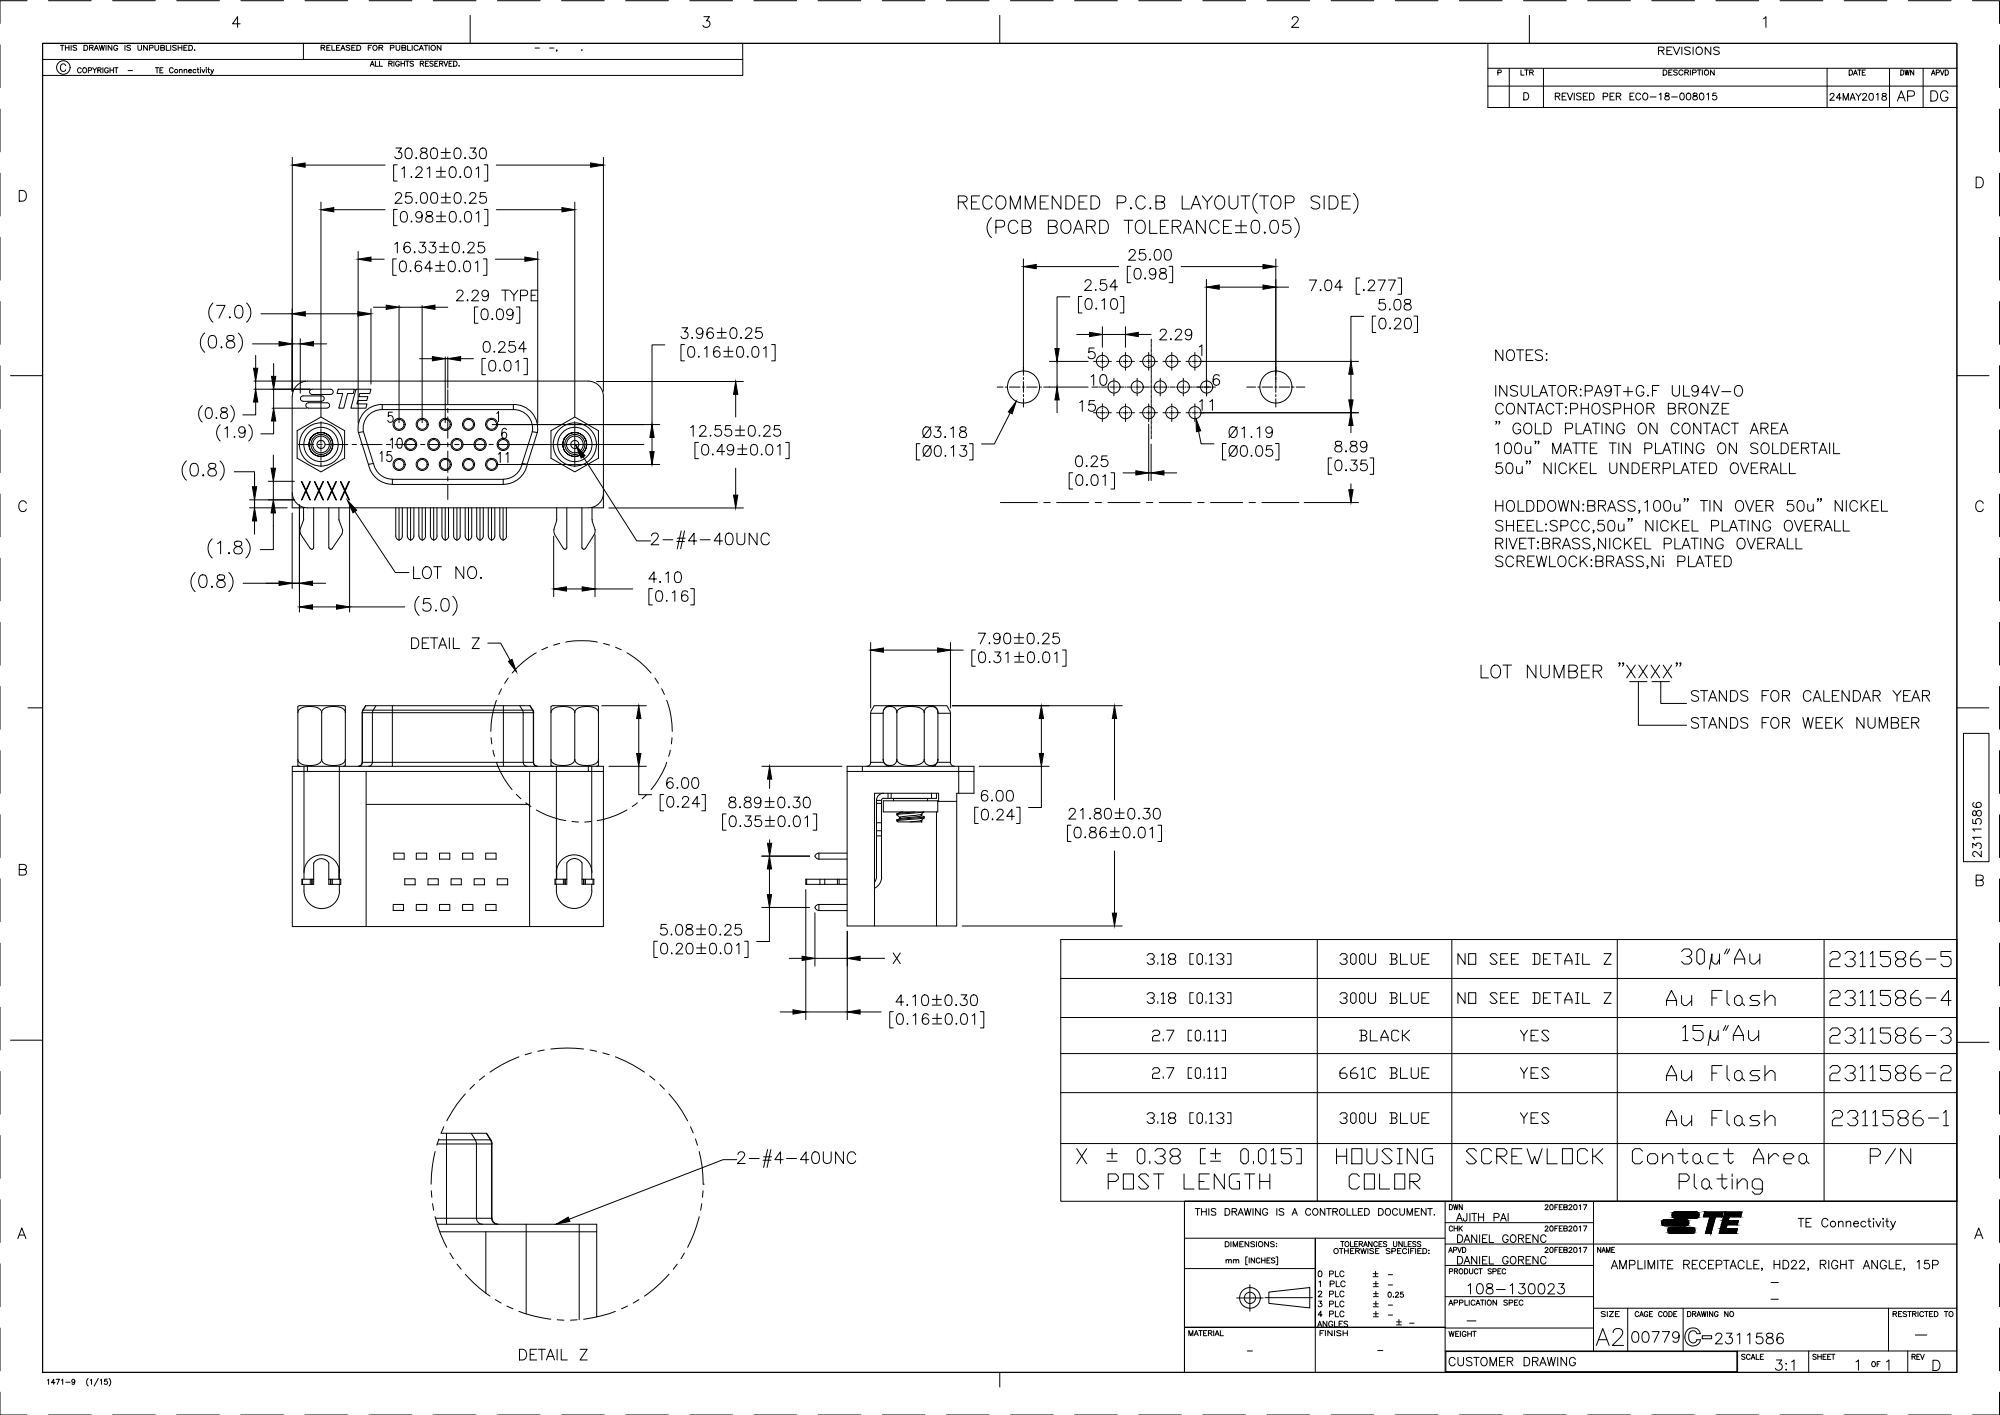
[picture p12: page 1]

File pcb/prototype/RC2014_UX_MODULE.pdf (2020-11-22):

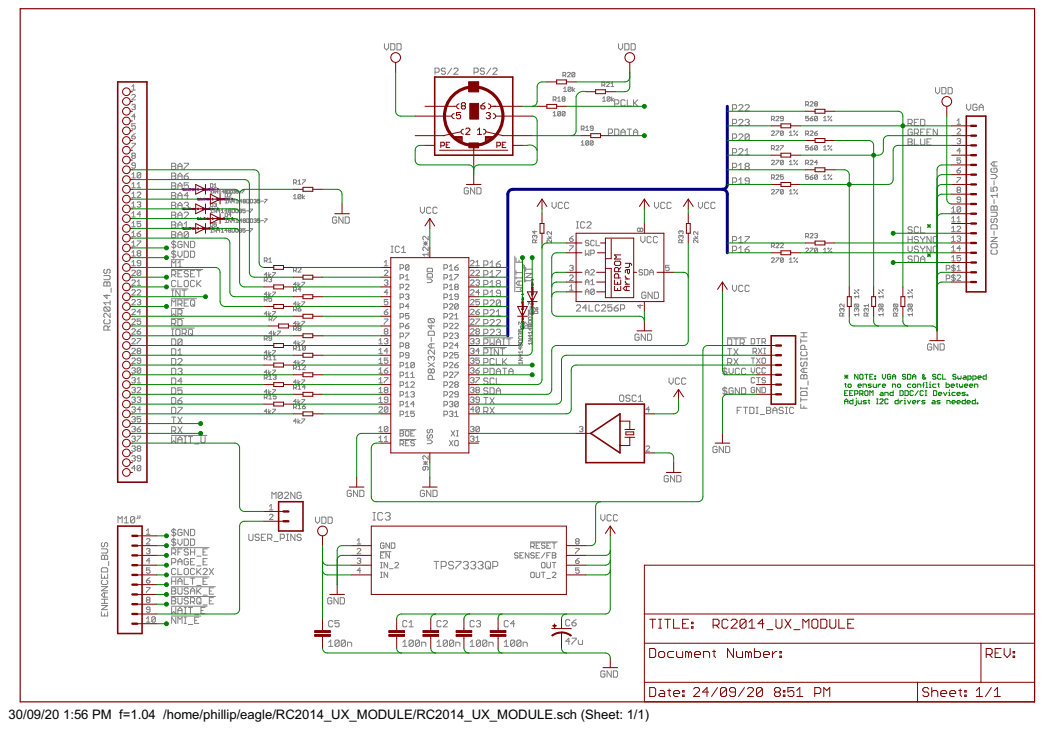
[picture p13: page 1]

30/09/20 1:56 PM f=1.04 /home/phillip/eagle/RC2014_UX_MODULE/RC2014_UX_MODULE.sch (Sheet: 1/1)

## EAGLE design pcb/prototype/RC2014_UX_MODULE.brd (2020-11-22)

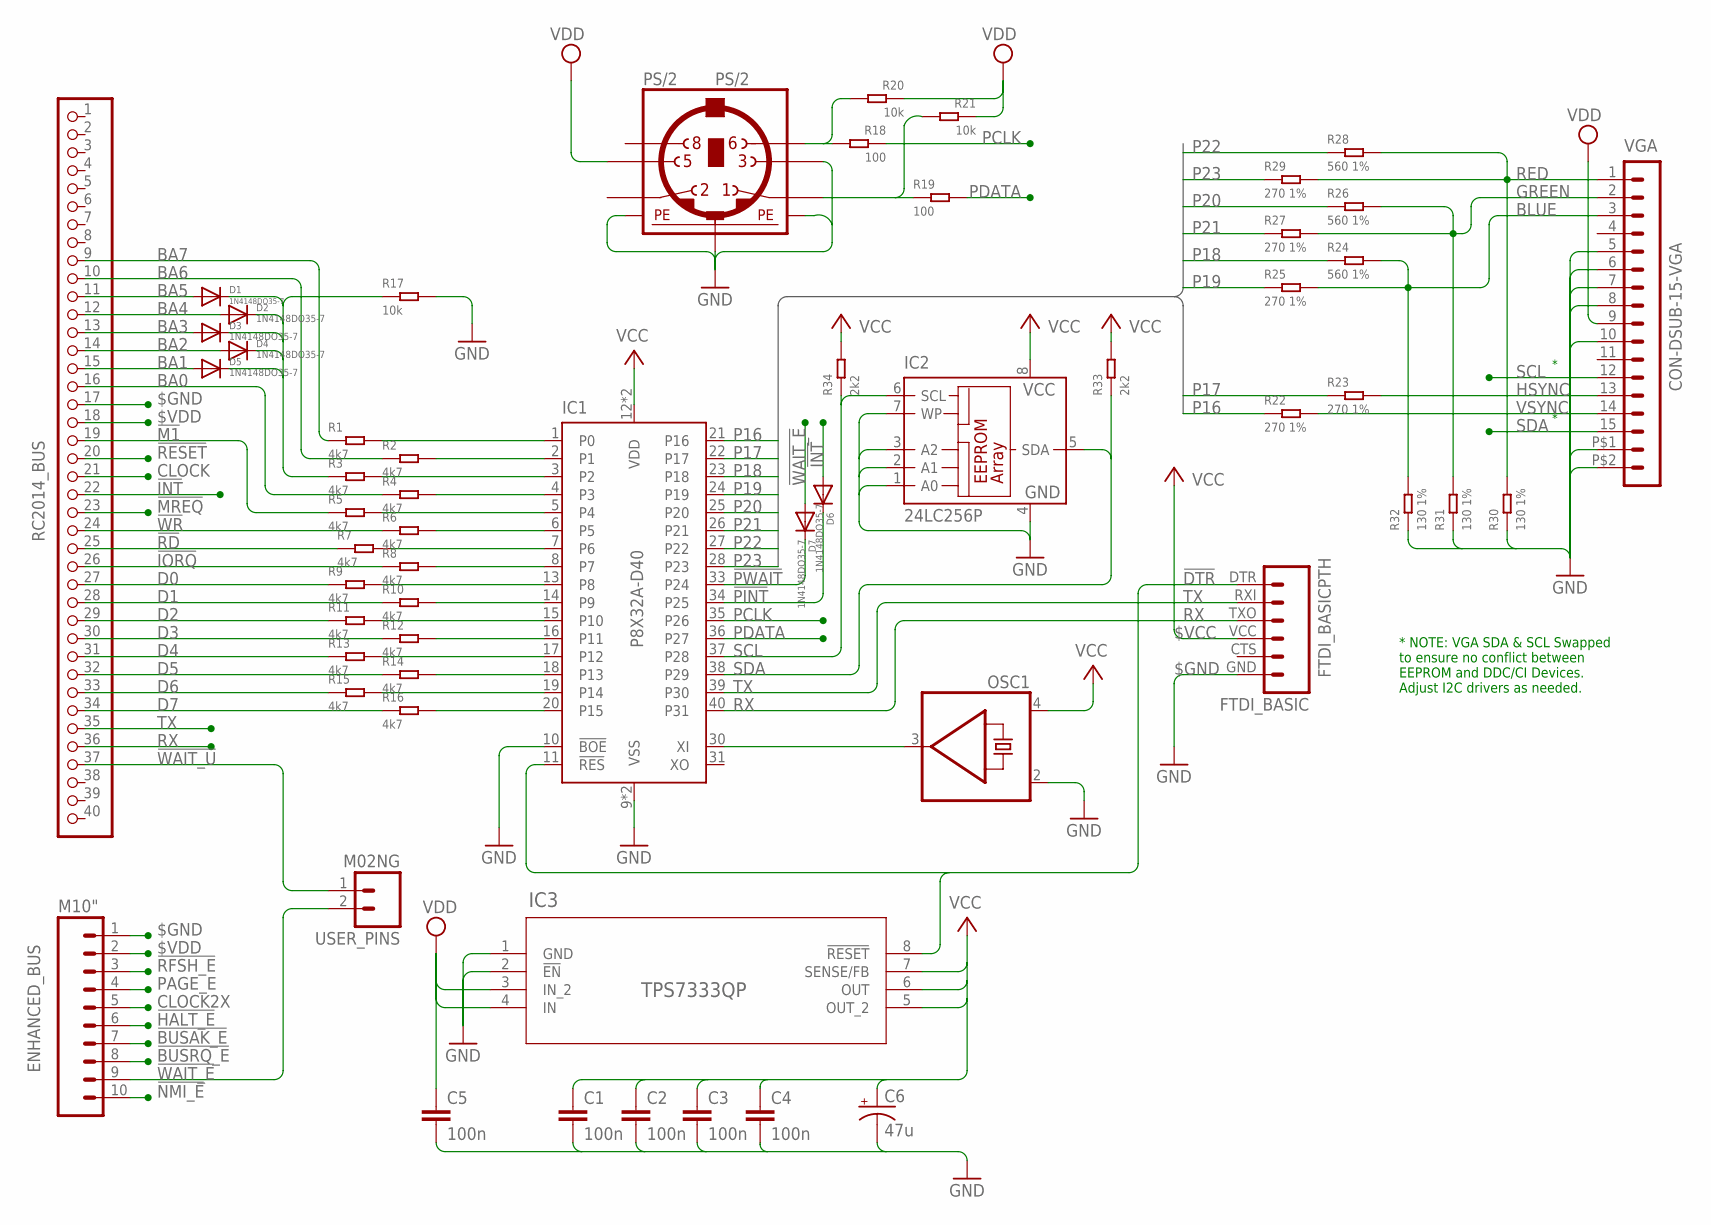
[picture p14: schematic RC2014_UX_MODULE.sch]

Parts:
C1, C2, C3, C4, C5: 100n; C025-025X050
C6: 47u; CPOL-RADIAL-100UF-25V
D1, D2, D3, D4, D5, D6, D7: 1N4148DO35-7; DO35-7
ENHANCED_BUS: M10"; 1X10
FTDI_BASIC: FTDI_BASICPTH; FTDI_BASIC
IC1: P8X32A-D40; DIL40
IC2: 24LC256P; DIL8
IC3: TPS7333QP; P8_TEX
OSC1: SG531; DIL08-4
PS/2: PS/2; M_DIN6
R1, R2, R3, R4, R5, R6, R7, R8, R9, R10, R11, R12, R13, R14, R15, R16: 4k7; R0207_7
R17, R20, R21: 10k; R0207_7
R18, R19: 100; R0207_7
R22, R23, R25, R27, R29: 270 1%; R0207_7
R24, R26, R28: 560 1%; R0207_7
R30, R31, R32: 130 1%; R0207_7
R33, R34: 2k2; R0207_7
RC2014_BUS: RC2014 BUS; 1X40
USER_PINS: M02NG; 1X02
VGA: CON-DSUB-15-VGA; 181-015-212-171

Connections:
!BUSAK_E: ENHANCED_BUS.7
!BUSRQ_E: ENHANCED_BUS.8
!DTR: FTDI_BASIC.DTR (1), IC1.11 (!RES), IC3.8 (!RESET)
!HALT_E: ENHANCED_BUS.6
!INT: D6.A, RC2014_BUS.22
!IORQ: R8.1, RC2014_BUS.26
!M1: R5.1, RC2014_BUS.19
!MREQ: RC2014_BUS.23
!NMI_E: ENHANCED_BUS.10
!PINT: D6.C, IC1.34 (P25)
!PWAIT: D7.C, IC1.33 (P24)
!RD: R7.1, RC2014_BUS.25
!RESET: RC2014_BUS.20
!RFSH_E: ENHANCED_BUS.3
!WAIT_E: D7.A, ENHANCED_BUS.9, USER_PINS.2
!WAIT_U: RC2014_BUS.37, USER_PINS.1
!WR: R6.1, RC2014_BUS.24
$GND: C1.2, C2.2, C3.2, C4.2, C5.2, C6.2 (-), ENHANCED_BUS.1, FTDI_BASIC.GND (6), IC1.9 (VSS), IC1.10 (!BOE), IC1.29 (VSS), IC2.1 (A0), IC2.2 (A1), IC2.3 (A2), IC2.4 (GND), IC2.7 (WP), IC3.1 (GND), IC3.2 (!EN), OSC1.2 (GND), PS/2.3, PS/2.SH1 (PE1), PS/2.SH2 (PE2), PS/2.SH3 (PE3), R17.2, R30.1, R31.1, R32.1, RC2014_BUS.17, VGA.5, VGA.6, VGA.7, VGA.8, VGA.10, VGA.P$1 (16), VGA.P$2 (17)
$VCC: C1.1, C2.1, C3.1, C4.1, C6.1 (+), FTDI_BASIC.VCC (4), IC1.12 (VDD), IC1.32 (VDD), IC2.8 (VCC), IC3.5 (OUT_2), IC3.6 (OUT), IC3.7 (SENSE/FB), OSC1.4 (VCC), R33.2, R34.2
$VDD: C5.1, ENHANCED_BUS.2, IC3.3 (IN_2), IC3.4 (IN), PS/2.5, R20.1, R21.1, RC2014_BUS.18, VGA.9
BA0: R4.1, RC2014_BUS.16
BA1: D5.A, RC2014_BUS.15
BA2: D4.A, RC2014_BUS.14
BA3: D3.A, RC2014_BUS.13
BA4: D2.A, RC2014_BUS.12
BA5: D1.A, RC2014_BUS.11
BA6: R2.1, RC2014_BUS.10
BA7: R1.1, RC2014_BUS.9
BLUE: R24.2, R25.2, R32.2, VGA.3
CLOCK: RC2014_BUS.21
CLOCK2X: ENHANCED_BUS.5
D0: R9.1, RC2014_BUS.27
D1: R10.1, RC2014_BUS.28
D2: R11.1, RC2014_BUS.29
D3: R12.1, RC2014_BUS.30
D4: R13.1, RC2014_BUS.31
D5: R14.1, RC2014_BUS.32
D6: R15.1, RC2014_BUS.33
D7: R16.1, RC2014_BUS.34
GREEN: R26.2, R27.2, R31.2, VGA.2
HSYNC: R23.2, VGA.13
KCLK: PS/2.6, R18.2, R20.2
KDATA: PS/2.1, R19.1, R21.2
unnamed: IC1.13 (P8), R9.2
unnamed: IC1.14 (P9), R10.2
unnamed: IC1.15 (P10), R11.2
unnamed: IC1.16 (P11), R12.2
unnamed: IC1.17 (P12), R13.2
unnamed: IC1.18 (P13), R14.2
unnamed: IC1.19 (P14), R15.2
unnamed: IC1.20 (P15), R16.2
unnamed: IC1.8 (P7), R8.2
unnamed: IC1.7 (P6), R7.2
unnamed: IC1.6 (P5), R6.2
unnamed: IC1.5 (P4), R5.2
unnamed: IC1.4 (P3), R4.2
unnamed: IC1.3 (P2), R3.2
unnamed: IC1.2 (P1), R2.2
unnamed: IC1.1 (P0), R1.2
unnamed: D1.C, D2.C, D3.C, D4.C, D5.C, R3.1, R17.1
unnamed: IC1.30 (XI), OSC1.3 (OUT)
P16: IC1.21 (P16), R22.1
P17: IC1.22 (P17), R23.1
P18: IC1.23 (P18), R24.1
P19: IC1.24 (P19), R25.1
P20: IC1.25 (P20), R26.1
P21: IC1.26 (P21), R27.1
P22: IC1.27 (P22), R28.1
P23: IC1.28 (P23), R29.1
PAGE_E: ENHANCED_BUS.4
PCLK: IC1.35 (P26), R18.1
PDATA: IC1.36 (P27), R19.2
RED: R28.2, R29.2, R30.2, VGA.1
RX: FTDI_BASIC.TXO (3), IC1.40 (P31), RC2014_BUS.36
SCL: IC1.37 (P28), IC2.6 (SCL), R34.1, VGA.12
SDA: IC1.38 (P29), IC2.5 (SDA), R33.1, VGA.15
TX: FTDI_BASIC.RXI (2), IC1.39 (P30), RC2014_BUS.35
VSYNC: R22.2, VGA.14

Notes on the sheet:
* NOTE: VGA SDA & SCL Swapped to ensure no conflict between EEPROM and DDC/CI Devices. Adjust I2C drivers as needed.

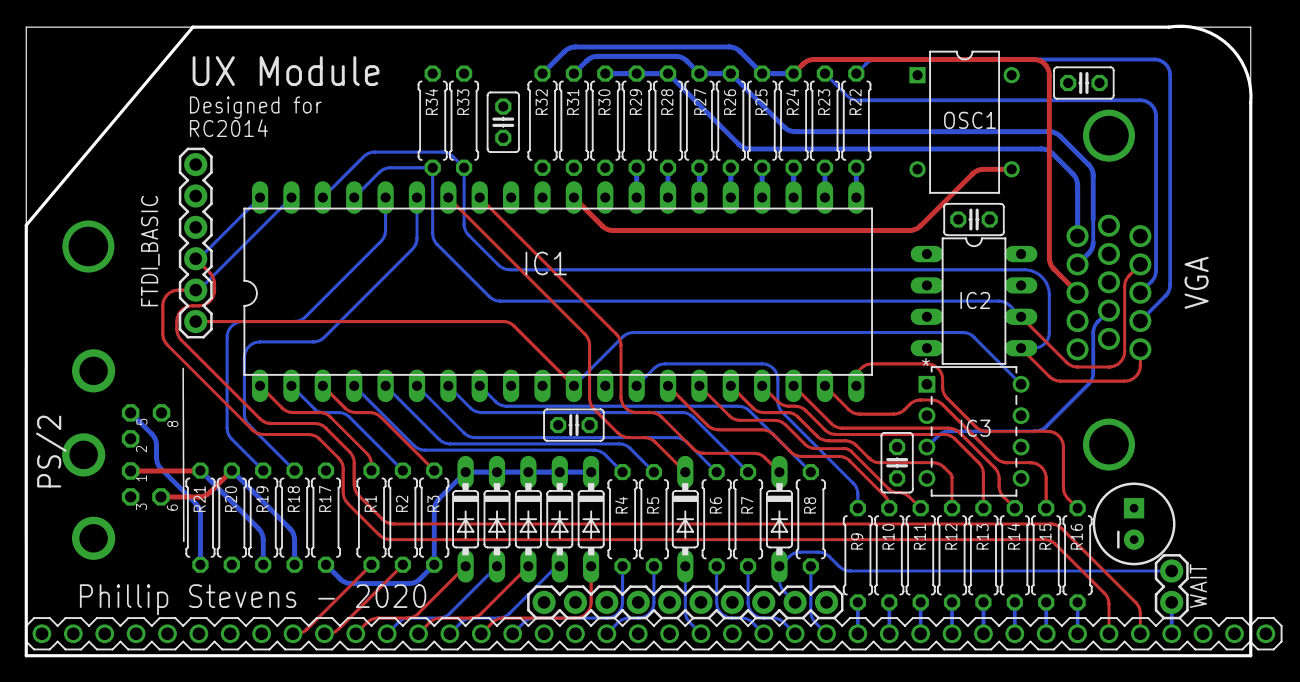
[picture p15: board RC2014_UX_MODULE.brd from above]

Board: 4 copper layers, 99.1 x 50.9 mm, 57 parts (0 on the bottom side), 68 nets.

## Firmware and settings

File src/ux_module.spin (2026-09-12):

''***************************************
''*  User Experience Module             *
''*  Designed for RC2014                *
''*  Author: Phillip Stevens            *
''*  Copyright (c) 2021                 *
''*  See end of file for licence        *
''***************************************

CON

  _clkmode      = XTAL1 + PLL16X
  _xinfreq      = 7_372_800


CON

  ' import some constants from the ACIA Emulation
  PORT_ROMWBW   = acia#PORT_40                          ' Alternate ACIA base port, when used together with SIO/2 Module on 0x80
  PORT_DEFAULT  = acia#PORT_80                          ' Default ACIA base port
  PORT_VJET     = acia#PORT_C0                          ' reserved Z80 graphics port; not decoded yet


CON

  ' set these constants based on the Propeller VGA hardware
  VGA_BASE_PIN  = 16                                    ' VGA pins 16-23

  ' set these constants based on the Propeller PS/2 hardware
  KBD_DATA_PIN  = 27                                    ' KEYBOARD data pin
  KBD_CLK_PIN   = 26                                    ' KEYBOARD clock pin

  ' DDC I2C pins live in ddc_i2c.spin (P29 SCL, P28 SDA). Boot EEPROM is the swapped pair.

  ' import some constants from the Propeller Window Manager
  VGACOLS       = wmf#VGACOLS
  VGAROWS       = wmf#VGAROWS


CON

  ' ASCII control codes

  ASCII_NULL    = $00                                   ' null character

  ASCII_BELL    = $07                                   ' bell
  ASCII_BS      = $08                                   ' backspace
  ASCII_TAB     = $09                                   ' horizontal tab
  ASCII_LF      = $0A                                   ' line feed
  ASCII_VT      = $0B                                   ' vertical tab
  ASCII_FF      = $0C                                   ' form feed (new page)
  ASCII_CR      = $0D                                   ' carriage return

  ASCII_ESC     = $1B                                   ' escape

  ASCII_SPACE   = $20                                   ' space
  ASCII_HASH    = $23                                   ' #
  ASCII_COMMA   = $2C                                   ' ,
  ASCII_PERIOD  = $2E                                   ' .

  ASCII_SEMI    = $3B                                   ' ;

  ASCII_0       = $30                                   ' 0
  ASCII_9       = $39                                   ' 9

  ASCII_LB      = $5B                                   ' [
  ASCII_RB      = $5D                                   ' ]

  ASCII_DEL     = $7F                                   ' delete

CON

  ' XMODEM control codes

  XMODEM_SOH    = $01                                   ' Start of Header (128-byte packet)
  XMODEM_STX    = $02                                   ' Start of Header (1024-byte packet)
  XMODEM_EOT    = $04                                   ' End of Transmission (passed through as data)
  XMODEM_ACK    = $06                                   ' Acknowledge
  XMODEM_NAK    = $15                                   ' Negative acknowledge
  XMODEM_ETB    = $17                                   ' End of Transmission Block
  XMODEM_CAN    = $18                                   ' Cancel
  XMODEM_C      = $43                                   ' receiver CRC request

  ' Non-blocking Z80 output parser (readZ80). Up to PUMP_LIMIT bytes per call.
  PARSE_IDLE      = 0                                   ' normal stream
  PARSE_ESC       = 1                                   ' saw ESC, waiting for next byte
  PARSE_CSI       = 2                                   ' ESC [ ... collecting n
  PARSE_CSI_M     = 3                                   ' ESC [ n ; ... collecting m
  PARSE_XMODEM_N  = 4                                   ' SOH/STX, waiting packet number
  PARSE_XMODEM_M  = 5                                   ' waiting complemented packet number
  PARSE_XMODEM    = 6                                   ' data bytes (z80Remain)
  PARSE_XMODEM_CS = 7                                   ' opaque trailers (z80XmTrail: 1 checksum, 2 CRC)

  HOST_XM_OFF     = 0                                   ' no host→Z80 XMODEM session
  HOST_XM_GAP     = 1                                   ' between packets: SOH/STX/EOT/ETB/CAN only
  HOST_XM_BLK     = 2
  HOST_XM_NBLK    = 3
  HOST_XM_DATA    = 4
  HOST_XM_TRAIL   = 5

  PUMP_LIMIT      = 16                                  ' max bytes each of kbd / FTDI / ACIA drain per main-loop pass


VAR
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

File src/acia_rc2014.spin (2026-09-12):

''
'' UX Module RC2014 Bus Interface
''
'' ACIA emulation
''
'' Bus wait from 569cd07 (waitpne then waitpeq wr, no Hub between).
'' After /WAIT: wait_pin_high (samples req_master). Hub mailbox is 11 longs.
'' last_rdr in cog RAM. sync_irq composes status on a status read.
'' Spin still pulses DIRA[25] (RIE/TIE). It does not RMW acia_status.
'' No XON/XOFF. PUMP_LIMIT, readZ80 ftdiNeed, hostXmodem.
''
'' Practical 6850: FIFOs stand in for the UART. Clock divide, word select,
'' and Break are not driven. PE, FE, CTS, and DCD stay 0. OVRN is not set
'' on a full TDR write. IRQ is composed on a status read.
''
'' Copyright (c) 2021 Phillip Stevens
''
'' I/O Address line mapping (Production):
''
''             P7  P6  P5  P4  P3  P2  P1  P0
''             x   x   1   1   x   1   x   x
''             |   |   |   |   |   |   |   |
''             |   |   |   |   |   |   |   |
''      /RD ---+   |   |   |   |   |   |   |
''      /WR -------+   |   |   |   |   |   |
''      /RESET --------+   |   |   |   |   |
''      /M1 ---------------+   |   |   |   |
''      A0 --------------------+   |   |   |
''      !(/IORQ|A5|A4|A3|A2|A1) ---+   |   |
''      A6 ----------------------------+   |
''      A7 --------------------------------+
''
''
'' I/O Data line mapping:
''
''             P15 P14 P13 P12 P11 P10 P9  P8
''             x   x   x   x   x   x   x   x
''             |   |   |   |   |   |   |   |
''             |   |   |   |   |   |   |   |
''      D7 ----+   |   |   |   |   |   |   |
''      D6 --------+   |   |   |   |   |   |
''      D5 ------------+   |   |   |   |   |
''      D4 ----------------+   |   |   |   |
''      D3 --------------------+   |   |   |
''      D2 ------------------------+   |   |
''      D1 ----------------------------+   |
''      D0 --------------------------------+
''
''
'' I/O Signal line mapping:
''
''             P25 P24
''             x   x
''             |   |
''             |   |
''      INT ---+   |
''      WAIT ------+
''

CON

  DATA_BASE   =   8                                     'DATA bus is Pin P8 to Pin P15
  DATA_PINS   =   %1111_1111                            '8 bit data bus

  INT_PIN_NUM   = 25                                    'Pins used for output - open collector - behind diodes
  WAIT_PIN_NUM  = 24
  RESET_PIN_NUM = 5

  INT_PIN     =   |< INT_PIN_NUM
  WAIT_PIN    =   |< WAIT_PIN_NUM

  RD_PIN      =   |< 7
  WR_PIN      =   |< 6
  RESET_PIN   =   |< RESET_PIN_NUM
  M1_PIN      =   |< 4

  A0_PIN      =   |< 3
  A5_A1_PINS  =   |< 2                                  'NOR Gated, so will be logic high for Addr Pins 0 including /IORQ
  A6_PIN      =   |< 1
  A7_PIN      =   |< 0

  BUFFER_LENGTH   = 512                                 'Recommended as 64 or higher, but can be 2, 4, 8, 16, 32, 64, 128, 256 or 512.
  BUFFER_MASK     = BUFFER_LENGTH - 1

  MAX_STRING  =   255

CON

  PORT_00     =   A5_A1_PINS
  PORT_01     =   A5_A1_PINS | A0_PIN

  PORT_40     =   A6_PIN | A5_A1_PINS
  PORT_41     =   A6_PIN | A5_A1_PINS | A0_PIN

  PORT_80     =   A7_PIN | A5_A1_PINS
  PORT_81     =   A7_PIN | A5_A1_PINS | A0_PIN

  PORT_C0     =   A7_PIN | A6_PIN | A5_A1_PINS
  PORT_C1     =   A7_PIN | A6_PIN | A5_A1_PINS | A0_PIN

  PORT_MASK   =   A7_PIN | A6_PIN | A5_A1_PINS

  ' ACIA Control Register

  CR_RIE      = |< 7                                    ' Receiving Interrupt Enabled (Z80 view)

  CR_TIX_MASK = |< 6 | |< 5                             ' Mask just the Tx Interrupt relevant bits (CR6,CR5)

  CR_TID_BRK  = |< 6 | |< 5                             ' _RTS low,  Transmitting Interrupt Disabled, BRK on Tx
  CR_TID_RTS1 = |< 6                                    ' _RTS high, Transmitting Interrupt Disabled
  CR_TIE_RTS0 = |< 5                                    ' _RTS low,  Transmitting Interrupt Enabled
  CR_TID_RTS0 = 0                                       ' _RTS low,  Transmitting Interrupt Disabled

  CR_8O1      = |< 4 | |< 3 | |< 2                      ' 8 Bits  Odd Parity 1 Stop Bit
  CR_8E1      = |< 4 | |< 3                             ' 8 Bits Even Parity 1 Stop Bit
  CR_8N1      = |< 4 | |< 2                             ' 8 Bits   No Parity 1 Stop Bit
  CR_8N2      = |< 4                                    ' 8 Bits   No Parity 2 Stop Bits
  CR_7O1      = |< 3 | |< 2                             ' 7 Bits  Odd Parity 1 Stop Bit
  CR_7E1      = |< 3                                    ' 7 Bits Even Parity 1 Stop Bit
  CR_7O2      = |< 2                                    ' 7 Bits  Odd Parity 2 Stop Bits
  CR_7E2      = 0                                       ' 7 Bits Even Parity 2 Stop Bits

  CR_RESET    = |< 1 | |< 0                             ' Master Reset (issue before any other Control word)
  CR_DIV_64   = |< 1                                    ' Divide the Clock by 64 (default value)
  CR_DIV_16   = |< 0                                    ' Divide the Clock by 16
  CR_DIV_01   = 0                                       ' Divide the Clock by 1
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

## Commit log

2020-11-22 Propeller OBEX Sourcecode
2020-11-22 Initial ACIA Commit
    [RC2014_UX_MODULE.brd, RC2014_UX_MODULE.sch]
2020-12-10 stability & screen dimensions
    [acia_rc2014.spin, ux_module.spin]
2020-12-20 revert to diode logic
    [acia_rc2014.spin, ux_module.spin]
2020-12-20 pcb - production
    [RC2014_UX_MODULE.brd, RC2014_UX_MODULE.sch]
2020-12-29 Fix compiling in PropTool (and also memory corruption)
    [acia_rc2014.spin]
2020-12-30 add production board graphics
2020-12-30 add docs to pcb zip
2021-01-18 add BOM files
    [RC2014_UX_MODULE_ListByParts.csv, RC2014_UX_MODULE_ListByValues.csv]
2021-01-18 fix C values in bom
    [RC2014_UX_MODULE_ListByParts.csv, RC2014_UX_MODULE_ListByValues.csv]
2021-02-03 tidy constants and fix ESC
    [hires_text_vga.spin, ux_module.spin]
2021-02-08 serial upload tool - options to avoid DTR toggle
    [serial_tool.py]
2021-02-10 useful fixes from multi_acia
    [acia_rc2014.spin, ux_module.spin]
2021-03-05 lib_vjet - schematic & whitespace
2021-03-14 clumsy off by 1 fixes
    [ux_module.spin]
2021-03-15 XMODEM Tx filtering
2021-04-16 add DTR toggle (UX Module reset) script
    [hires_text_vga.spin]
2021-06-02 wip - flow control
2026-09-10 fix ACIA 6850 flags and document /WAIT loop
    [acia_rc2014.spin]
2026-09-10 fix ACIA upper-level flow control in the main loop
    [acia_rc2014.spin, ux_module.spin]
2026-09-10 restore ACIA and main-loop comments for the new flow
2026-09-10 update skills for ACIA flow and main-loop pump
2026-09-10 fix ACIA status owner, reset policy, and drop XON/XOFF
    [acia_rc2014.spin, ux_module.spin]
2026-09-10 fix ACIA reset races, FTDI RX wrap, and parser stalls
    [acia_rc2014.spin, ux_module.spin]
2026-09-10 fix VECTORJET scanline handshake and add graphics mode hooks
    [ux_module.spin]
2026-09-10 document FT232 load vs CDC console on the Prop Plug header
2026-09-11 working updates with i2c added
2026-09-12 reset ACIA when RC2014 is reset
    [ux-ftdi-relay.py, ux_module.spin]
2026-10-17 record the striped framebuffer as the known-good picture
2026-10-17 record the bring-up hub limit for the framebuffer
2026-10-17 record the framebuffer solution and separate the two demos
2026-10-17 let rc-screen attach to USB CDC or FTDI
2026-10-17 record the framebuffer Hub cost and the line-slice plan
2026-10-20 lib_vjet - clean output, functioning graphics / text switch
2026-10-20 lib-vjet - remove framebuffer build - continue with 8-line scan
2026-10-27 lib-vjet - document the frame path and the object tree

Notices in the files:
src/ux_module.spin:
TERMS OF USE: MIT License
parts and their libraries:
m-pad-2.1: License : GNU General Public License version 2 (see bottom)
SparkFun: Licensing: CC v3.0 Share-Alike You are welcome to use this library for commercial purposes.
